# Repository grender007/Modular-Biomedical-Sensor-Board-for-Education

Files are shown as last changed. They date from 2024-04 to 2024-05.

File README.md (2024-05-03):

# Modular-Biomedical-Sensor-Board-for-Education (MediBrick-2000)
Modular Biomedical Sensor Board for Education (a.k.a. MediBrick-2000), designed for the Department of Biomedical Engineering (BME) of the University of Arizona (UofA). The device currently integrates five different sensor for physiological measurements:

* [Skin Impedance](https://github.com/grender007/Modular-Biomedical-Sensor-Board-for-Education/tree/main/Skin%20Impedance%20Sensor)

* [Temperature](https://github.com/grender007/Modular-Biomedical-Sensor-Board-for-Education/tree/main/Temperature%20Sensor)

* [ECG](https://github.com/grender007/Modular-Biomedical-Sensor-Board-for-Education/tree/main/ECG%20Sensor%20)

* [Pulse Ox ](https://github.com/grender007/Modular-Biomedical-Sensor-Board-for-Education/tree/main/Pulse%20Ox%20Sensor)

* [Digital Stethoscope](https://github.com/grender007/Modular-Biomedical-Sensor-Board-for-Education/tree/main/Sound%20Sensor)

Each one of the folders include the Arduino Code (that also enables wireless communication), the PCB files, and the corresponding insert for the casing.

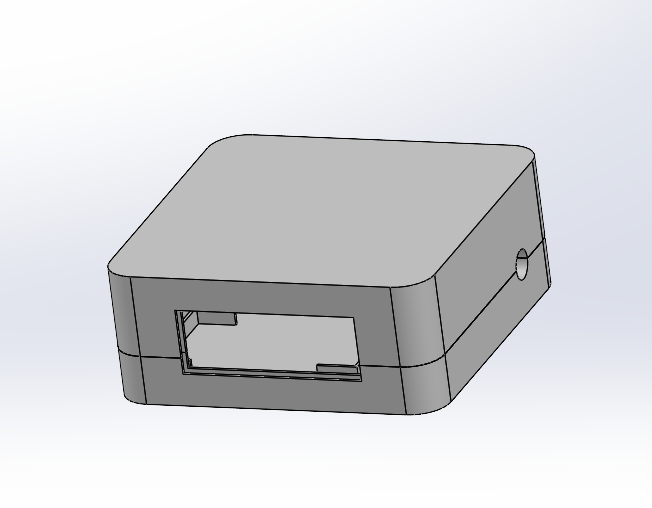
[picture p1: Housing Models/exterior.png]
alt exterior


# Project Point Design
This is a wireless device mainly supported by ESPNow. Each one of the sensors has its own PCB and its own ESP32-S3 (see Arduino Code in any of the sensor folders). The signals are sent to a sixth ESP32-S3, [the receiver](https://github.com/grender007/Modular-Biomedical-Sensor-Board-for-Education/tree/main/ESP32%20Receiver), that simultaneously communicates with the user's computer through the [GUI](https://github.com/grender007/Modular-Biomedical-Sensor-Board-for-Education/tree/main/GUI). The GUI displays the measurements in real time and allows the user to record and save the information.

When not in use, the sensors can be placed on the charging station, where the batteries can be recharged.

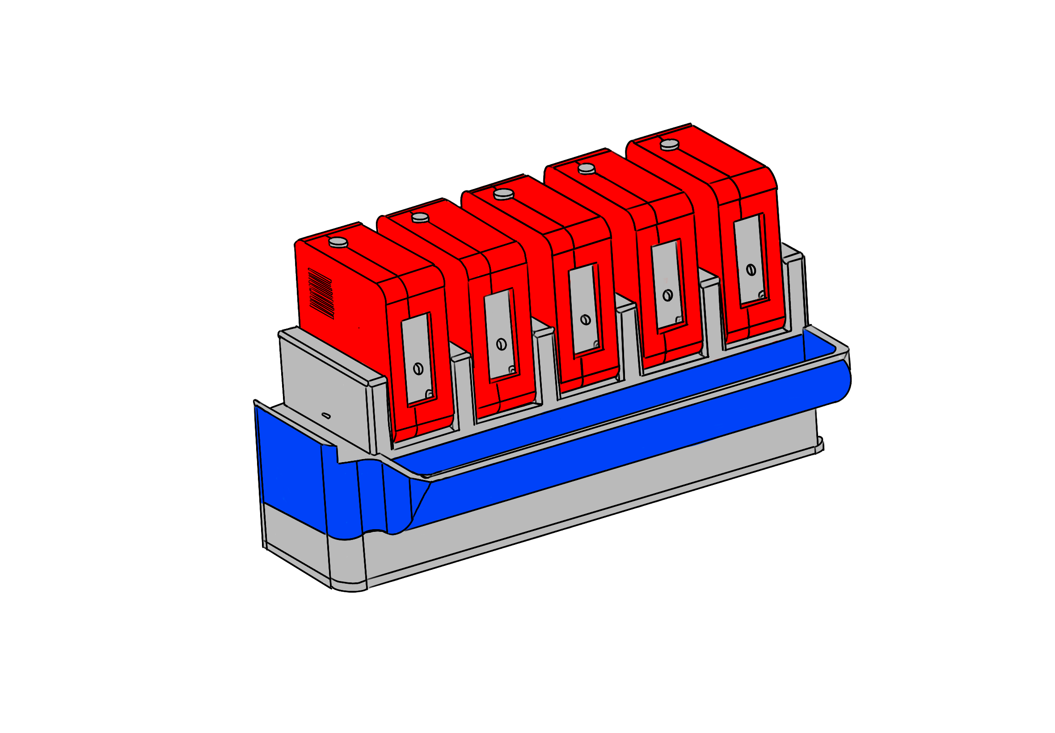
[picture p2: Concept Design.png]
alt Concept


# Sensor Modules
All the sensor modules are meant to be the same, being the only difference each sensor and the PCB that includes the required circuitry (But all the PCB have the same dimension and orientation). Each [sensor module](https://github.com/grender007/Modular-Biomedical-Sensor-Board-for-Education/tree/main/Housing%20Models/Module%20Casing) has different features. It includes an OLED screen that displays the current battery level and a button that allows the deep sleep mode of the ESP32-S3. The casing it is designed for the ESP32-S3 to be powered by a battery and to recharge with a magnetic plug.
All the modules can be placed on the [charging station](https://github.com/grender007/Modular-Biomedical-Sensor-Board-for-Education/tree/main/Housing%20Models/Charging%20Station) to recharge the batteries. Similarly, the receiver includes its own [casing](https://github.com/grender007/Modular-Biomedical-Sensor-Board-for-Education/tree/main/Housing%20Models/Receiver%20Casing).

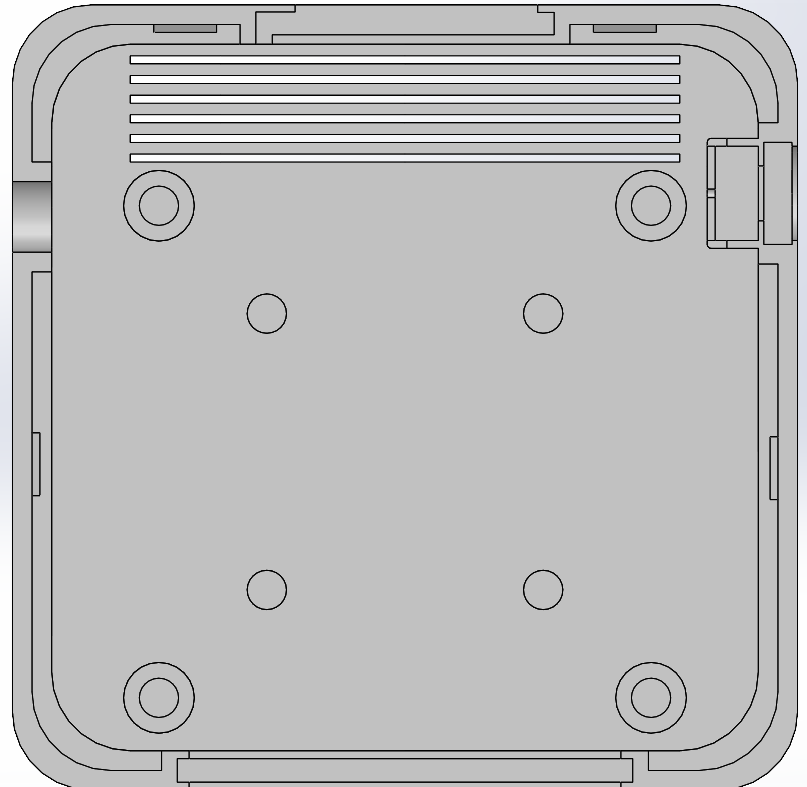
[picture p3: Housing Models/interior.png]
alt interior1


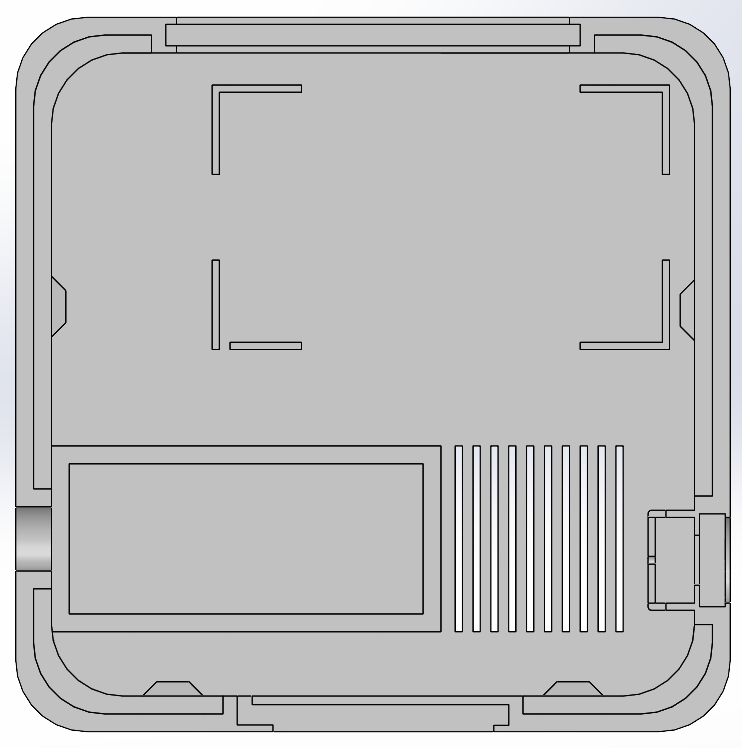
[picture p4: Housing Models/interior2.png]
alt interior2


# Assembly
The detailed asssembly process and the required parts for the device are described in the [Documents folder](https://github.com/grender007/Modular-Biomedical-Sensor-Board-for-Education/tree/main/User%20Manual%20and%20Other%20Documents), as well other related documents like the Technical Data Package (TDP).

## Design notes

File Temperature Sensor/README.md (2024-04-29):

The ESP32 measures the voltage difference from the PCB through Pins A0 and A1, then uses those values to calculate the resistance of the thermistor using Wheatstone Bridge equations. The code then calculates the temperature of the thermistor using the thermistor resistance and constants provided by the manufacturer. Because the thermistor is sensitive to subtle changes, the code then averages 100 of the readings together in order to filter out noise from the signal. The averaged reading is then sent to the receiver and to the OLED at 1 to 2 readings per second.

The code is also built to allow the module to be put into deepsleep, where holding the button on the side of the module for 5 seconds will turn the module off, preventing the module from reading, sending, or receiving data, but does allow the module to still be charged. Pressing the button again will wake the module from deepsleep.

The module can be calibrated using the GUI. Entering resistor values measured while building the device will allow for the sensor to be recalibrated. The sensor module will use the new resistor values until the module is turned off. New values can be sent at any time using the GUI.

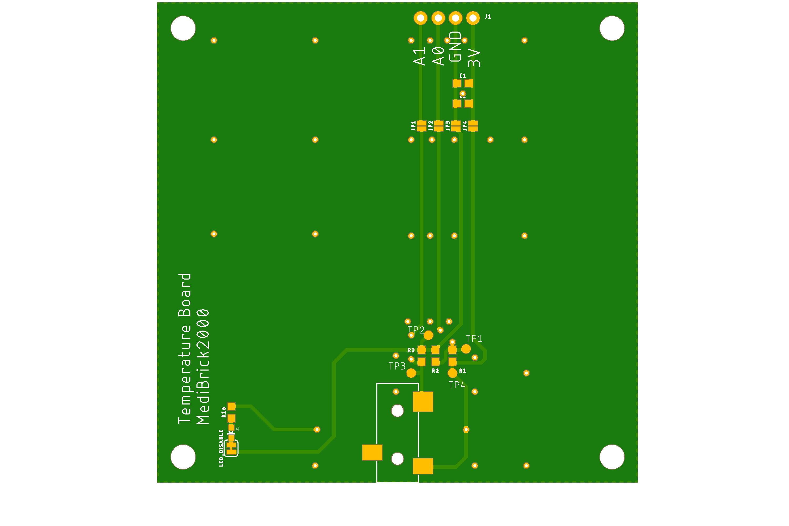
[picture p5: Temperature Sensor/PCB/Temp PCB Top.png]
alt Temp Sensor


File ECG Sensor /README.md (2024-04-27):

This is a description for ECG Sensor. See [Module Casing](https://github.com/grender007/Modular-Biomedical-Sensor-Board-for-Education/tree/main/Housing%20Models/Module%20Casing) for the entire casing design.

The ECG Module takes advantage of the Sparkfun ECG Pre-Amplifier Board. It uses the AD8232 IC to detect the voltage potential of the heart. 

output-onlinepngtools (6)

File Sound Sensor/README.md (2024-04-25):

The Sound Sensor module records the sounds of heartbeats and the lungs. The sensor (electret microphone) is connected to a stethoscope tube, so the user can mimic the functionalities of an "analog" stethoscope. 

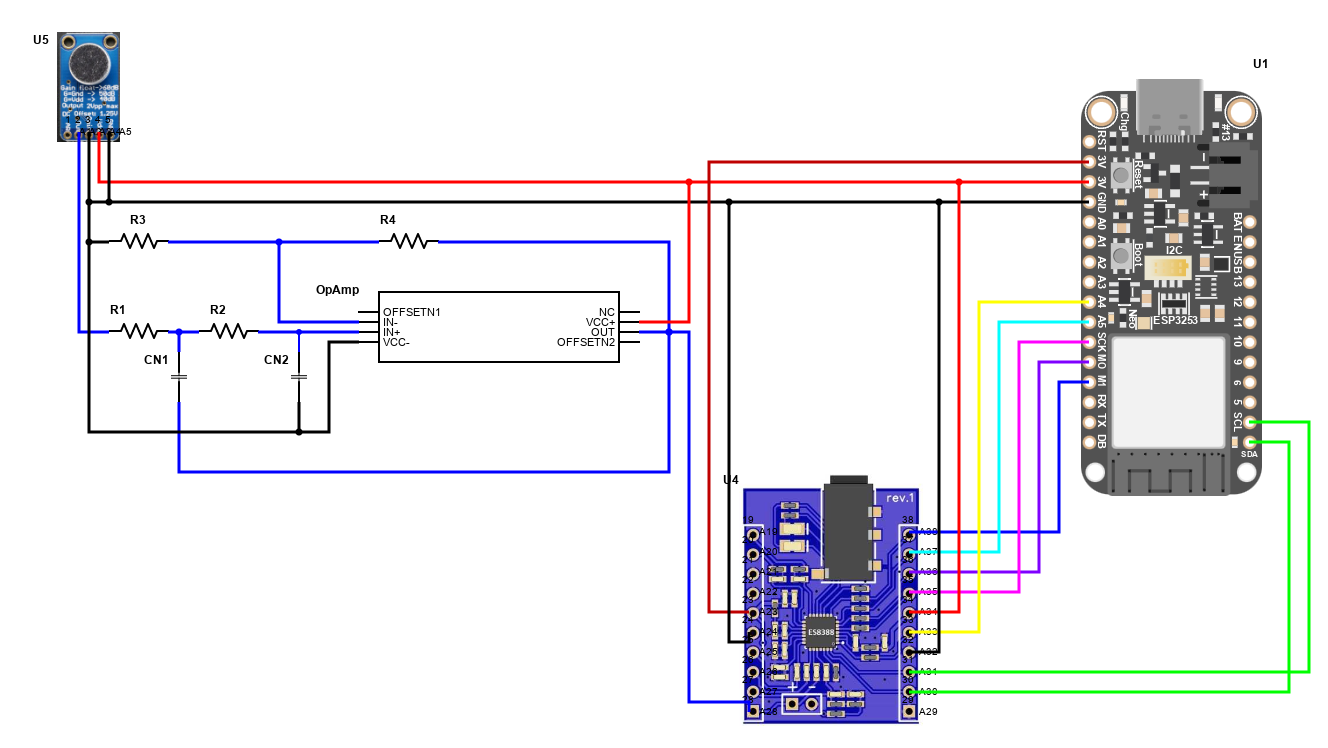
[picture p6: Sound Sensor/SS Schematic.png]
alt schematic


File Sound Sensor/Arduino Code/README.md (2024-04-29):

The ESP32 receives a stream of bits coming from the audio Codec, using the I2S communication protocol. The stream is filtered using a IIR BPF, and later sent to ESPNow (or just the serial monitor, if needed). Since the implementation of this code is different from the other sensors, we include the [receiver code](https://github.com/grender007/Modular-Biomedical-Sensor-Board-for-Education/blob/main/Sound%20Sensor/Arduino%20Code/Sound_receiver.ino), that allows to correctly receive the data with a secondary ESP32. 

Additionally, we included a [Filter Designer](https://github.com/grender007/Modular-Biomedical-Sensor-Board-for-Education/blob/main/Sound%20Sensor/Arduino%20Code/Filter_1.m), a very short and easy-to-use MATLAB file that helps to design an IIR filter of Nth order with a given cut-off frequency (or frequencies in case of BPF) and sampling frequency.

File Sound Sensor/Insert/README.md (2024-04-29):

This is the insert for the Sound Sensor Casing. See [Module Casing](https://github.com/grender007/Modular-Biomedical-Sensor-Board-for-Education/tree/main/Housing%20Models/Module%20Casing) for the entire casing design.

This insert is design to fit the [Plug](https://github.com/grender007/Modular-Biomedical-Sensor-Board-for-Education/tree/main/Sound%20Sensor/Plug%20for%20Stethoscope) that connects an electret microphone with a stethoscope tube.

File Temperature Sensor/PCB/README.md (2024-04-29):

The temperature PCB is the simplest PCB of this project. It opperates using a simple wheatstone bridge, a parallel circuit composed of two branches, each with two resistors on each branch. One resistor is a thermistor, a resistor whose resistance changes with the temperature, serving as the probe for the project. As the temperature and thus resistance of the probe changes, the reading between the resistors of both branches will change. This difference in voltage is measured by the ESP32 and is used to calculate the temperature of the thermistor.

The PCB is also outfitted with a Red LED, allowing the User to see when the PCB has power.

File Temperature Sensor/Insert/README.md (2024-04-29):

This is the insert for the Temperature Sensor Casing. See [Module Casing](https://github.com/grender007/Modular-Biomedical-Sensor-Board-for-Education/tree/main/Housing%20Models/Module%20Casing) for the entire casing design.

This insert is designed to allow the probe to connect to the PCB while protecting the circuitry inside the module from intrusion from object over 12.5 mm in diameter.

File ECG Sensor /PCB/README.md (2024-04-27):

Similar to the other sensors the ECG is a 70 mm x 70 mm board. This board was developed using EAGLE. The design is very simple. It has a slot that perfectly fits a Sparkfun ECG Pre-amplifier board. Pinholes are added to the walls of the board for easier wiring. This board also has an led as an indication of proper connection.

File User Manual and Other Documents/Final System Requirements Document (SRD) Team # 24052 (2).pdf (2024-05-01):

SRD #24052

System Requirements Document

Biomedical Sensor Board for Education

ENGR 498B - #24052

Project Leader: Maria Carmella Ocaya (Biomedical Engineer)

Project Procurement Leader: Muad Alsayar (Electrical Engineer)

Michael Chase Morrett (Biosystems Engineer)

Daniel Fabricio Campana Moscoso (Electrical Engineer)

William Alec Newman (Mechanical Engineer)

Sponsor: Urs Utzinger, PhD

Mentor: Steve Larimore

Revision #16

March 28, 2024

REVISION PAGE

REVISION# | REVISION DATE | REVISION DESCRIPTION | REVISED BY
1 | 09/25/23 | EDITED the overall format | Muad and Carmella
2 | 09/26/23 | EDITED the Background | Muad
3 | 09/29/23 | ADDED the System Requirements | Michael
4 | 09/29/23 | ADDED the ConOps | Daniel
5 | 10/01/23 | EDITED the Table of Contents and Revision Page | Carmella
6 | 10/02/23 | REVIEWED the whole document | Dr. Urs Utzinger
7 | 10/03/23 | REVIEWED the Expected Output and System Requirements | Daniel
8 | 10/03/23 | EDITED the ConOps and Stakeholders | Carmella
9 | 10/04/23 | REVIEWED the whole document | Team and Sponsor
10 | 10/05/23 | EDITED the System Block Diagram and Standards | Carmella
11 | 10/05/23 | EDITED the Performance Requirements | Daniel
12 | 10/05/23 | ADDED Notes and EDITED Verifications | Muad
13 | 10/05/23 | EDITED Requirements and Verifications | Michael
14 | 10/05/23 | REVIEWED the whole document, EDITED the Table of Contents, UPDATED the revision history | Carmella
15 | 10/19/23 | EDITED Requirements and Verifications | Daniel
16 | 03/28/24 | Changed the System Requirements | Michael

TABLE OF CONTENTS | Page No.

8.0 TEAM MEMBERS PRESENT DURING THE DEVELOPMENT OF THE SRD........ 17

### 1.0 INTRODUCTION AND SCOPE

### 1.1 BACKGROUND

This document contains the System Requirements Document for a Biomedical Sensor Board assigned by the University of Arizona’s Department of Biomedical Engineering and sponsored by Dr. Urs Utzinger. Dr. Utzinger is an associate professor of the University of Arizona in the departments of Biomedical Engineering, Obstetrics and Gynecology, Electrical and Computer Engineering, Optical Sciences, and BIO5. Some of his experiences include, but are not limited to, clinical imaging instrumentation to evaluate gynecological and gastrointestinal cancer, spectral imaging techniques for the skin, and development of hands-on training courses on electro mechanical systems for BME undergraduates.

The main goal of this project is to create a safe and fully functional sensor array for BME students to use in their laboratory sessions. This sensor board has five physiological sensors: temperature, impedance, electrocardiogram (ECG), sound, and pulse oximeter. With these five sensors, users can measure their body temperature, body fat percentage, water composition, heart electrical impulses, arterial blood oxygenation, heart rate, and heart and lung sounds. All five sensors are modular and will communicate using ESP-32 microcontrollers. Since this project is geared toward students, a beginner-friendly GUI will be developed along with this device. This GUI will allow users to measure using any of the five physiological sensors, and it will also allow users to record all the data collected by this device. The GUI will also provide a graphical representation along with the quantitative result according to the physiological measurement selected by the user.

### 1.2 NEED

The Department of Biomedical Engineering at the University of Arizona has grown significantly in recent years, resulting in an annual increase in the number of admitted students. Therefore, an affordable, accurate, and easy-to-use physiological sensor board is currently necessary for biomedical engineering teachers and students. At the time this project was developed, affordable and functional multi-physiological sensors were not currently available on the market. Although commercial systems are available, no unified approach uses existing third-party hardware, allows for later expansion, and uses open-source software.

### 1.3 CONCEPT OF OPERATIONS

### 1.3.1 SYSTEM BOUNDARIES

The system boundaries are divided into two categories: physical materials and software interface. For physical materials, each sensor will be separated into its own modules. Each module will have a power supply, a microcontroller, and a sensor board. There will be a total of five separate modules that will communicate to one receiver microcontroller. This receiver microcontroller will then communicate to the software interface. Users will be able to read, save, and display data from one or more sensors in their computers using this software interface.

### 1.3.2 SYSTEM ENVIRONMENT

The biomedical sensor array is intended for usage in laboratory, educational, and research environments, which are dry and room-temperature operating settings. The part of the sensors that interface with the human body will be water-resistant, chemically inert, and have no electrical connection to power lines. Furthermore, the whole system should be able to recharge within the environment when not in use.

### 1.3.3 SYSTEM CONSTRAINTS

Each sensor module with its own microcontroller shall have the same size. The complete sensor array shall cost less than $200, be easily replicated by senior-standing engineering students, and last three years of light use. Additionally, the system must be powered without being plugged into a wall outlet. As for the overall size, this device shall be no larger than a standard shoe box.

### 1.3.4 SYSTEM USE

The system will be used to collect physiological signals chosen by the user. The system will have a total of six microcontrollers, where one microcontroller is assigned for each of the five sensors. These microcontrollers will then wirelessly communicate with the designated sixth microcontroller, acting as a receiver, which will then communicate with the GUI within the user's personal computer.

Skin Impedance: Students will attach electrodes to two distinct, predetermined spots on a participant to measure the impedance between the two locations. Based on the user's body weight, the software will convert the recorded data to body fat and water content.

Electrocardiogram: Students will connect two electrodes to the right and left arm as well as right leg, as a ground reference, to measure electrical potential created by the beating heart.. The program will allow users to construct an ECG measurement chart. The program may incorporate a 60Hz noise suppression filter and a low pass filter to graphically show the QRS complex of the signal.

Blood Oxygenation: A typical nine-pin analog pulse oxygenation sensor will be used in this module. The sensor will connect to a participant's finger and use red and near-infrared LEDs to detect blood oxygenation. The software will allow users to view the resulting plethysmography data from the pulse oximeter sensor.

Sound: This sensor will be able to record heart sounds with the use of a stethoscope and microphone placed on the user’s chest. Recordings from this sensor will range from 5-10 seconds with the ability to playback using the GUI as well as save the created file. This sensor will also be able to listen to lung sounds.

Temperature: Students will be able to accurately monitor temperature orally or by placing it between their armpits. To measure the temperature, a medical thermistor will be utilized as a sensor. The software will offer temperature readings to the user.

### 1.3.5 EXPECTED OUTPUT

We hope to build a sensor array, composed of carefully selected sensors and well-designed integrated circuits, to measure biological data and provide graphical interpretations of the parameters obtained. The product will include a software application for personal computers, and will be capable of receiving, displaying, and storing data from the sensor array in response to human input. The project will be successful if the product provides enough instruction for students in the Department of Biomedical Engineering to integrate and operate the sensor.

### 1.4 STAKEHOLDERS

The project's stakeholders are the team members of Team #24052, the University of Arizona’s Department of Biomedical Engineering through the sponsor, Urs Utzinger, the College of Engineering, and the Senior Design Instructional Team. In addition, there are indirect stakeholders within the open-source community who are interested and enthusiasts in microcontrollers and single-board computers and their functionalities. Dr. Utzinger will act as the primary point of contact for the project, representing all other stakeholders and users. Given his expertise in sensor integration with microcontrollers and single-board computers, Dr. Utzinger will validate the device's functionality. The sponsor will be present during all system verification tests.

### 2.0 APPLICABLE DOCUMENTS

### 2.1 STANDARDS

- ISO 13485 Compliance - Medical Devices: This is the harmonized standard for the medical devices industry that contains a set of standard quality management systems that are internationally agreed upon. Due to the time restrictions of this project, the team will only focus on this standard’s risk management and design control during product development.
- IEC 60601-1: This standard contains the essential performance and basic safety requirements for medical-related electrical equipment. This ensures that no failures relating to, but not limited to, electrical, thermal, or function will cause an unacceptable risk to its users.
- 45 CFR 46: Also referred to as the “Common Rule”, this is the HHS standard for human subjects in research. This standard requires that all participants provide consent before getting tested, which in this case by the sensor board.
- IP 21: IP standards provide information relating to the ability of a system to be resistant to intrusion from objects and water.
- ACGIH: Organization that provides guidelines for the maximum concentration of chemicals in contact with an individual.

### 2.2 DATASHEETS

- ESP32-S3 Series Datasheet: https://www.espressif.com/sites/default/files/documentation/esp32-s3_datasheet_e n.pdf
- Single-Lead, Heart Rate Monitor Front End (AD8232): https://cdn.sparkfun.com/datasheets/Sensors/Biometric/AD8232.pdf
- 12-Bit Impedance Converter (AD5933): https://www.analog.com/media/en/technical-documentation/data-sheets/AD5933. pdf
- Biomedical Chip NTC Thermistors (MA100GG103AN): https://www.mouser.com/datasheet/2/18/Amphenol_04022020_AAS_920_321E-1 826352.pdf
- Integrated Analog Front-End for Pulse Oximeters (AFE4490RHAT): https://www.ti.com/lit/ds/symlink/afe4490.pdf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 om%252Fgeneral%252Fdocs%252Fsuppproductinfo.tsp%253FdistId%253D10% 2526gotoUrl%253Dhttps%253A%252F%252Fwww.ti.com%252Flit%252Fgpn% 252Fafe4490
- Low-Cost, Micropower, SC70/SOT23-8, Microphone Preamplifiers (MAX4466):
https://www.analog.com/media/en/technical-documentation/data-sheets/MAX446 5-MAX4469.pdf

### 3.0 DEFINITIONS, ACRONYMS, AND ABBREVIATIONS

BPM | Beats per minute
BME | Biomedical Engineer/ Engineering
CFR | The Code of Federal Regulations
DMM | Digital Multimeter
ECG | Electrocardiogram/Electrocardiography
FFT | Fast Fourier Transform
GUI | Graphical User Interface
HHS | Health and Human Services
HIPAA | Health Insurance Portability and Accountability Act
IEC | Internal Electrotechnical Commision
IP | Ingress Protection
ISO | International Organization for Standardization
SRD | System Requirements Document

### 4.0 REQUIREMENTS

### 4.1 SYSTEM BLOCK DIAGRAM

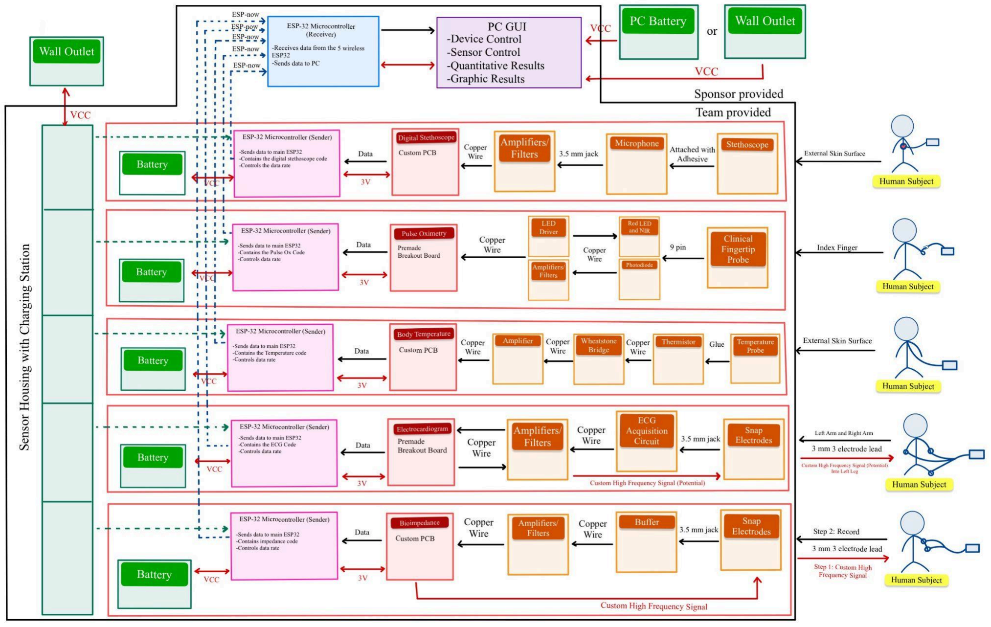
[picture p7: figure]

The team will be responsible for creating each sensor and integrating them into a modular wireless module. The team will also create a GUI for the device, as well as develop the housing with the device’s charging station. They will also be responsible for updating each member’s progress to the sponsor in the weekly meetings.

The sponsor, however, is responsible for providing necessary tools and equipment, such as 3D printers, soldering stations, electrical consumables, and last year’s leftover equipment. The sponsor is also responsible for providing feedback on the team’s plans and progress. Lastly, the sponsor is responsible for providing the team with any plans he would like to integrate into the device in a timely manner.

### 4.2 SYSTEM REQUIREMENTS

### 4.2.1 PERFORMANCE REQUIREMENTS

4.2.1.1 Temperature Sensor Range: The temperature sensor module shall measure temperature within the range of 20°C to 45°C.

4.2.1.2 Temperature Sensor Accuracy: The sensor shall return readings with an accuracy of 0.1°C of the true value.

4.2.1.3 Stethoscope Sensitivity: The digital stethoscope shall be able to detect the sound of a human heartbeat, estimated to have a frequency from 20-800 Hz.

4.2.1.4 Stethoscope Audio: The digital stethoscope audio shall sound similar to the audio produced through a typical medical-grade stethoscope.

4.2.1.5 Pulse Oximeter Signal Noise: The amplitude changes returned from the pulse oximeter shall be at least 15 dB.

4.2.1.6 Pulse Oximeter Heart Rate: The pulse oximeter module shall be able to return a BPM value from 50 to 180.

4.2.1.7 Skin Impedance Range: The measurable body fat percentage range shall be 5%- 40%, while the water composition range shall be 45%-80%.

4.2.1.8 Skin Impedance Accuracy: The skin impedance sensor shall be able to return a value for the water content of the subject that is within 5% of the true value of the body fat content.

4.2.1.9 Electrocardiogram Accuracy: The ECG sensor shall return a signal with the QRS-complex intact along with the P-wave and T-wave. In order to do so, it shall have a signal-to-noise ratio (SNR) of at least 10 and that the power at 60Hz (power line interference) is less than 10% of the total power.

### 4.2.2 ENVIRONMENT

4.2.2.1 IP Rating: The system shall be compliant with an IP rating of 20.

4.2.2.2 Operational Temperature: The board shall function within a temperature range of 10 to 40 degrees Celsius.

4.2.2.3 Operational Humidity: The system shall function in areas with Relative Humidity lower than 50%.

### 4.2.3 DESIGN FEATURES

4.2.3.1 Weight: The system shall not exceed 15 pounds in weight.

4.2.3.2 Dimensions: The system shall fit within a volume of a box with a 35.5-cm side, and 25.4-cm side, and a 20.7-cm side.

4.2.3.3 Inexpensive: The system’s final cost to manufacture one entire system shall not exceed $500.

4.2.3.4 Saved Data: The system will allow the user to save sensor readings as graphed data or in the case of the stethoscope, as an MP3 file.

4.2.3.5 Probe Chemical Resistance: Components exposed to the body fluids or exhaled gasses shall be able to withstand exposure to 70% isopropyl alcohol swabs.

### 4.2.4 SAFETY

4.2.4.1 Electrical Safety: The system shall not have any exposed electrical components.

4.2.4.2 Privacy Protection: Any reports generated from the board shall be compliant with HIPAA Privacy Rule, 45 CFR Part 160 Subparts A and E.

4.2.4.3 Maximum Bioimpedance Current: The electrodes connected to the skin for the bioimpedance sensor shall not exceed a maximum current of 10 μA.

4.2.4.4 Maximum ECG Current: The electrodes connected to the skin for the ECG sensor shall not exceed a maximum current of 10 μA.

4.2.4.5 Medical Device Standard: The system shall be compliant with IEC 60601-1.

4.2.4.6 Chemical Safety: Components in contact with the skin shall meet ACGIH TEL for surface chemical concentrations.

### 4.2.5 INTERFACES

4.2.5.1 Internal Power Supply: The auxiliary boards shall be able to perform their associated functions while only connected to internal battery sources without the aid of wall outlets for 3 hours.

4.2.5.2 Computer Communication: The main board must be able to communicate with the user’s computer.

4.2.5.3 GUI: The system shall have a GUI that the user can open on their computer to display data.

4.2.5.4 External Power Supply: The system shall be able to function when provided with 15 amp and 120 V AC.

### 5.0 VERIFICATION REQUIREMENTS

### 5.1 PERFORMANCE REQUIREMENTS

5.1.1 Temperature Sensor Range: Fill a container with water and allow it to come to room temperature, roughly 21°C. Place an accurate, pre-calibrated thermometer in the water. Place the temperature sensor into the water. Allow both to come to equilibrium. Verify the pre-calibrated thermometer reads roughly 21°C and verify that the temperature sensor also returns a reading of 21°C. Repeat this process by heating the container to roughly 45°C and repeating the process of allowing the sensors to come to equilibrium and comparing their reading to the expected temperature.

5.1.2 Temperature Sensor Accuracy: Fill a container with water and allow it to come to room temperature, roughly 21°C. Place an accurate thermometer and the temperature sensor into the water and allow both to come to equilibrium. Note the values of both thermometers. Heat the water by roughly 5°C and repeat the measurements. Repeat this process until temperature measurements have been taken for 45°C. Verify that each temperature reading from the temperature sensor is within 0.1°C of the thermometer-measured values.

5.1.3 Stethoscope Sensitivity: Place the sensor probe on the chest over the heart of a healthy human adult. Verify that the digital stethoscope plays the audio of the heartbeat within a range of frequencies (20 Hz to 800 Hz).

5.1.4 Stethoscope Audio: Record sound through the digital stethoscope and analyze sound signals. Using signal processing software and FFT, compare the spectrum of the signal from the digital stethoscope to online stethoscope sound spectrums.

5.1.5 Pulse Oximeter Signal Noise: Connect the pulse oximeter to an individual and take measurements. Measure the amplitude of the noise in comparison to the desired signal and ensure the signal has an amplitude of at least 15 dB greater than the noise.

5.1.6 Pulse Oximeter Heart Rate: The pulse oximeter sensor shall be able to measure an individual's BPM under particular settings. The first shall need the subject to sit quiet and breathe deeply in order to reduce their heart rate. The second shall require the subject to perform one minute of jumping jacks. Both measurements must accord with those of a pre-built pulse oximeter.

5.1.7 Skin Impedance Range: Gather individuals with different physiques and test our device. Collect data and calculate the ranges.

5.1.8 Skin Impedance Accuracy: Rent an impedance device from the University of Arizona’s Sensor Lab and compare both devices’ outputs. If there are no impedance devices available, check whether any of the three recreational centers at the University of Arizona have any electronic scales with an impedance sensor.

5.1.9 Electrocardiogram Accuracy: Rent an ECG sensor from the University of Arizona’s Sensor Lab and compare both devices’ outputs. If an ECG is unavailable, gather a group of people and collect their data using the ECG sensor for this project. Find normal ECG results from the web and compare them with the collected data.

### 5.2 ENVIRONMENT

5.2.1 IP Rating: Place the system flat onto a surface, disconnected from any sources of power. Inspect the system to ensure that hands and fingers are unable to come into contact with exposed electrical components or can enter the internal volume of the system.

5.2.2 Operational Temperature: Place the system within a container cooled to roughly 10°C and allow the system to come to equilibrium. Verify the temperature of the system using an accurate thermometer. Operate the system, ensuring that all systems work within tolerances. Place the system within a container heated to roughly 40°C and repeat all steps to ensure the system works within tolerances.

5.2.3 Operational Humidity: Place the system within a container humidified to roughly 50% relative humidity. Verify that the system components work within tolerances.

### 5.3 DESIGN FEATURES

5.3.1 Weight: Place the system onto a scale and verify the total weight of the system is less than 15 pounds.

5.3.2 Dimensions: Using a tape measure, measure the length, width, and height of the system and verify that the system is less than or equal to 35.5 cm on one side, 25.4 cm on one side, and 20.7 cm on one side.

5.3.3 Inexpensive: Analyze the costs of parts and labor to verify the total cost of the system is less than $500.

5.3.4 Saved Data: Ask the system to export its saved data to the user’s computer and open the data on the computer.

5.3.5 Probe Chemical Resistance: Place into a beaker 100 mL of 70% isopropyl alcohol. Place the sensor probe into the solution. After 1 hour, remove the probe and inspect the probe for degradation. Activate the sensor probe and verify that the probe still reports normal values.

### 5.4 SAFETY

5.4.1 Electrical Safety: Inspect the system to ensure that the user does not have access to exposed electrical components without dismantling the system.

5.4.2 Privacy Protection: Inspect the GUI and saved data to ensure that identifying data, such as the user’s name is not asked for or used.

5.4.3 Maximum Bioimpedance Current: Attach the electrodes of the bioimpedance module to a DMM and verify the output is less than 10 μA.

5.4.4 Maximum ECG Current: Attach the electrodes of the ECG module to a DMM and verify the output is less than 10 μA.

5.4.5 Medical Device Standard: Inspect all aspects of sensors to ensure they meet IEC 60601-1.

5.4.6 Chemical Safety: Demonstrate the system can be used within parameters set by ACGIH.

### 5.5 INTERFACES

5.5.1 Internal Power Supply: Measure the amperage of each auxiliary board using a DMM and compare the amperage to the amp hour rating of the battery used. To demonstrate battery life, activate each auxiliary board and enable measurements to be taken. Ensure that each board is active for at least 3 hours.

5.5.2 Computer Communication: Open the GUI on the user’s laptop and receive data.

5.5.3 GUI: Open the GUI on the user’s laptop and observe that measurements are being displayed.

5.5.4 External Power Supply: Analyze the voltage requirements of the components to ensure the system can function with the provided power.

### 6.0 SYSTEM REQUIREMENTS VERIFICATION MATRIX (SRVM)

Verification Method
T = Test
A = Analysis
D = Demonstration

| I = Inspection
Requirements | T | A | D | I

4.2.1 Performance

4.2.1.1: Temperature Sensor Range | X
4.2.1.2: Temperature Sensor Accuracy | X
4.2.1.3: Stethoscope Sensitivity | X | X
4.2.1.4: Stethoscope Audio | | | X
4.2.1.5: Pulse Oximeter Signal Noise | X | X
4.2.1.6: Pulse Oximeter Heart Rate | X
4.2.1.7: Skin Impedance Range | X
4.2.1.8: Skin Impedance Accuracy | X
4.2.1.9: Electrocardiogram Accuracy | X | | X

4.2.2 Environment

4.2.2.1: IP Rating | X
4.2.2.2: Operational Temperature | | | X
4.2.2.3: Operational Humidity | | | X

4.2.3 Design Features

4.2.3.1: Weight | | X | | X
4.2.3.2: Dimensions | | X | | X
4.2.3.3: Inexpensive | | X
4.2.3.4: Saved Data | | | X
4.2.3.5: Probe Chemical Resistance | X

4.2.4 Safety

4.2.4.1: Electrical Safety | | | | X
4.2.4.2: Privacy Protection | | | | X

4.2.4.3: Maximum Bioimpedance Current | | | | X
4.2.4.4: Maximum ECG Current | | | | X
4.2.4.5: Medical Device Standard | | | | X
4.2.4.6: Chemical Safety | | | X

4.2.5 Interfaces

4.2.5.1: Internal Power Supply | X | X
4.2.5.2: Computer Communication | | | X
4.2.5.3: GUI | | | X
4.2.5.4: External Power Supply | | X

### 7.0 NOTES

### 7.1 INEXPENSIVE / PROVIDED COMPONENTS FOR THE PROJECT

These components will not be part of our spent budget due to them being provided by the EDC and sponsor with no additional costs:

- Electrical Components:
1. Copper wires
2. Resistors
3. Capacitors
4. Inductors
5. ECG wires
6. Provided Impedance converters
7. Pins
8. 9 pin medical grade pulse ox sensor
9. 9 pin rs232
- Cleaning components:
1. Ethanol 70%
2. Isopropyl Alcohol 99%
3. Electronic components cleaner
- Electrical connections and prototyping:
1. Breadboards
2. Solder
3. Flux
4. 3D printing filament

There are other components that are provided by the sponsor from the previous year's team that we may utilize in our project.

### 7.2 PCB MANUFACTURING

Our PCBs will be manufactured and assembled collaboratively with (PCBWAY) to fulfill a project constraint regarding ease of reproduction and in house maintenance while still keeping costs at a minimum.

### 8.0 TEAM MEMBERS PRESENT DURING THE DEVELOPMENT OF THE SRD

- Maria Carmella Ocaya - Biomedical Engineer
- Muad Alsayar - Electrical Engineer
- Michael Chase Morrett - Biosystems Engineer
- Daniel Fabricio Campana Moscoso - Electrical Engineer
- William Alec Newman - Mechanical Engineer

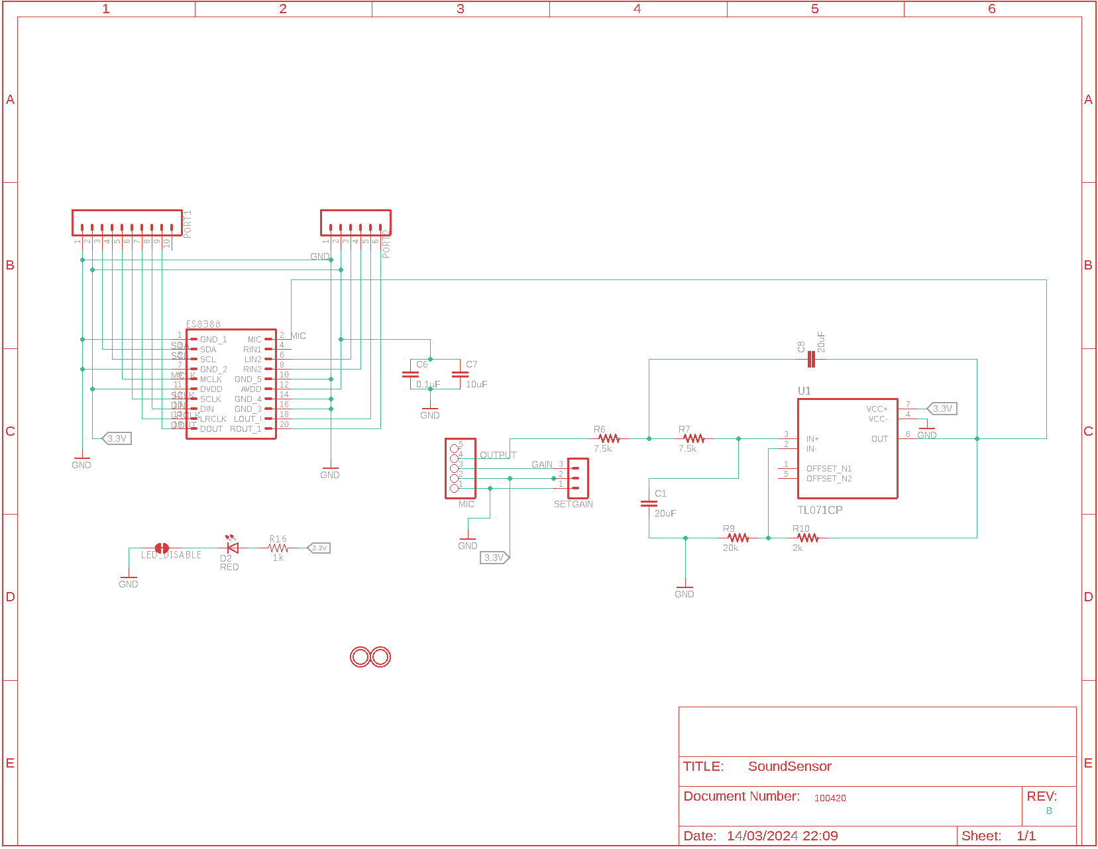
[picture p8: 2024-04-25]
Sound Sensor/PCB/SoundSensorSchematic.png

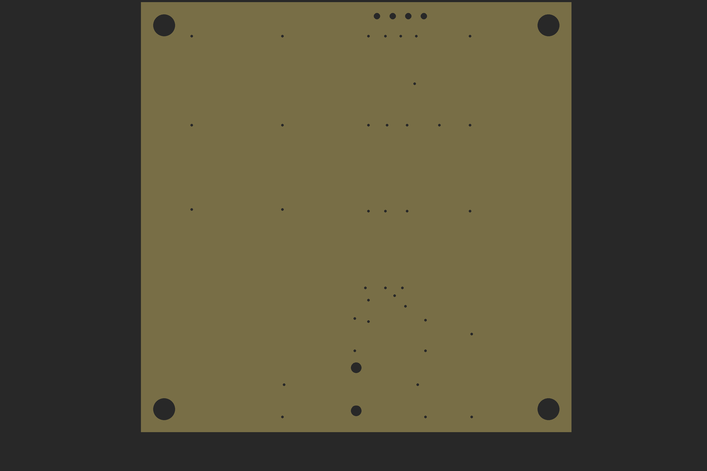
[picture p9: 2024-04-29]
Temperature Sensor/PCB/Temp PCB Drills.png

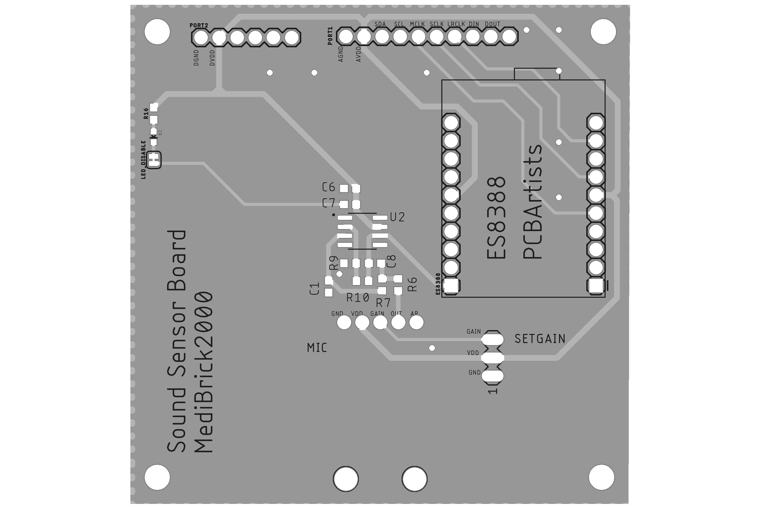
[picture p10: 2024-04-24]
Sound Sensor/PCB/SoundSensorTop.png

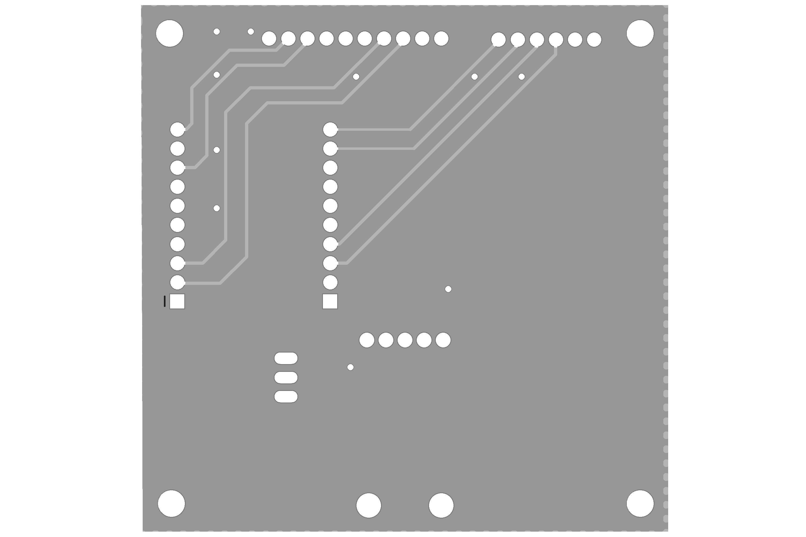
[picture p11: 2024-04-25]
Sound Sensor/PCB/SoundSensorBottom.png

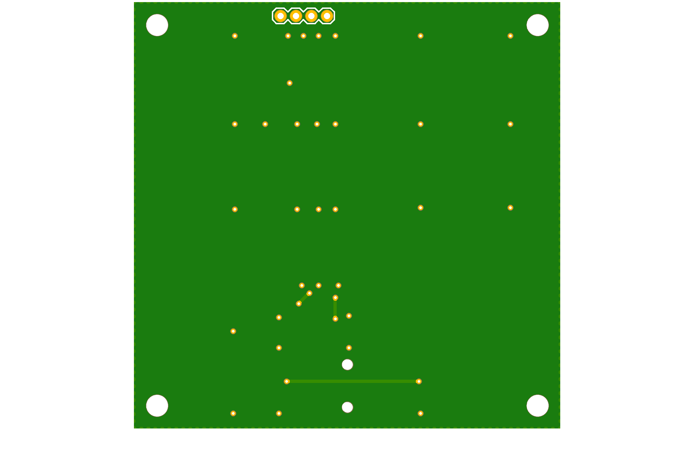
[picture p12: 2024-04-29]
Temperature Sensor/PCB/Temp PCB Bottom.png

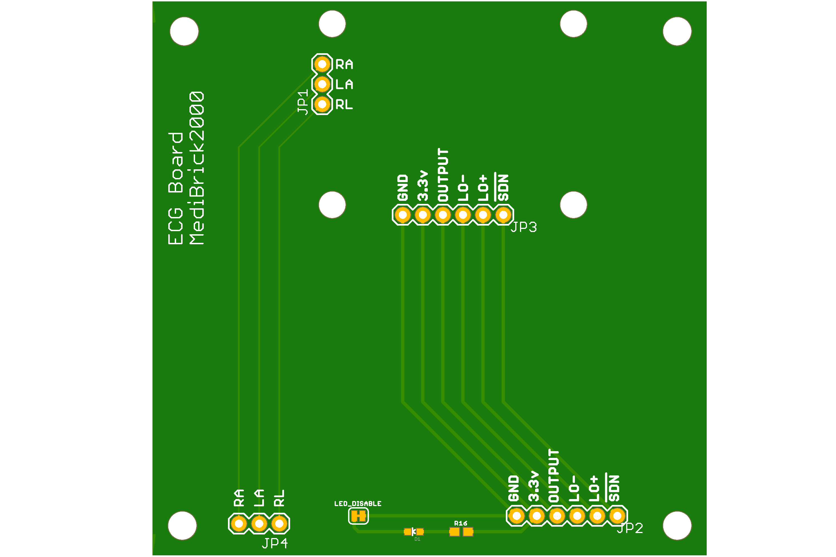
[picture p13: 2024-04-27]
ECG Sensor /PCB/ECG 7 by 7 w light.png

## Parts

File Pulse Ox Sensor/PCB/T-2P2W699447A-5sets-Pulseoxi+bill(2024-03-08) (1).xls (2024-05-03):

PCBWay Bom Quotation, Product No.:T-2P2W699447A
Item # | *Designator | *Qty | Manufacturer | *Mfg Part # | Description / Value | Vendor Part # | *Package/Footprint | Mounting Type | Your Instructions / Notes | *Unit Price(5 sets) | *Total | *Delivery Time | *Actual Purchase Mfg Part # | *PCBWay Note | Customer Reply | PCBWay Update
1 | C1,C12,C13,C14,C2,C5 | 6 | Murata Electronics | GRM188R72A104KA35J | 10uF | GRM188R72A104KA35J lcsc#(C3011705) | 0603 | SMD | LCSC 100V 100nF X7R ±10% 0603 Multilayer Ceramic Capacitors MLCC - SMD/SMT ROHS | $0.048 | $1.440 |  | CL10A106MA8NRNC | 10uF 25V 0603 | yes confirmed
2 | C10,C9 | 2 | Murata Electronics | GQM1875C2E180JB12D | 18Pf | GQM1875C2E180JB12D lcsc#(C426071) | 0603 | SMD | LCSC 250V 18pF C0G ±5% 0603 Multilayer Ceramic Capacitors MLCC - SMD/SMT ROHS | $0.615 | $6.150
3 | C11 | 1 | Murata Electronics | GRM188R71H104KA93D | 100nF | GRM188R71H104KA93D LCSC Part #C77055 | 0603 | SMD | 50V 100nF X7R ±10% 0603 Multilayer Ceramic Capacitors MLCC - SMD/SMT ROHS | $0.098 | $0.490
4 | C15,C6 | 2 | Murata Electronics | GRM188R61E225KA12D | 2.2uF | GRM188R61E225KA12D LCSC Part #C77047 | 0603 | SMD | 25V 2.2uF X5R ±10% 0603 Multilayer Ceramic Capacitors MLCC - SMD/SMT ROHS | $0.085 | $0.850
5 | C3 | 1 | Murata Electronics | GRM188R61E105KA12D | 1uF | GRM188R61E105KA12D LCSC Part #C77046 | 0603 | SMD | 25V 1uF X5R ±10% 0603 Multilayer Ceramic Capacitors MLCC - SMD/SMT ROHS | $0.128 | $0.640
6 | C4,C7,C8 | 3 | Murata Electronics | GRM188R61E105KA12D | 0.1uF | GRM188R61E105KA12D | 0603 | SMD | 25V 1uF X5R ±10% 0603 Multilayer Ceramic Capacitors MLCC - SMD/SMT ROHS | $0.022 | $0.330 |  | CL10B104KB8NNNC | 0.1uF 50V 0603 | yes confirmed
7 | D1 | 1 | YONGYUTAI | YLED0603R | RED LED | YLED0603R LCSC Part #C19171390 | 0603 | SMD | 25mA -40℃~+85℃ 620nm~625nm Red 1.8V~2.4V 0603 Light Emitting Diodes (LED) ROHS | $0.138 | $0.690
8 | D4,D6,D7,D8 | 4 | Diodes Incorporated | BAV99W-7-F | Schottky Barrier Diodes | BAV99W-7-F LCSC#(C93035) | SOT-323 | SMD | 75V 200mW Dual 1.25V@150mA 4ns 150mA SOT-323 Switching Diode ROHS | $0.166 | $3.320
9 | IC1 | 1 | Texas Instruments | AFE4490RHAR | Analog Front End (AFEs) | AFE4490RHAR Mouser #:595-AFE4490RHAR | VQFN-40 | SMD | Analog Front End - AFE Integrated AFE for Pulse Oximeters | $5.997 | $29.985
10 | L1,L2,L3,L4 | 4 | Taiyo Yuden | LBC3225T100KR | INDUCTOR 10uH | LBC3225T100KR LCSC Part #C223424 | 1210 | SMD | 540mA 10uH ±10% 1210 Power Inductors ROHS | $0.203 | $4.060
11 | R1,R16 | 2 | Milliohm | HoAR0603-1/10W-1KR-0.1%-TCR25 | 1kohm | HoAR0603-1/10W-1KR-0.1%-TCR25 LCSC Part #C5123583 | 0603 | SMD | 1kΩ ±0.1% ±25ppm/℃ 100mW Ceramic resistor 0603 Chip Resistor - Surface Mount ROHS | $0.178 | $1.780
12 | R10,R11,R12,R13,R2,R3,R5,R6,R7,R8,R9 | 11 | Ever Ohms Tech | TR0603B10R0P0525Z | 10ohm | TR0603B10R0P0525Z LCSC Part #C3202454 | 0603 | SMD | ±0.1% 10Ω ±25ppm/℃ Thin Film Resistor 0603 Chip Resistor - Surface Mount ROHS | $0.047 | $2.585
13 | U$11 | 1 | Abracon LLC | ABM3-8.000MHZ-D2Y-T | Ocillator | ABM3-8.000MHZ-D2Y-T LCSC (C144380) | 5032 | SMD | 8MHz 贴片晶振 18pF ±20ppm ±30ppm SMD5032-2P Crystals ROHS | $0.891 | $4.455 | 7-10 Workdays
14 | X2 | 1 | TE Connectivity AMP Connectors | 2301843-1 | DB9 CONNECTOR | 2301843-1 (DigiKey Part NumberA132510-ND ) | Tray | Throughole | 9 Position D-Sub Plug, Male Pins Connector |  |  |  |  | [DNP不要贴];
15 | SV1 | 1 | Sullins Connector Solutions | PRPC020SACN-RC |  | PRPC020SACN-RC (DigiKey Part Number S1131EC-20-ND ) |  | Throughole |  |  |  |  |  | [DNP不要贴];
 |  |  |  |  |  |  |  |  |  | Component Cost | $56.77
 |  |  |  |  |  |  |  |  |  | Assembly Cost | $30.00
 |  |  |  |  |  |  |  |  |  | PCB Cost | $5.00
 |  |  |  |  |  |  |  |  |  | V0 Member 0% off | $0.00
 |  |  |  |  |  |  |  |  |  | All Total 5 Sets | $91.78

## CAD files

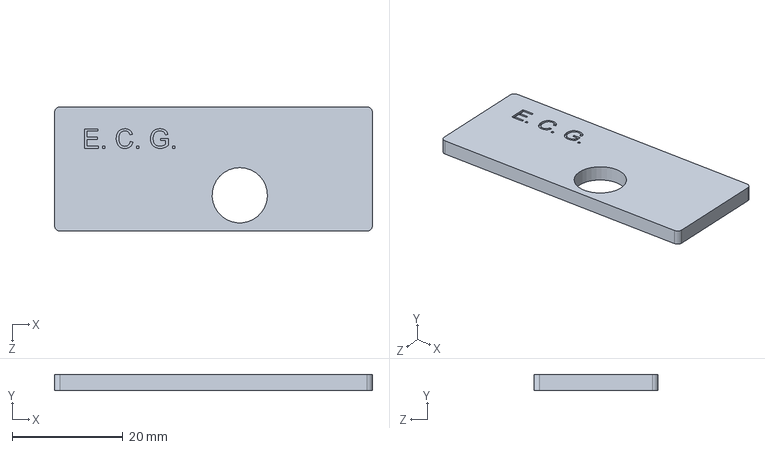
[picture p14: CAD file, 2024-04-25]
ECG Sensor /Insert/Part 100750.SLDPRT
57.5 x 2.90 x 22.5 mm

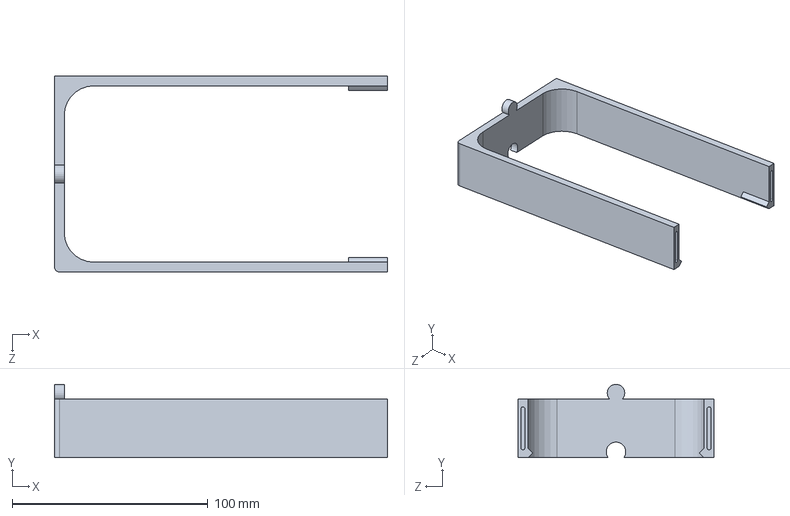
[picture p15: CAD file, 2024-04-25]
Housing Models/Charging Station/Part 100251 Surpise Addon.SLDPRT
170.0 x 37.5 x 100.0 mm

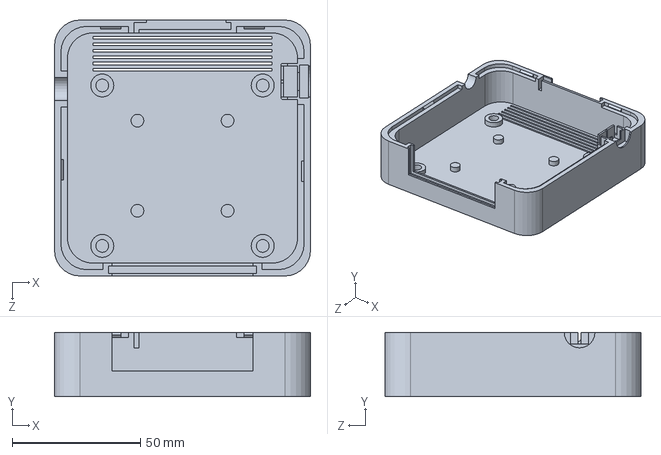
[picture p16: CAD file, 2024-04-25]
Housing Models/Module Casing/Part 100220_mk3.SLDPRT
100.0 x 25.0 x 100.0 mm

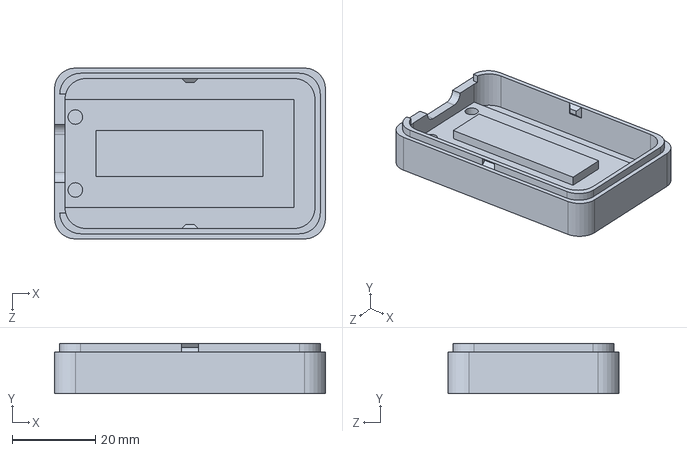
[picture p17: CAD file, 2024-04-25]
Housing Models/Receiver Casing/Part 100230.SLDPRT
65.0 x 12.0 x 41.0 mm

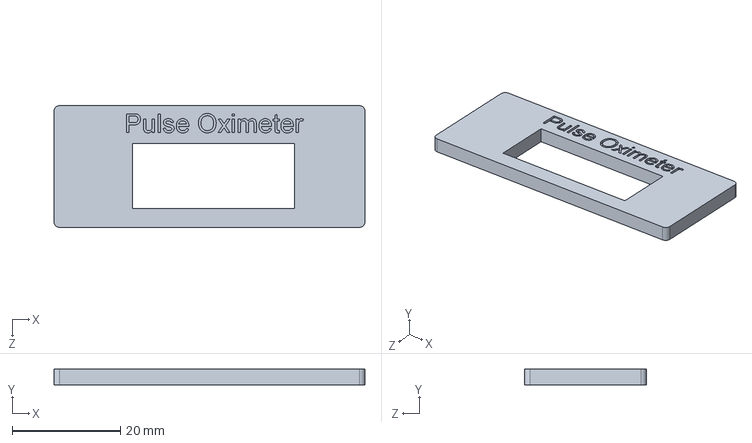
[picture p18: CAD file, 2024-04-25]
Pulse Ox Sensor/Insert/Part 100540.SLDPRT
57.5 x 2.90 x 22.5 mm

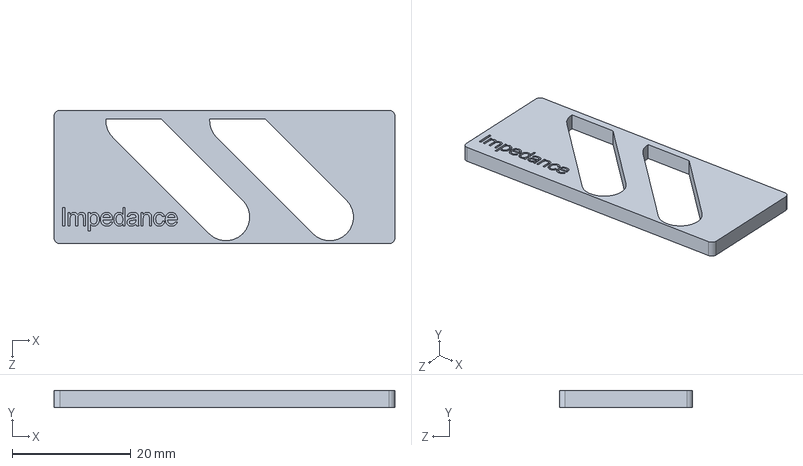
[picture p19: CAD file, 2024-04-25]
Skin Impedance Sensor/Insert/Part 100660.SLDPRT
57.5 x 2.90 x 22.5 mm

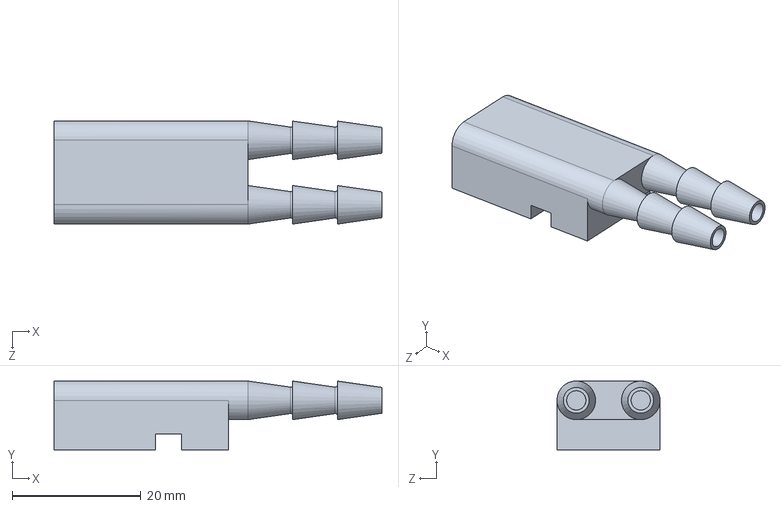
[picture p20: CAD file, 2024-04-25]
Sound Sensor/Plug for Stethoscope/Part 100450.SLDPRT
50.9 x 10.7 x 16.0 mm

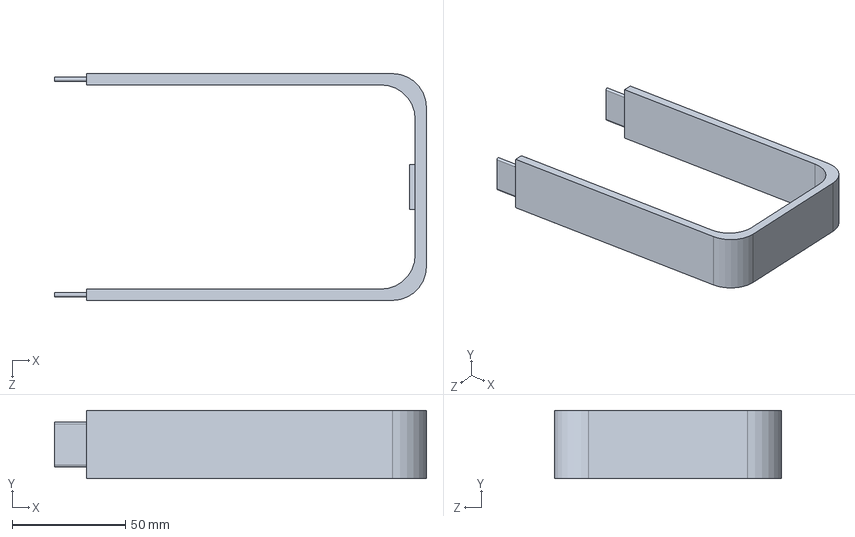
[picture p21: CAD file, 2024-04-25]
Housing Models/Charging Station/Part 100252 Surpise Addon.SLDPRT
164.0 x 30.0 x 100.0 mm

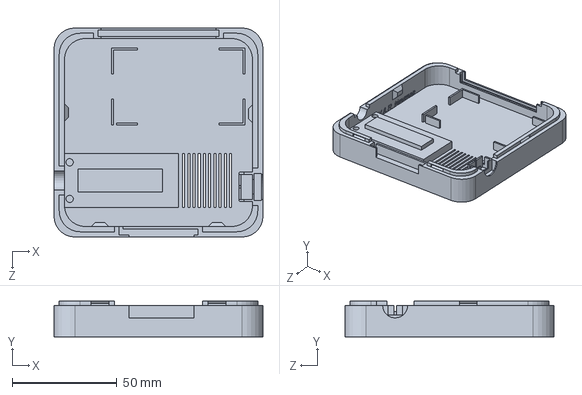
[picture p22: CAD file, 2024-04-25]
Housing Models/Module Casing/Part 100210_mk2.SLDPRT
100.0 x 17.0 x 100.0 mm

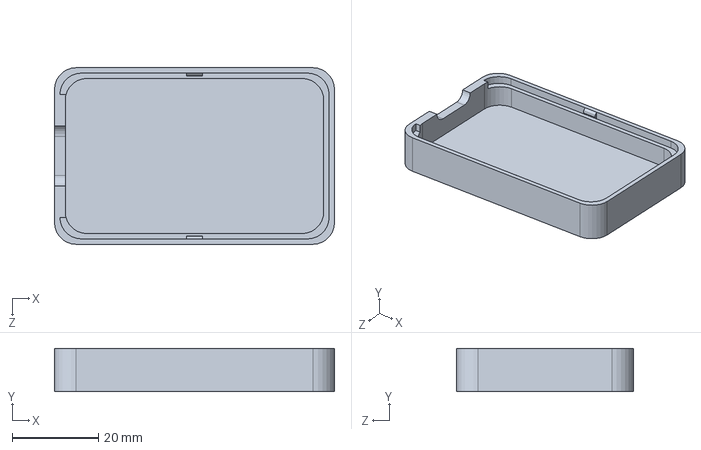
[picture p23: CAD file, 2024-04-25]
Housing Models/Receiver Casing/Part 100240.SLDPRT
65.0 x 10.0 x 41.0 mm

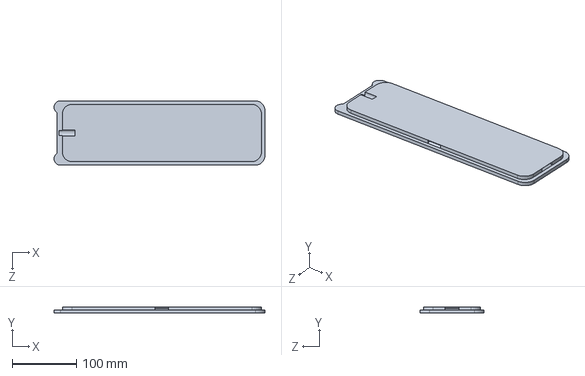
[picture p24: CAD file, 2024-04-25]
Housing Models/Charging Station/Part 100260.SLDPRT
327.5 x 10.0 x 100.0 mm

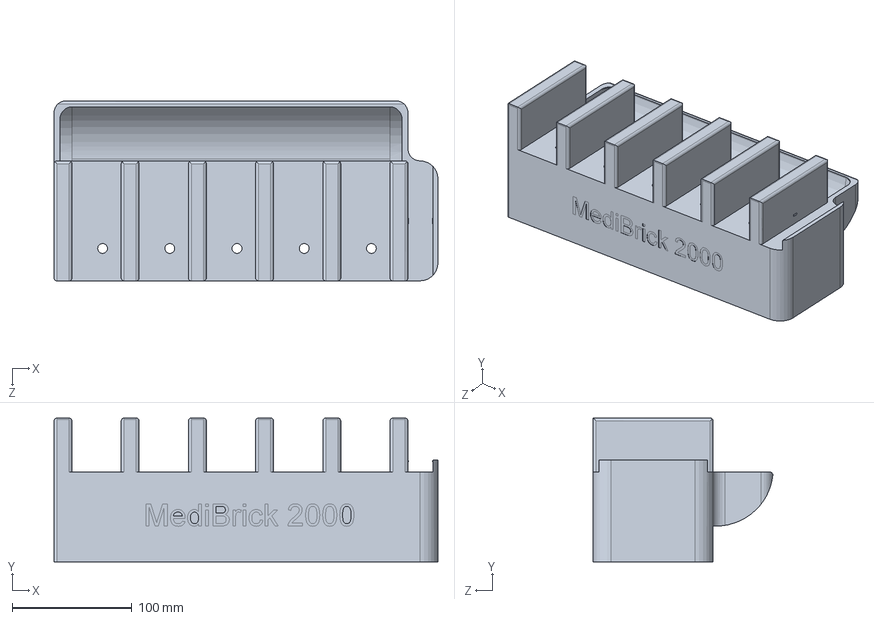
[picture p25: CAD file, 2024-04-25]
Housing Models/Charging Station/Part 100250.SLDPRT
320.0 x 120.0 x 149.8 mm

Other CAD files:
Sound Sensor/Insert/Part 100460.SLDPRT
Temperature Sensor/Insert/Part 100340.SLDPRT
ECG Sensor /Insert/Part 100750.STL
Housing Models/Charging Station/Part 100250.STL
Housing Models/Charging Station/Part 100251 Surpise Addon.STL
Housing Models/Charging Station/Part 100252 Surpise Addon.STL
Housing Models/Charging Station/Part 100260.STL
Housing Models/Module Casing/Part 100210_mk2.STL
Housing Models/Module Casing/Part 100220_mk3.STL
Housing Models/Receiver Casing/Part 100230.STL
Housing Models/Receiver Casing/Part 100240.STL
Pulse Ox Sensor/Insert/Part 100540.STL
Skin Impedance Sensor/Insert/Part 100660.STL
Sound Sensor/Insert/Part 100460.STL
Sound Sensor/Plug for Stethoscope/Part 100450.STL
Temperature Sensor/Insert/Part 100340.STL

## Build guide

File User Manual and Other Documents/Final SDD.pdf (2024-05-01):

### SDD #24052

### Software Design Document

### Biomedical Sensor Board for Education - MediBrick 2000

### ENGR 498B - #24052

### Project Leader: Maria Carmella Ocaya (Biomedical Engineer)

### Project Procurement Leader: Muad Alsayar (Electrical Engineer)

### Michael Chase Morrett (Biosystems Engineer)

### Daniel Fabricio Campana Moscoso (Electrical Engineer)

### William Alec Newman (Mechanical Engineer)

### Sponsor: Urs Utzinger, PhD

### Mentor: Steve Larimore

### Revision #10

### REVISION PAGE

REVISION# | REVISION DATE | REVISION DESCRIPTION | REVISED BY
1 | 10/17/2023 | Created and setup the document | Carmella Ocaya
2 | 1/17/2024 | Added multiple sections | Carmella Ocaya
3 | 3/30/2024 | Edited figure 1 | Carmella Ocaya
4 | 3/31/2024 | Updated Sound Sensor Code | Daniel Campana
5 | 3/31/2024 | Added the impedance code | Carmella Ocaya
6 | 4/30/2024 | Updated all the sensor codes (Addresses, clean up) | Carmella Ocaya
7 | 4/30/2024 | Updated the CSCI Diagram | Carmella Ocaya
8 | 4/30/2024 | Updated the STATUS Section | Carmella Ocaya
9 | 4/30/2024 | Update Sound Sensor Code Descriptions | Daniel Campana
10 | 4/30/2024 | Finalized Details | Carmella Ocaya

TABLE OF CONTENTS | Page No.

### 1.0 SCOPE

### 1.1 IDENTIFICATION

### The Biomedical Sensor Board (MediBrick 2000) is a sensor board array that measures

live physiological signals. This device is an expandable, low-cost, open-design system for anyone who is a senior-standing engineering student and above with soldering and 3D modeling experiences to be able to replicate and repair. This device is designed for laboratory settings to create an educational system for students to learn about these physiological signals. These signals are temperature, electrocardiography, heart and lung sounds, body fat percentage, water composition, heart rate, and plethysmograph. This device aims for the user to learn how to read, interpret, and manipulate the resulting signals.

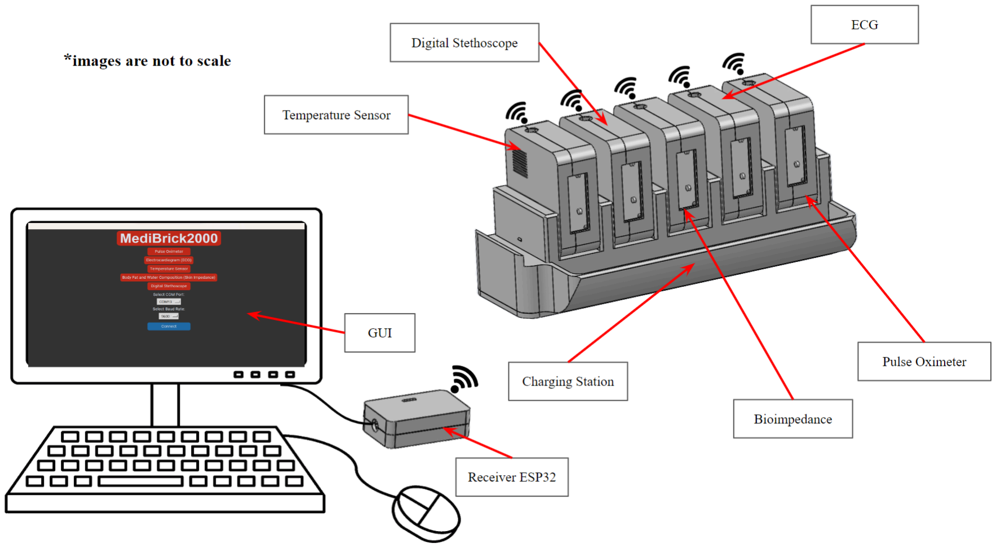
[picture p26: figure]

Figure 1. MediBrick Concept Design

### 1.2 SYSTEM OVERVIEW

### The sensors that are carefully chosen to achieve these physiological signals are the AD5933 (Impedance Sensor), AD8232 (ECG Sensor), 527-MA100GG103AN (Temperature Sensor), AFE4490 (Pulse Oximeter), and MAX9814 (Microphone for sound). The sensors will

have individual ESP32-S3 Feather microcontrollers to utilize the ESP's capability of performing wireless communication. These sensors will send their signal readings to a separate ESP32-S3 Feather which is connected to the user’s computer. The user will then control the received data using a graphical user interface (GUI). The GUI will have multiple abilities such as live graphs, screen capture, and saving options in Excel.

### 1.3 DOCUMENT OVERVIEW

The Software Design Document describes the purpose, functionality, architecture,

### interfaces, libraries, protocols, and assembly of the MediBrick 2000. This includes the specifications of the ESP32-S3 Feather, the Arduino codes for each sensor, the wireless

communication protocol, the Python Code for the GUI, the battery and OLED system, and more. This document will also cover the aspects regarding safety and privacy requirements since this device involves the recording of health-related information.

### 2.0 REFERENCED DOCUMENTS

### - ESP32-S3 Feather Datasheet: https://cdn-learn.adafruit.com/downloads/pdf/adafruit-esp32-s3-feather.pdf

### - ESP-NOW Protocol: https://www.espressif.com/en/solutions/low-power-solutions/esp-now#:~:text=ESP%2D

NOW%20is%20a%20wireless,ESP32%2DC%20series%20of%20SoCs. (https://www.espressif.com/en/solutions/low-power-solutions/esp-now)

### - Single-Lead, Heart Rate Monitor Front End AD832 Datasheet: https://cdn.sparkfun.com/datasheets/Sensors/Biometric/AD8232.pdf

### - 1 MSPS, 12-Bit Impedance Converter, Network Analyzer AD5933 Datasheet: https://www.analog.com/media/en/technical-documentation/data-sheets/ad5933.pdf

### 3.0 CSCI - WIDE DESIGN DECISIONS

### Figure 2 shows the CSCI Diagram of the device. In this diagram, we can see that the

device revolves around the ESP32-S3 Feather microcontrollers that are attached to each sensor

### and the user’s computer. The team suggested the use of the ESP32 to the sponsor, and the

sponsor was convinced and proposed this specific model. Unlike the other ESP32 models, the ESP32-S3 Feather has additional unique features. Here are the specifications that the ESP32-S3

### Feather has to offer:

- ESP32-S3 Dual Core 240MHz Tensilica processor - Power options - USB type C or Lipoly battery - Built-in battery charging when powered over USB-C - LiPoly battery monitor - MAX17048 chip actively monitors your battery for voltage and state of charge/percentage reporting over I2C - Reset and DFU (BOOT0) buttons to get into the ROM bootloader - STEMMA QT connector for I2C devices - On/Charge/User LEDs - Low Power friendly - Works with ESP-IDF and Arduino: This includes the ESP-NOW Protocol for wireless

communication.

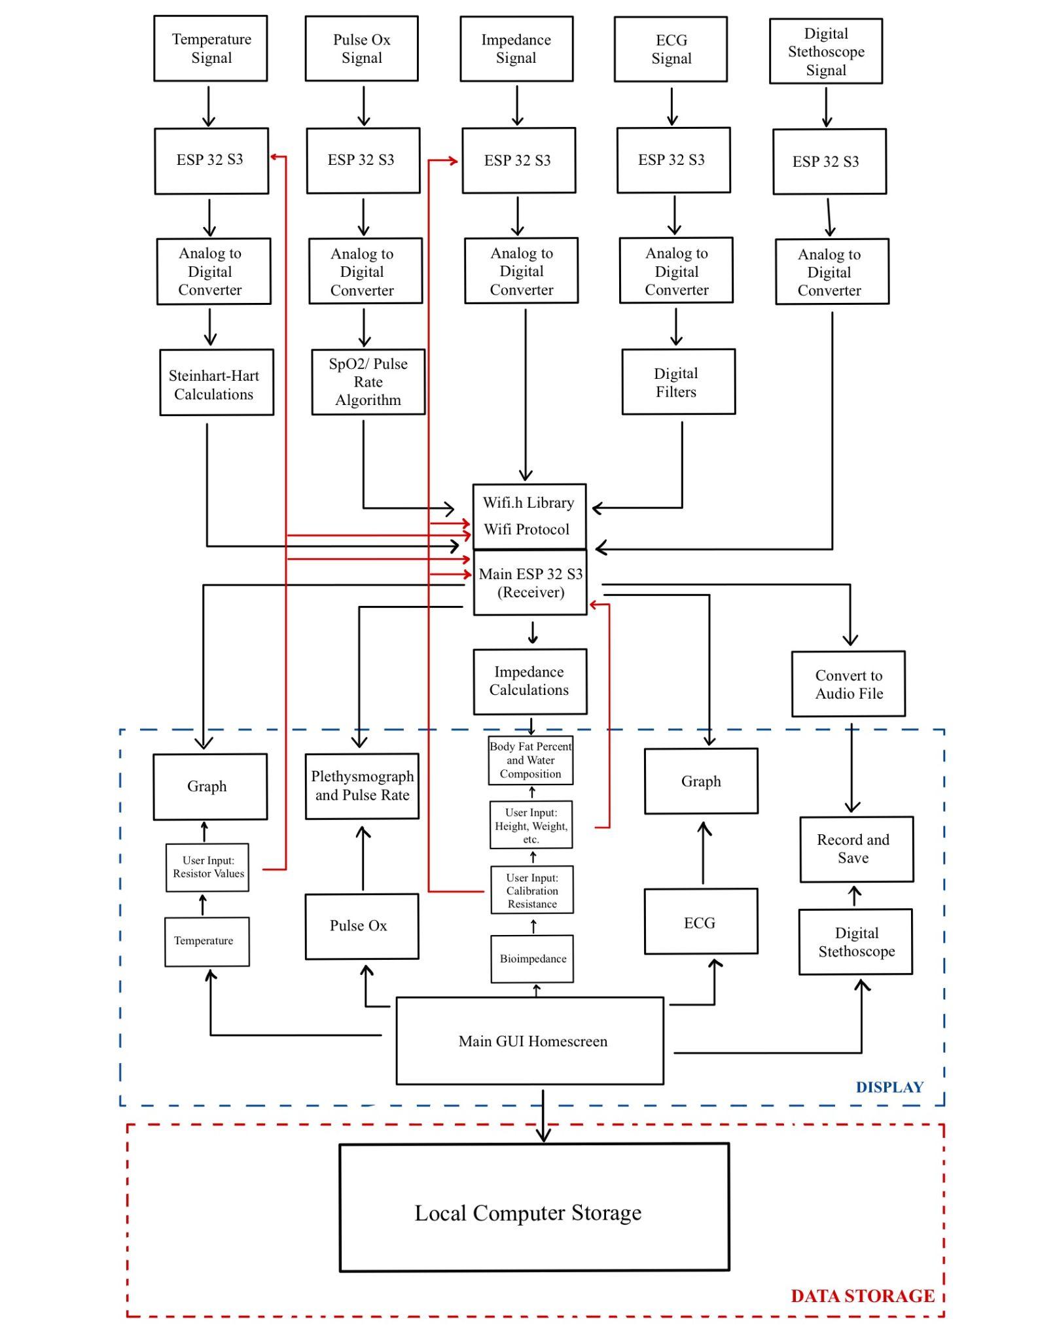
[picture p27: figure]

Figure 2. MediBrick 2000 CSCI Diagram

### 3.1 INPUTS AND OUTPUTS

### 3.1.1 Electrocardiography (ECG)

### Input:

### For the ECG sensor, the only GUI user input required is to click the “ECG” option in the

main menu. As for the signal input, it is collected from the user using 3-Snap electrodes and disposable electrodes. The disposable electrodes will be attached to the user’s right arm, left arm, and right leg. With the provided 3-Snap electrodes for this device, connect the black cable to the user’s right arm, the blue cable to the left arm, and the red cable to the right leg. It’s best to remember that the cable colors may differ with different brands. It is best to check with the manufacturer if electrodes are not provided with the device.

### Other than the GUI and signal inputs, the ECG will also have a button. Users will have

the ability to provide input by pressing the button or holding it for 5 seconds. These two inputs will provide different outputs.

### Output:

### The ECG sensor will output voltage levels corresponding to what the electrodes detect

from the user. To avoid inaccurate results, the Arduino code for the ECG’s ESP32-S3 Feather includes a lead-off detection which stops the sensor from outputting readings when the electrodes are not connected to a user. Within the GUI, the page that corresponds to the ECG will output a graph of voltage vs. time as well as the voltage itself. Users will have the option to save the results into an Excel file.

### Lastly, regarding the ECG button that was previously mentioned, pressing the button will

change the OLED display from displaying the battery percentage to the ECG voltage. However, holding it for 5 seconds will put the ESP32-S3 Feather connected to the ECG into deep sleep mode.

### 3.1.2 Digital Stethoscope

### Input:

For the digital stethoscope (sound sensor), the only input in regards to the GUI is for the user to click on the “Digital Stethoscope” option in the main menu. As for the signal input, the sound sensor will have a diaphragm and a bell attached to its module. Users will place this on the chest, near the heart, to listen to the subject’s heartbeat, or around different points of the torso to listen to their subject’s lungs.

Other than the GUI and signal inputs, the digital stethoscope will also have a button. Users will have the ability to provide input by pressing the button or holding it for 5 seconds. These two inputs will provide different outputs.

### Output:

### The sound sensor will output audio signals corresponding to where the diaphragm and

bell are placed. The GUI will output a graph of the audio signal as well as real-time sound recording. Users will have the option to save this recording into a wav file.

### Lastly, regarding the previously mentioned button, pressing the button will change the

OLED display from displaying the battery percentage to the audio signal. However, holding it

### for 5 seconds will put the ESP32-S3 Feather connected to the Sound Sensor into deep sleep

mode.

### 3.1.3 Temperature

### Input:

In regards to inputs, the user will also have the option to pick “temperature” in the main menu. However, for the temperature sensor, the GUI will ask the users for three resistance values from the circuit of the temperature sensor. Instructions on how to attain these values will be given in the user manual. Other than the GUI, the temperature sensor uses a probe for the user to use, which provides the signal input into the ESP32-S3 Feather of the temperature sensor.

Other than the GUI and signal inputs, the temperature sensor will also have a button. Users will have the ability to provide input by pressing the button or holding it for 5 seconds. These two inputs will provide different outputs.

### Output:

### The temperature sensor will output resistance values which the ESP32-S3 Feather will

calculate into degrees Celsius. This will then be displayed in the GUI as a graph as well as the actual value. Users will have the option to save this data into an Excel file.

### Lastly, regarding the previously mentioned button, pressing the button will change the

OLED display from displaying the battery percentage to the temperature in degrees Celsius. However, holding it for 5 seconds will put the ESP32-S3 Feather connected to the Temperature into deep sleep mode.

### 3.1.4 Impedance

### Input:

### For the impedance sensor, similar to the other sensors, it will also have the option

“BioImpedance” in the main menu of the GUI. When users click on this option, the GUI will ask for their input regarding the use of a calibration resistor. If users would like to use said calibration resistor, they will need to input a resistance value as well as press a button on the GUI that flips the switch from “tissue sample” to the calibration resistor. However, if the user prefers to use a tissue sample, they will be required to press a button on the GUI to make sure that the switch is on the tissue sample circuitry. The GUI will then ask the user’s input in regards to their height and weight. As for signal inputs, the impedance sensor uses 2-snap electrodes to measure tissue impedance.

### However, other than the software input, the impedance PCB will also have an optional

user input that affects its functionality. Users will have the option to use one 2-snap electrode or

### two 2-snap electrodes. Each option has its advantages and disadvantages depending on the

sample. If the user was to choose one or the other, they would need to detach a couple of jumpers within the PCB. Instructions will be provided in the user manual.

### Other than the GUI and signal inputs, the impedance sensor will also have a button. Users

will have the ability to provide input by pressing the button or holding it for 5 seconds. These two inputs will provide different outputs.

### Output: The impedance sensor will output impedance values. These values will then be calculated

by the Python code to output body fat percentage and water composition on the GUI. The GUI will also display a graph of the impedance values.

### Lastly, regarding the button that was previously mentioned, pressing the button will

change the OLED display from displaying the battery percentage to the impedance values. However, holding it for 5 seconds will put the ESP32-S3 Feather connected to the Impedance into deep sleep mode.

### 3.1.5 Pulse Oximetry

### Input:

For the pulse oximeter sensor, the user will also have the option to pick “Pulse Oximetry” in the main menu of the GUI. The pulse oximeter will use a 9-pin SpO2 sensor to collect user signal input. This probe will be clipped on the subject’s index finger.

Other than the GUI and signal inputs, the pulse oximeter sensor will also have a button. Users will have the ability to provide input by pressing the button or holding it for 5 seconds. These two inputs will provide different outputs.

### Output:

The pulse oximeter sensor will output red light and near-infrared light absorbances. Using these values, the ESP32-S3 Feather will then calculate the blood oxygen saturation of the subject as well as pulse rate using the library protocentral_afe44xx.h. These four results will then be displayed on the GUI. The red light and near-infrared light absorbances will also be displayed as a live graph. Users will have the option to save all these values into an Excel File.

### Lastly, regarding the previously mentioned button, pressing the button will change the

OLED display from displaying the battery percentage to the blood oxygen saturation and pulse rate. However, holding it for 5 seconds will put the ESP32-S3 Feather connected to the Pulse Ox into deep sleep mode.

### 3.1.6 GUI Miscellaneous

### Input:

The GUI’s home page requires a user input to provide a username.

### Output: Using the entered username, the Python program will create a folder locally in the same

location as the program. This folder will be named after the entered username. This folder will

### have five subfolders named “ECG”, “Temperature”, “Impedance”, “Digital Stethoscope”, and

“Pulse Oximeter”. Whenever the user decides to save any of the data shown in the GUI, these will be saved in their corresponding subfolders.

### Input:

The user has the option to pick which port to read data from.

### Output:

Depending on the user’s input, the Python program will read from that port.

### Input:

The user can choose the baud rate they prefer.

### Output:

The ESP32-S3 Feather will output data at the rate the user chooses.

### 3.2 RESPONSE

### 3.2.1 Electrocardiography (ECG)

### When the AD8232 (ECG sensor) detects that the electrode leads are attached, it extracts

biopotential signals. The electrical signals picked up by the electrodes are very weak, on the order of microvolts, so the AD8232 amplifies these weak signals to a level that can be more easily processed. The AD8232 also includes an instrumentation amplifier that helps amplify the signal while rejecting common-mode noise. The amplified signal may contain unwanted noise or interference, which the AD8232 will filter to remove noise and isolate the relevant ECG signals. Lastly, the processed and filtered ECG signal is then provided as an output.

### After the sensor response, the resulting signal is sent into the ESP32-S3 Feather that is

connected to the AD8232. This microcontroller adds a digital filter to remove additional noise

### from the ECG signal. After filtering, using the ESP-NOW protocol, the result from the

ESP32-S3 Feather is sent wirelessly to the ESP32-S3 Feather that is connected to the user's computer. The GUI, which is in Python, will then read the serial port and detect the data coming from the ECG sensor. This data is the resulting output.

### 3.2.2 Digital Stethoscope

### The data collection starts at the stethoscope diaphragm. After the heartbeat is detected and sent through the tubing, the signal is captured electronically by the microphone. The

amplitude of the signal is considerably small and almost impossible to hear, so the signal goes through a pre-amplification stage. The signal may contain noise at different high frequencies, so it passes through an analog low pass filter which attenuates frequencies above 1000 Hz. Then, the signal is digitized with the ES8388 and later sent into the ESP32-S3 Feather.

### Once the ESP32-S3 receives the digital signal, it executes a IIR digital low pass filter

which also attenuates frequencies above 1000 Hz to remove any remaining noise. After filtering, the signal is sent wirelessly to the ESP32-S3 Feather that is connected to the user’s computer. This second ESP32-S3 Feather forwards the digital signal to the user’s computer, and it is read with the Python-coded GUI. Finally, the program produces a real-time graph and a real-time sound recording with the signal.

### 3.2.3 Temperature

### The temperature sensor response begins once the user chooses the temperature option in

the GUI. When the temperature sensor is exposed to heat, its resistance changes. This causes the voltage across the branch of the Wheatstone bridge to change, which is measured by the Arduino

### code: vdiff=vb-vd. This voltage difference is then converted to resistance by R4 =

R3/(R2/(R1+R2)-vdiff/vin)-R3. This resistance is then converted to temperature in Kelvin by

### Steinhart-Hart equation = 1/A+Blog(R) + Cpow(log(R), 3), which will then be converted to

Celsius using the equation temp=temp-273.15. The ESP32-S3 Feather of the temperature sensor will accumulate 100 values together, and it averages these values. The results will then be rounded to the second decimal place, which is sent to the ESP32-S3 Feather connected to the user’s computer. This value will then be displayed to the GUI.

### 3.2.4 Impedance

The impedance sensor starts with the multiple user inputs needed for its functionality. Once the program is ready, the user will attach the electrodes for the impedance sensor. The

### AD5933 (Impedance sensor) has a frequency generator that allows an external complex impedance to be excited with a known frequency. This is sent through the electrodes. The response signal from the impedance is sampled by the on-board ADC and a discrete Fourier

transform (DFT) is processed by an on-board DSP engine. The DFT algorithm returns real (R)

### and imaginary (I) data at each output frequency. The magnitude of the impedance at each

frequency point along the sweep is then calculated using the ESP32-S3 Feather that is attached to the AD5933.

### Once an impedance value is calculated, this data is sent from the ESP32-S3 Feather of the

impedance sensor to the ESP32-S3 Feather that is attached to the user’s computer. This data is then read by the Python program of the GUI. This Python program will then calculate the body

### fat percentage and water composition using the inputs of the user along with the detected

impedance. These will then be displayed on the GUI.

### 3.2.5 Pulse Oximetry

### The pulse oximeter sensor begins the process of detection at the subject's ring finger

where the pulse oxi sensor is attached and sends pulses of IR and Red waves. These pulses pass through the finger and are received by a photodetector as an analog signal. The analog signal is

### sent to the (AFE4490 Integrated Analog Front-End for Pulse Oximeters) IC where the analog

signal is converted to a digital signal and transferred to ESP32. The process of sending the pulses through the finger and receiving the information from the pulse oxi sensor is achieved by using SPI communication with the ESP32-S3 Feather.

### Once the ESP32 receives the Digital signal that was converted by the AFE4490 IC it goes

through an Algorithm that uses the IR and Red values from the pulse oximeter sensor to calculate the heart rate and blood oxygen of the subject. After processing the data by the ESP32 (IR and

### Red values, BPM, and SPO2), the data is sent wirelessly and received by the master ESP32

attached to the lab computer. This data is then collected by the Python GUI and a graph of real time of the subject is displayed of IR and Red values vs time graph. As well the heart rate and blood oxygen is displayed on the Gui which would be the resulting output.

### 3.3 APPEARANCE

### The GUI appearance was decided by the team along with the sponsor. The main

components of the GUI required by the sponsor are the main menu options that list each sensor, live graphical charts, and the ability to save locally. However, the team decided to add additional components and options to improve the user experience.

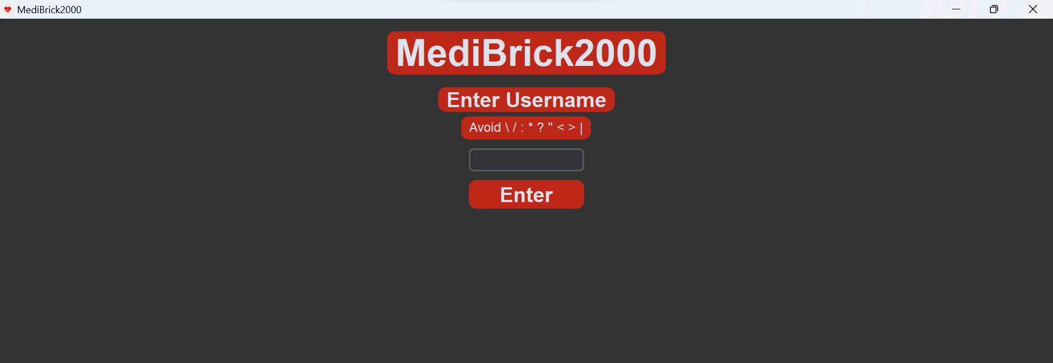
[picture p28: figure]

Figure 3. MediBrick 2000 Homepage

### As we can see in Figure 3., the GUI starts with the home page, which will ask the user to

enter a username. As explained before, this is meant for the saving mechanism of the GUI. This decision was made for users to find their files more easily.

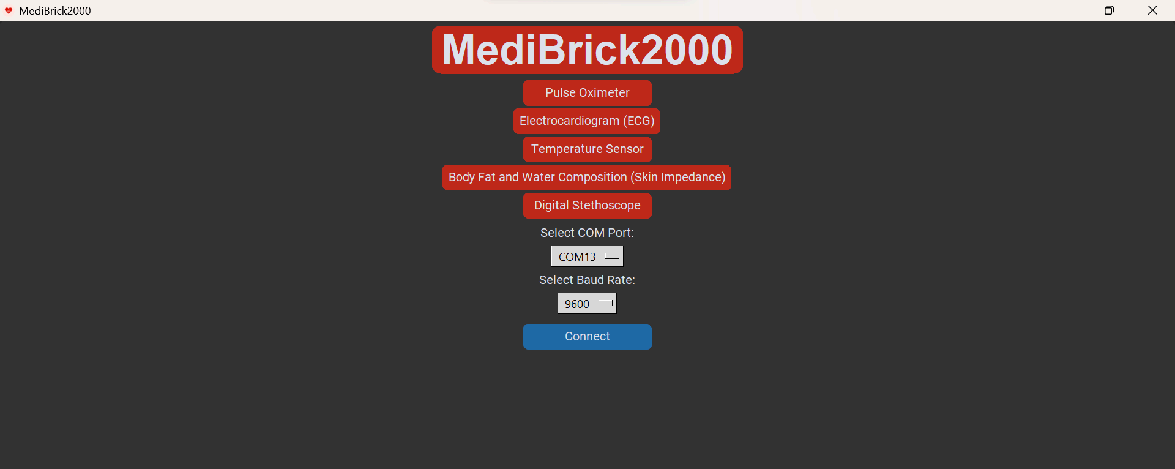
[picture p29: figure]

Figure 4. MediBrick2000 Main Menu

### Next, the GUI will have a main menu that lists every sensor as shown in Figure 4. From

this menu, the user will choose the sensor of their liking.

In the following figures, the pages for each sensor will be shown. All of the sensor pages will have reading and recording options. All the sensor pages will also have the port options as well as the baud rate options.

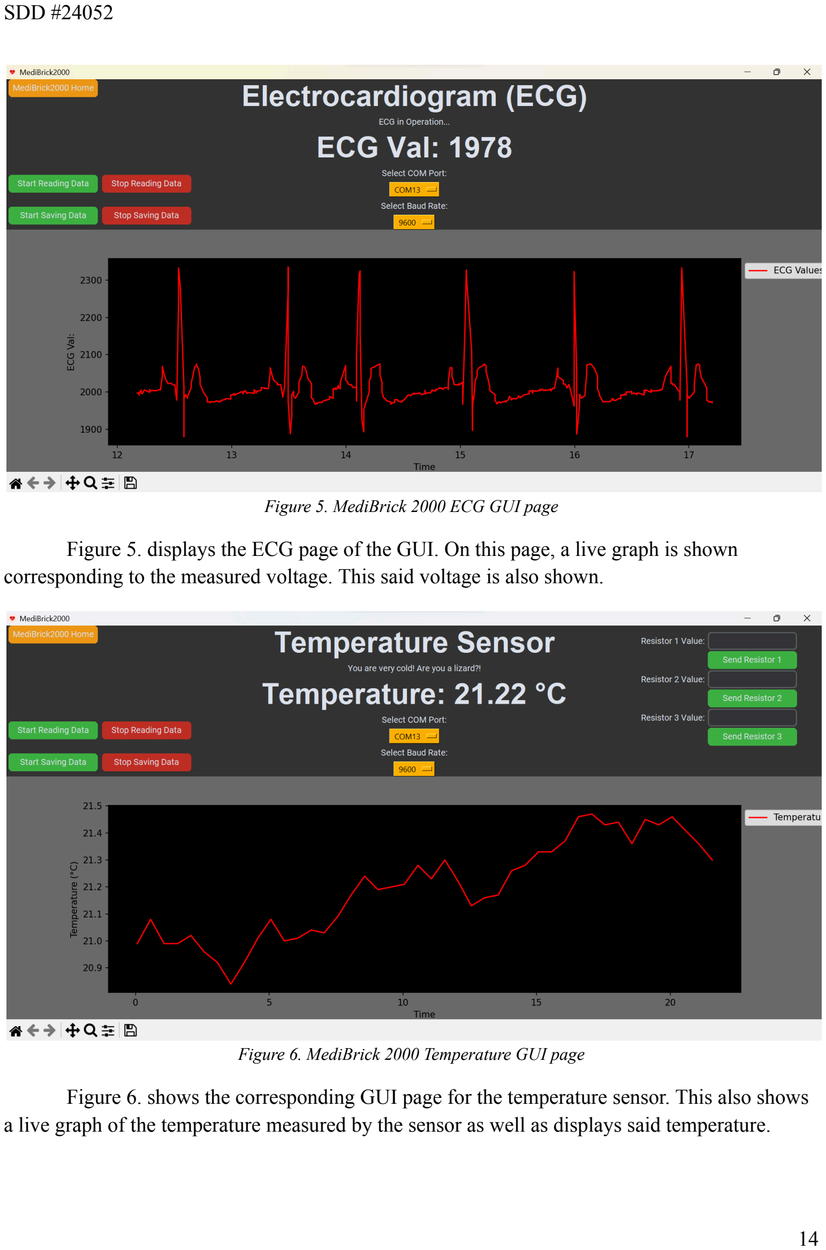
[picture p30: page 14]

Figure 5. MediBrick 2000 ECG GUI page

### Figure 5. displays the ECG page of the GUI. On this page, a live graph is shown

corresponding to the measured voltage. This said voltage is also shown.

Figure 6. MediBrick 2000 Temperature GUI page

### Figure 6. shows the corresponding GUI page for the temperature sensor. This also shows

a live graph of the temperature measured by the sensor as well as displays said temperature.

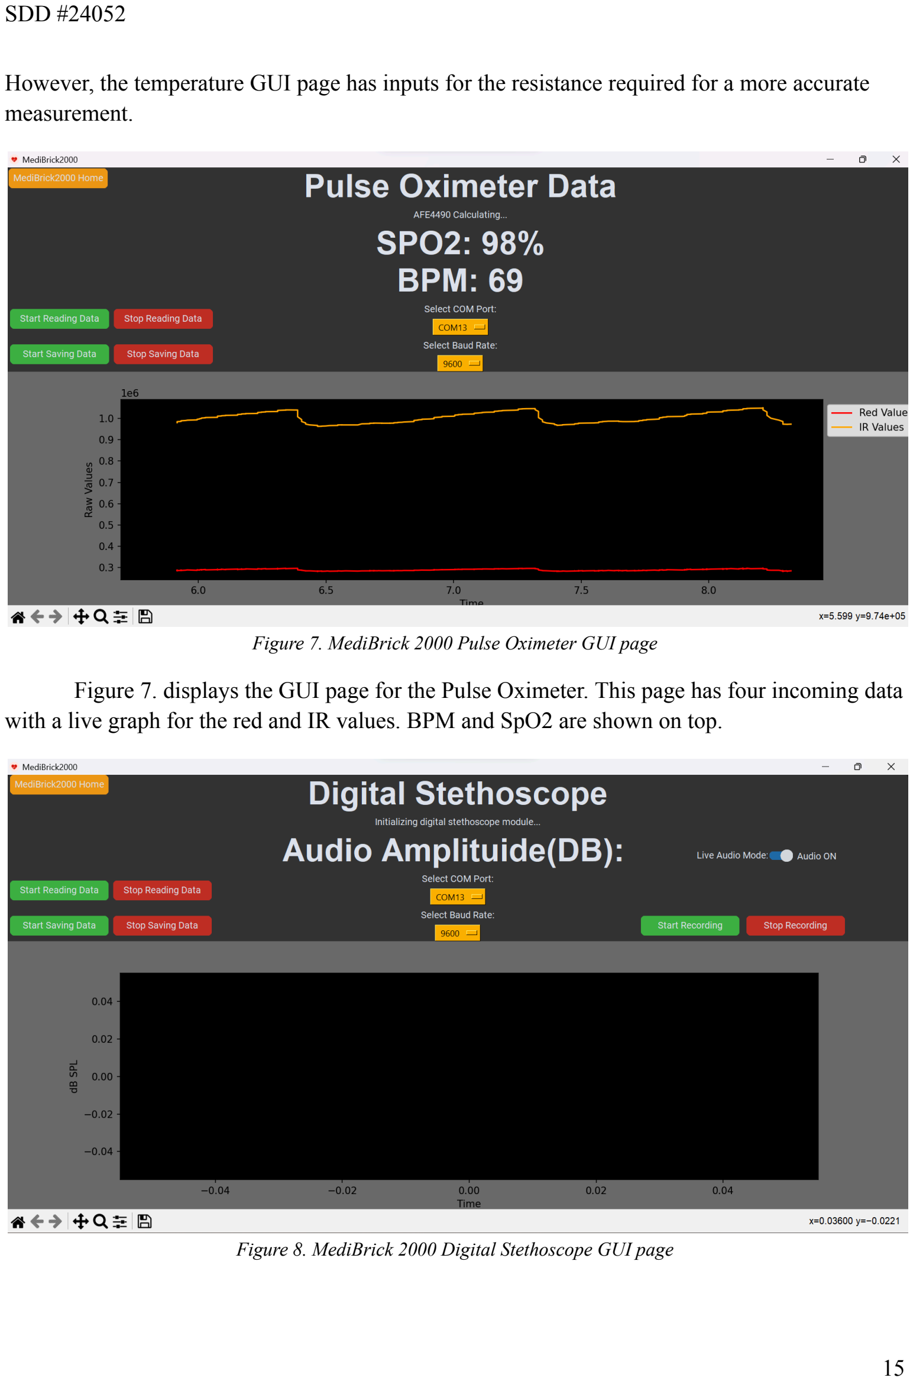
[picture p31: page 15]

However, the temperature GUI page has inputs for the resistance required for a more accurate measurement.

Figure 7. MediBrick 2000 Pulse Oximeter GUI page

### Figure 7. displays the GUI page for the Pulse Oximeter. This page has four incoming data

with a live graph for the red and IR values. BPM and SpO2 are shown on top.

Figure 8. MediBrick 2000 Digital Stethoscope GUI page

### Figure 8. shows the dedicated GUI page for the digital stethoscope. This page shows a

live graph for the incoming audio amplitude as well as the ability to listen to the recording live.

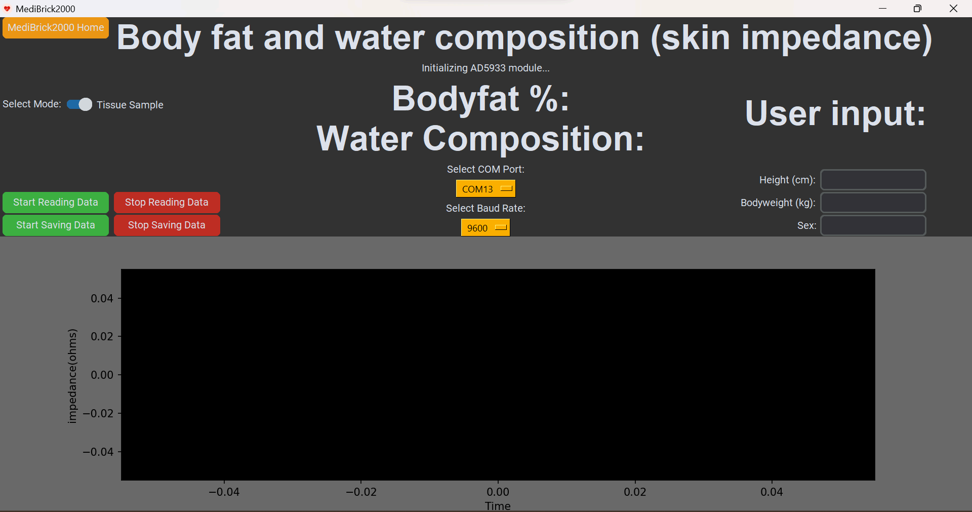
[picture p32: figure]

Figure 9. MediBrick 2000 Impedance GUI page

### Lastly, Figure 9. is the dedicated GUI page for the impedance sensor. Just like the other

sensors, this page will also have a live graph for the incoming impedance values. However, body fat percentage and water composition are displayed as values instead. This GUI page will also ask for user input for proper calculations.

### 3.4 SAFETY, SECURITY, AND PRIVACY REQUIREMENTS

### The biggest concern about the safety of this device is the use of electrodes with

electronics. At the beginning of this project, the team took precautions to keep the device as safe as possible from electricity-related accidents by making each sensor wireless. The batteries used to power these sensors are 1200 mAh 3.7V batteries, which is merely a fraction of the power produced by directly connecting to a wall plug. In addition to the wireless communication, the impedance and ECG sensors, which are the ones using electrodes, were thoroughly designed to keep the current as low as possible before entering the leads. These devices were also tested on physical simulators or circuits before live tissue.

### As for safety requirements for the users of the device, it will be heavily advised to

remove every sensor from the charging station before testing it on anyone. There will also be laboratory-related rules in the user manual such as no liquid or food nearby.

Furthermore, since this project involves the reading and recording of health-related data, the team needed to take precautions and thorough analysis of how to approach the security and privacy of the health records taken by this device. At the beginning of the project’s development, the team was advised to seek out IRB approval. However, after further discussions with an IRB representative, it was decided that this project is not considered a research project. This means that IRB approval was not required for the development of this device.

### Upon discussing this issue with the sponsor, the team decided to require every member to take the annual HIPPA certification offered in EDGE Learning through the University of

Arizona. This can protect the members of the team in regards to the handling of health records, as well as further increase the team’s understanding of the importance of health record privacy.

### More requirements were placed by the team in regard to collecting data from individuals

outside of the group. To protect the confidentiality of the subjects who are volunteering to become part of the device’s development, the team will keep the collected data in a separate flash drive. The collected data will also not be saved with the subject’s name. A number will be used as an identifier instead. Collected data during this stage will not be saved locally in anyone’s computer, and will not be accessed or saved through the internet.

### Outside of the device’s development, a different set of requirements are placed in regard

to the user of this device. If this device were to be used in a classroom setting here at the University of Arizona, the students who are enrolled in this said class would be required to take

### the same annual HIPPA certification that the team members took. There may be additional certifications needed such as the Human Subjects certification depending on the professor

teaching the class. Other than certifications, the GUI made for this device also takes some precautions. By making the GUI an app that works locally, recorded data will only be accessed on the student’s personal computer and not online. In case the student does not have a personal computer, the University of Arizona computers are also programmed to erase locally saved data once the user logs out of their account.

### 3.5 FLEXIBILITY, AVAILABILITY, AND MAINTAINABILITY

### As mentioned in the introduction of this document, this device is open-design. Not only

that but it is designed to be easily replicated and maintained. All documents related to the

### development of this project will be released in a GitHub repository online for anyone to

replicate. These documents will include the Arduino codes for each sensor, the GUI code, the additional MATLAB codes for analysis, the 3D models for the housing, the schematics and PCB designs, and the user manual of the device.

### 4.0 CSCI ARCHITECTURAL DESIGN

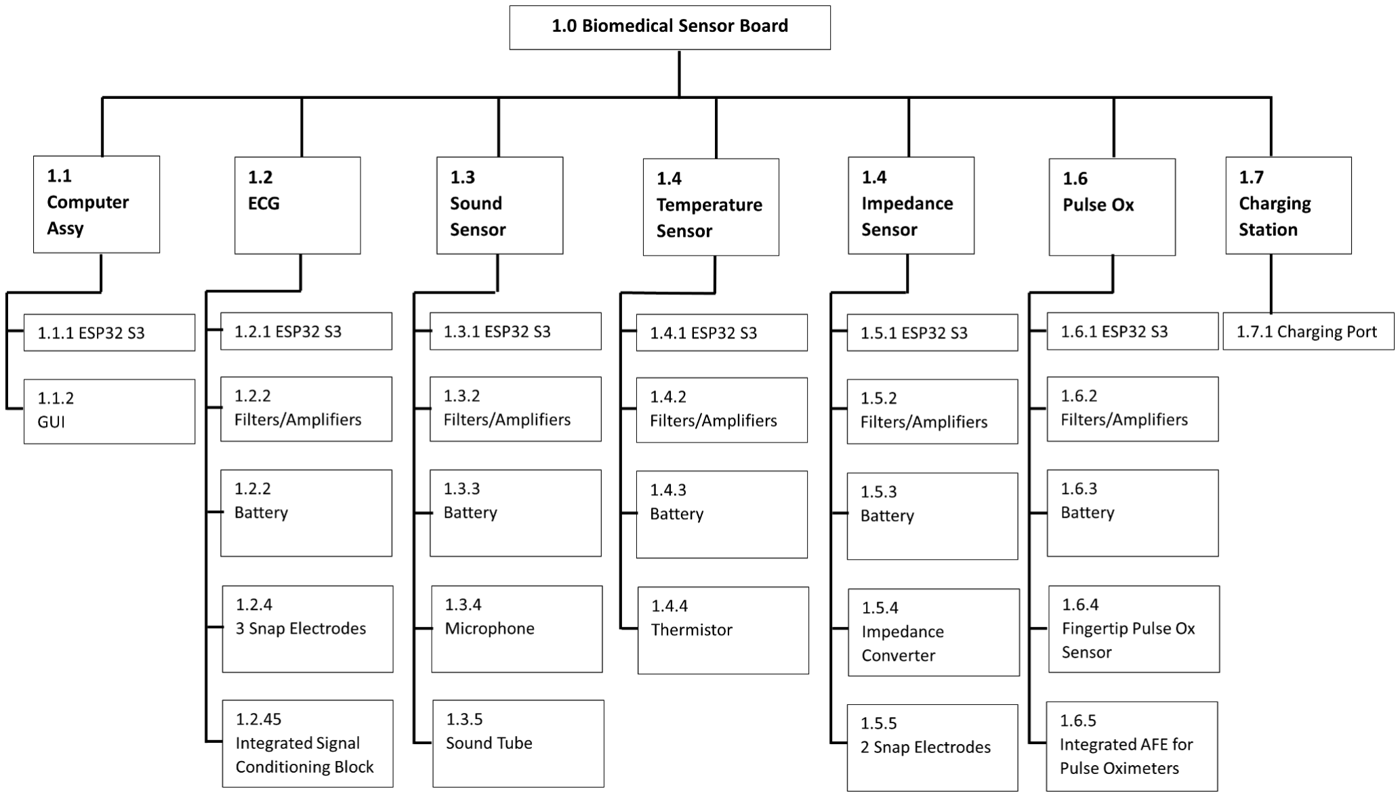
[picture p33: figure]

Figure 10. MediBrick 2000 System Architecture

### 4.1 CSCI COMPONENTS

### 4.11 IDENTIFICATION

### For this device, the two computer languages used for the end product are Python and a variant of C++ (Arduino). However, during the development of each sensor, MATLAB also

plays a role in the analysis stage. The core component of this project is the ESP-NOW protocol that is available with the ESP32-S3 Feather microcontroller. This protocol performs ESP-to-ESP communication wirelessly which is one of the most important aspects of this device.

In terms of the GUI, the current design takes advantage of the customtkinter library. This library is a modern twist of the class tkinter library. With this library, the GUI was able to carry out a newer look compared to what tkinter has to offer. Lastly, the live graphs, which is another important aspect of the GUI, are displayed using the matplotlib library.

### 4.12 STATIC RELATIONSHIP

In terms of the GUI, most components that has a static relationship are typically involved with the aesthetics of the full design. This includes the font sizes, font colors, widget colors, and the overall theme.
As for the individual sensors, the main static component that will remain constant for all the sensors’ ESP32-S3 Feathers is the receiver ESP32-S3 Feather’s address. This is an important component for the wireless communication of the sensors.

### 4.13 PURPOSE

### The main purpose of the GUI is to display live data from any of the five sensors. The

GUI is also enables users to export data for further analysis or share specific views of the GUI with colleagues. This promotes collaboration and facilitates external analysis of the sensor data.

### Not only that, but the GUI integrates additional details about each sensor, including specifications, calibration status, or any relevant data, which can aid users in better

understanding the context of the data being presented.

### 4.14 STATUS

CSCI Component | STATUS
ECG Arduino | Done
Temperature Arduino | Done
Pulse Ox Arduino | Done
Impedance Arduino | Done
Sound Arduino | Done
GUI | Done

### 4.15 LIBRARIES

- Protocentral_afe44xx.h: https://github.com/Protocentral/protocentral-afe4490-arduino - Arduino Audio Tools: https://github.com/pschatzmann/arduino-audio-tools - Arduino Audio Driver: https://github.com/pschatzmann/arduino-audio-driver - ESP-NOW Library: https://github.com/yoursunny/WifiEspNow - Customtkinter: https://github.com/TomSchimansky/CustomTkinter - Matplotlib: https://matplotlib.org/ - Math.h: https://www.tutorialspoint.com/c_standard_library/math_h.htm

### 4.2 CONCEPT OF EXECUTION

### The concept of execution for the GUI involves the step-by-step process of running the application, wirelessly collecting data from the five sensors through ESP32-S3 Feather

microcontrollers, and displaying the information in real-time on the graphical user interface.

### Here is a step-by-step concept of execution for this device:

1. The first step is initialization. Initialize the GUI application by setting up necessary resources, libraries, and configurations.

### 2. Next is setting up the ESP32. Establish communication between the sensors and the receiver ESP32 using the ESP NOW wireless protocol. Also configure each ESP32

device to read data from its respective sensor and transmit it wirelessly.
3. The next step is widget creation. Create GUI widgets (e.g., labels, charts) to visually represent each sensor's data. Thes includes setting up a layout to organize and display the widgets effectively.

### 4. This is followed by event binding. Bind events to trigger data retrieval from ESP32 devices. This could include periodic updates or triggered updates based on user

interaction.

### 5. Afterwards, implement a loop or event mechanism to continuously fetch and update

sensor data in real-time. Display the live data on the GUI, ensuring that users can monitor the latest readings.
6. After the live data display is the data saving feature. This means the implementation of

### the functionality to allow users to save the displayed data. This device involves storing data in a local database, The GUI also provide a user interface for initiating and

managing the data-saving process.
7. Lastly, there are other concepts of execution is user interaction. This GUI allow users to

### interact with the GUI, such as selecting specific sensors, adjusting display settings, or

triggering actions like data saving.

### 4.3 INTERFACE DESIGN

### 4.31 IDENTIFICATION AND DIAGRAMS

The GUI application is identified as a real-time data monitoring and visualization tool for the five sensors connected wirelessly using ESP32-S3 Feather microcontrollers. The diagrams that the GUI will produce will display live data from any of the five sensors.

### In Figure 11., this system diagram illustrates the components involved, including the GUI

interface, ESP32-S3 Feather microcontrollers, and the wireless communication link. It shows the flow of data from sensors to the GUI.

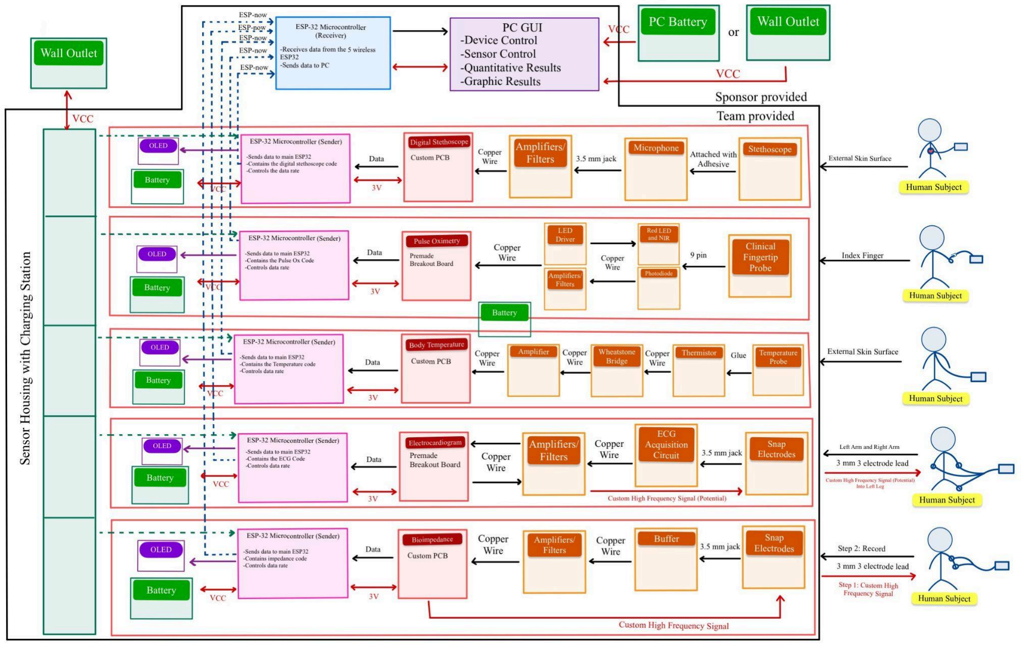
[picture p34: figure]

Figure 11. MediBrick 2000 System Block Diagram

### 4.32 PRIORITY

High priority is given to real-time data display to ensure users have instant access to live sensor readings. It is also a high priority for the data-saving feature to allow users to store and retrieve historical data for analysis. However, some lower priorities are the baud rate and port menu.

### 4.33 TYPE

- The GUI falls under the category of a monitoring and control application.
- Real-time data display represents a live monitoring type.
- Data-saving functionality falls under a data management and storage type.

### 4.34 INDIVIDUAL CHARACTERISTICS

### Each sensor's data is individually displayed on the GUI, allowing users to monitor

specific sensor readings. There are also individual sensor labels that distinguish one sensor from another in the GUI. The GUI also read the port and differentiates the data from each sensor using a symbol or letter that the team will decide later on.

### 4.35 ASSEMBLY CHARACTERISTICS

### The GUI assembles data from multiple ESP32-S3 Feather microcontrollers wirelessly. It

then integrates sensor readings in a unified and coherent manner for easy interpretation.

### 4.36 COMMUNICATION CHARACTERISTICS

### Wireless communication between ESP32 devices and the GUI is established using

ESP-NOW protocol. Real-time communication ensures quick updates of sensor data on the GUI.

### 4.37 PROTOCOL CHARACTERISTICS

### ESP-NOW is the chosen communication protocol for wireless data transfer. This protocol

ensures reliable and low-latency communication between ESP32 microcontrollers. A simple port reading is then performed for the Python program of the GUI to receive data from the receiving ESP32.

### 5.0 CSCI DETAILED DESIGN

### 5.1 ELECTROCARDIOGRAPHY (ECG)

### ESP32-S3 Feather ECG Arduino Code: This is the Arduino code for the ECG. The biggest takeaway from this code is the analog

read that takes the data from the ECG board into the ESP32.

#include <esp_now.h>

#include <WiFi.h>

#include <Wire.h>

#include <Adafruit_GFX.h>

#include <Adafruit_SSD1306.h>

#include "Adafruit_MAX1704X.h"

const unsigned char Battery_100 [] = {
0x00, 0x00, 0x00, 0x00, 0x00, 0x00, 0x00, 0x00, 0x00, 0x00, 0x00, 0x00, 0x00, 0x00, 0x00, 0x00, 0x00, 0x00, 0x00, 0x00, 0x00, 0x00, 0x00, 0x00, 0x00, 0x00, 0x00, 0x00, 0x00, 0x00, 0x00, 0x00, 0x00, 0x00, 0x00, 0x00, 0x3F, 0xFF, 0xFF, 0xF0, 0x40, 0x00, 0x00, 0x10, 0x47, 0x3C, 0xE7, 0x18, 0x47, 0xBD, 0xE7, 0x98, 0x45, 0xA5, 0xA5, 0x9E, 0x45, 0xA5, 0xA5, 0x9A, 0x45, 0xA5, 0xA5, 0x9A, 0x45, 0xA5, 0xA5, 0x9A, 0x45, 0xA5, 0xA5, 0x9A, 0x45, 0xA5, 0xA5, 0x9E, 0x47, 0xBD, 0xE7, 0x98, 0x47, 0x3C, 0xE7, 0x18, 0x40, 0x00, 0x00, 0x10, 0x3F, 0xFF, 0xFF, 0xF0, 0x00, 0x00, 0x00, 0x00, 0x00, 0x00, 0x00, 0x00, 0x00, 0x00, 0x00, 0x00, 0x00, 0x00, 0x00, 0x00, 0x00, 0x00, 0x00, 0x00, 0x00, 0x00, 0x00, 0x00, 0x00, 0x00, 0x00, 0x00, 0x00, 0x00, 0x00, 0x00, 0x00, 0x00, 0x00, 0x00
};
const unsigned char ECG_Disp [] = {
0x00, 0x00, 0x00, 0x00, 0x00, 0x00, 0x00, 0x00, 0x00, 0x00, 0x00, 0x00, 0x00, 0x00, 0x00, 0x00, 0x00, 0x00, 0x80, 0x00, 0x00, 0x00, 0x80, 0x00, 0x00, 0x00, 0x80, 0x00, 0x00, 0x00, 0x80, 0x00, 0x00, 0x00, 0x80, 0x00, 0x00, 0x00, 0x80, 0x00, 0x00, 0x00, 0x80, 0x00, 0x00, 0x00, 0x80, 0x00, 0x00, 0x00, 0xc0, 0x00, 0x00, 0x00, 0xc0, 0x00, 0x00, 0x00, 0xc0, 0x00, 0x00, 0x00, 0xc0, 0x00, 0x00, 0x04, 0xc3, 0x00, 0x01, 0x86, 0xc7, 0x80, 0x03, 0xef, 0xec, 0xff, 0x7e, 0x39, 0x78, 0x00, 0x00, 0x10, 0x60, 0x00, 0x00, 0x00, 0x20, 0x00, 0x00, 0x00, 0x20, 0x00, 0x00, 0x00, 0x20, 0x00, 0x00, 0x00, 0x20, 0x00, 0x00, 0x00, 0x20, 0x00, 0x00, 0x00, 0x20, 0x00, 0x00, 0x00, 0x20, 0x00, 0x00, 0x00, 0x20, 0x00, 0x00, 0x00, 0x00, 0x00, 0x00, 0x00, 0x00, 0x00, 0x00, 0x00, 0x00, 0x00 };

static float filteredValue = 0;
// Reset pin not used but needed for library #define OLED_RESET -1
Adafruit_SSD1306 display(OLED_RESET);

Adafruit_MAX17048 maxlipo;

//debounce of button
// Constants for debounce
const int BUTTON_PIN = 9;
const unsigned long DEBOUNCE_DELAY = 50;
const unsigned long RESET_DURATION = 5000; // 5 seconds volatile int buttonState = HIGH;
volatile int lastButtonState = HIGH;
volatile unsigned long lastDebounceTime = 0;
volatile unsigned long buttonPressStartTime = 0; volatile bool resetTriggered = false;
unsigned long lastDisplayUpdateTime = 0;
const unsigned long displayUpdateInterval = 1000;

//define diferent states for oled
typedef enum stateDsiplay {Bat, Data} stateType;

volatile stateType oledDisplay = Bat;

//interupt func for different states of oled when button is pressed void handleButtonPress() {
unsigned long currentMillis = millis();

// Check if enough time has passed since the last button press
if (currentMillis - lastDebounceTime > DEBOUNCE_DELAY) { int reading = digitalRead(BUTTON_PIN);

if (reading != lastButtonState) {
lastDebounceTime = currentMillis;
lastButtonState = reading;

if (lastButtonState == HIGH) {
// Button pressed, start/reset the timer buttonPressStartTime = currentMillis; resetTriggered = false;
}
else {
// Button released, reset timer and trigger reset if held for 5 seconds buttonPressStartTime = 0;
resetTriggered = false;
}

// Move this part outside the inner if statement if (lastButtonState == LOW) {
// Button pressed, toggle OLED display state if (oledDisplay == Bat) {
oledDisplay = Data;
}
else {
oledDisplay = Bat;
}
}
}
}
}

// REPLACE WITH YOUR RECEIVER MAC Address uint8_t broadcastAddress[] = {0xdc, 0x54, 0x75, 0xc3, 0xbe, 0xfc}; // Structure example to send data
// Must match the receiver structure
typedef struct Ecg {
int ECG;
} Ecg;

// Create a struct_message called myData Ecg ECGData;

esp_now_peer_info_t peerInfo;

// callback when data is sent
void OnDataSent(const uint8_t *mac_addr, esp_now_send_status_t status) { Serial.print("\r\nLast Packet Send Status:\t");
Serial.println(status == ESP_NOW_SEND_SUCCESS ? "Delivery Success" : "Delivery Fail"); }

void updateDisplay() {
display.clearDisplay();
// switch case for oled state switch (oledDisplay) {
case Bat:
display.setTextSize(1.3);
display.drawBitmap(0, 4, Battery_100, 32, 32, 1); display.setCursor(42, 0);
display.print("ChgR:");
display.print(maxlipo.chargeRate()); display.print(" %/hr");
display.setCursor(40, 15); display.print("Bat:");
display.print(maxlipo.cellPercent(), 1); display.print(" %");

display.display();
break;

//display ecg
case Data:
display.setTextSize(1.3);
display.drawBitmap(0,4,ECG_Disp,32,32,1); display.setCursor(35,0);
display.print("ECG Val:"); display.print(filteredValue); display.display();
break;
}
}

void setup() {
Wire.begin();
Serial.begin(57600);
delay(500);

// Set device as a Wi-Fi Station WiFi.mode(WIFI_STA);

// Init ESP-NOW
if (esp_now_init() != ESP_OK) { Serial.println("Error initializing ESP-NOW");
return;
}

// Once ESPNow is successfully Init, we will register for Send CB to // get the status of Trasnmitted packet esp_now_register_send_cb(OnDataSent);

// Register peer
memcpy(peerInfo.peer_addr, broadcastAddress, 6); peerInfo.channel = 0;
peerInfo.encrypt = false;

// Add peer
if (esp_now_add_peer(&peerInfo) != ESP_OK){ Serial.println("Failed to add peer");
return;
}

pinMode(BUTTON_PIN, INPUT); attachInterrupt(digitalPinToInterrupt(BUTTON_PIN), handleButtonPress, CHANGE); esp_sleep_enable_ext0_wakeup(GPIO_NUM_9,1); //wake

pinMode(10, INPUT); // Setup for leads off detection LO +

pinMode(11, INPUT); // Setup for leads off detection LO -

// initialize OLED with I2C addr 0x3C display.begin(SSD1306_SWITCHCAPVCC, 0x3C);
// Clear the display
display.clearDisplay();
//Set the color - always use white despite actual display color display.setTextColor(WHITE);
//Set the font size
display.setTextSize(1.5);
//Set the cursor coordinates display.setCursor(0,0);
display.print("ECG Config..."); display.display();
delay(1000); // pause for a moment

//check if max module is present if not send error
if (!maxlipo.begin()) {
Serial.println(F("Couldnt find Adafruit MAX17048?\nMake sure a battery is plugged in!")); while (1) delay(10);
}
}

void ECG() {
if((digitalRead(10) == 1)||(digitalRead(11) == 1)) { Serial.println('!');
}
else {
int signalValue = analogRead(A1);

// Apply a low-pass filter
float alpha = 0.92; // Filter coefficients (0.9 and 0.1) filteredValue = 0;
filteredValue = alpha * signalValue + (1 - alpha) * filteredValue; //myData.ecg = signalValue;
ECGData.ECG = filteredValue;
Serial.print("ECG:");
Serial.println(filteredValue);

// Send message via ESP-NOW
esp_err_t result = esp_now_send(broadcastAddress, (uint8_t *) &ECGData, sizeof(ECGData));

if (result == ESP_OK) {
//Serial.println("Sent with success");
}
else {
//Serial.println("Error sending the data"); }
}

}

unsigned long lastECGTime = 0; const unsigned long ecgInterval = 10;

void loop() {
unsigned long currentMillis = millis();
//esp_sleep_enable_ext0_wakeup(GPIO_NUM_9,1);
// Check if the button is being held down for 5 seconds
if (buttonPressStartTime != 0 && !resetTriggered && currentMillis - buttonPressStartTime >= RESET_DURATION) {
// Button held for 5 seconds, trigger reset
resetTriggered = true; //deep sleep instead of reset
display.clearDisplay();
display.setCursor(0,0);
display.println("Entering DeepSleep"); display.println("GOOD NIGHT"); display.display();
delay(5000);
display.clearDisplay();
display.display();
esp_deep_sleep_start();
}
// Check for ECG update based on time
if (currentMillis - lastECGTime >= ecgInterval) { ECG();
lastECGTime = currentMillis;
}

// Check for display update based on time
if (currentMillis - lastDisplayUpdateTime >= displayUpdateInterval) { updateDisplay();
lastDisplayUpdateTime = currentMillis;
}
}

### ECG MATLAB Code for Analysis: This is the MATLAB program for the ECG analysis. This program is used to perform fast

Fourier transform on the ECG data collected.

% Load ECG data from Excel file
[~, ~, data] = xlsread('ecg alone v2.xlsx');

% Assuming the first column is time and the second column is ECG values time = cell2mat(data(:, 1));
ecg_values = cell2mat(data(:, 2));

% Create smaller figures figure('Position', [100, 100, 800, 400]);

% Plot Time Domain
subplot(2, 1, 1);
plot(time, ecg_values);
title('ECG Time Domain');
xlabel('Time (s)');
ylabel('ECG Values');
grid on;

% Plot Frequency Domain (FFT)
subplot(2, 1, 2);
fs = 1 / (time(2) - time(1)); % Calculate sampling frequency N = length(ecg_values); % Number of samples

% Ensure N is a power of 2 for FFT efficiency (optional) N = 2^nextpow2(N);

frequencies = linspace(0, fs/2, N/2 + 1);

% Extend the x-axis range to cover the Nyquist frequency extendedFrequencies = linspace(0, fs/2, N/2 + 1);

% Compute FFT
fft_values = fft(ecg_values, N);
fft_values = abs(fft_values(1:N/2+1));

% Plot the magnitude spectrum plot(extendedFrequencies, fft_values); title('ECG Frequency Domain'); xlabel('Frequency (Hz)');
ylabel('Magnitude');
grid on;

% Identify powerline frequency and harmonics
powerlineFrequency = 60; % Change this to 50 if you are in a 50 Hz powerline region harmonics = 1:2; % Adjust the range based on the expected harmonics

hold on;

% Plot markers at the powerline frequency and harmonics
for harmonic = harmonics
line([harmonic * powerlineFrequency, harmonic * powerlineFrequency], [0, max(fft_values)], 'Color', 'r', 'LineStyle', '--');
end

hold off;

% Adjust subplot spacing explicitly

subplot(2, 1, 1);
ax1 = gca;
ax1.Position = [0.1, 0.55, 0.8, 0.4]; % [left, bottom, width, height]

subplot(2, 1, 2);
ax2 = gca;
ax2.Position = [0.1, 0.1, 0.8, 0.35]; % [left, bottom, width, height]

### 5.2 DIGITAL STETHOSCOPE (SOUND)

### ESP32-S3 Feather Sound Sender Arduino Code: This code is for the sender code of the Sounder Sensor’s ESP32-S3 Feather. The sender code for the Sound Sensor module receives the information from the codec ES8388 in I2S format and sends it to the receiver ESP32 using ESPNow. The code initializes the

communication of the sender ESP32 with the codec, configures it, filters the incoming signal with a given digital filter, and finally sends the data to the receiver ESP32 using ESPnow.

* @brief We configure the audio codec ES8388 with the help of AudioTools I2SCodecStream.
* Then, we filtered the stream of bits using a second order IIR with FilteredStream.
* Finally, we send the stream of bits to a secondary ESP32-S3 using ESP-NOWStream.
* @author Daniel Campana
*/

#include "AudioTools.h" // install https://github.com/pschatzmann/arduino-audio-tools #include "AudioLibs/I2SCodecStream.h"

#include "Communication/ESPNowStream.h"

// I2C
#define SDAPIN | 3 // I2C Data, Adafruit ESP32 S3 3, Sparkfun Thing Plus C 23

#define SCLPIN | 4 // I2C Clock, Adafruit ESP32 S3 4, Sparkfun Thing Plus C 22

#define I2CSPEED | 100000 // Clock Rate

#define ES8388ADDR | 0x10 // Address of ES8388 I2C port

// I2S, your configuration for the ES8388 board
#define MCLKPIN | 14 // Master Clock

#define BCLKPIN | 36 // Bit Clock

#define WSPIN | 8 // Word select

#define DOPIN | 37 // This is connected to DI on ES8388 (MISO)

#define DIPIN | 35 // This is connected to DO on ES8388 (MOSI)

AudioInfo | audio_info(8000, 1, 16); | // sampling rate, # channels (mono), bit depth
DriverPins | my_pins; | // board pins
AudioBoard | audio_board(AudioDriverES8388, my_pins); // audio board
I2SCodecStream | i2s_out_stream(audio_board); | // i2s coded
TwoWire | myWire = TwoWire(0); | // universal I2C interface

// Set up filtered stream and copy it to ESP-NOW. The coefficients of the filter may vary (depending on sampling rate)
uint16_t channels = 1;
FilteredStream<int16_t, float> inFiltered(i2s_out_stream, channels);
// Current specifications of the filter: fc_high = 100, fc_low = 1150, fs = 8000. See MATLAB code for variations of this filter
const float b_coefficients[] = { 0.1158, 0.0000,-0.2317, 0.0000, 0.1158};
const float a_coefficients[] = { 1.0000,-2.6850, 2.6850,-1.2530, 0.2559};

ESPNowStream now;
StreamCopy copier_now(now, inFiltered); // copies i2s_out_stream into i2s
const char *peers[] = {"DC:54:75:C3:B8:92"};
// CsvOutput<int16_t> Serial_out(Serial); | // ASCII output stream
// StreamCopy copier_output(Serial_out, inFiltered);

void setup() {
// Setup logging
Serial.begin(115200);
AudioLogger::instance().begin(Serial, AudioLogger::Warning); LOGLEVEL_AUDIODRIVER = AudioDriverWarning; delay(2000);

Serial.println("Setup starting...");

Serial.println("I2C pin ...");
my_pins.addI2C(PinFunction::CODEC, SCLPIN, SDAPIN, ES8388ADDR, I2CSPEED, myWire); Serial.println("I2S pin ...");
my_pins.addI2S(PinFunction::CODEC, MCLKPIN, BCLKPIN, WSPIN, DIPIN, DOPIN); Serial.println("Pins begin ...");
my_pins.begin();

Serial.println("Board begin ...");
// audio_board.begin();
CodecConfig cfg;
//No output to codec
cfg.output_device = DAC_OUTPUT_LINE1; //Mic input from adc channel 1 cfg.input_device = ADC_INPUT_LINE1; //Bits per sample (16 bits)
cfg.i2s.bits = BIT_LENGTH_16BITS;
//Sample Rate (44.1 kHz)
cfg.i2s.rate = RATE_8K; //cfg.i2s.rate = RATE_44K; //Channels 2
//cfg.i2s.channels = CHANNELS2;
//Format
//cfg.i2s.fmt = I2S_NORMAL;
// codec is slave - microcontroller is master //cfg.i2s.mode = MODE_SLAVE;

audio_board.begin(cfg);
//Additional ADC configuration ---> Everything else is in default mode (See datasheet)
//set to mono mix in ADC channel 1 (lin1/Mic pin) --> 00001000 == 0x08 in ADCControl 3 es8388_write_reg(ES8388_ADCCONTROL3, 0x08);
//12 dB gain in ADC channel 1 (lin1/Mic pin) --> 01000100 == 0x44 in ADCControl 1
// es8388_write_reg(ES8388_ADCCONTROL1, 0x44);

Serial.println("I2S begin ...");
auto i2s_config = i2s_out_stream.defaultConfig(RXTX_MODE); //RXTX for douplex //RX for sink //TX for source
i2s_config.copyFrom(audio_info);
i2s_out_stream.begin(i2s_config); // this should apply I2C and I2S configuration

// // Setup CSV
// Serial.println("CSV begin...");
// Serial_out.begin(audio_info);

// Setup filter
inFiltered.setFilter(0, new IIR<float>(b_coefficients, a_coefficients));

// Setup ESP_NOW
auto now_config = now.defaultConfig();
now_config.mac_address = "DC:54:75:C3:B8:0C"; now.begin(now_config);
now.addPeers(peers);

Serial.println("Setup completed ...");
delay(5000);
}

// Arduino loop - copy sound to out void loop() {
//copier_output.copy();
copier_now.copy();
}

### ESP32-S3 Feather Sound Receiver Arduino Code: The receiver code for the Sound Sensor module receives the information from the ESP32

sender (through ESPNow) and displays it to the serial monitor.

/**
* @file example-serial-receive.ino
* @author Phil Schatzmann
* @brief Receiving audio via ESPNow * @version 0.1
* @date 2022-03-09
*
* @copyright Copyright (c) 2022

*/

#include "AudioTools.h"

#include "Communication/ESPNowStream.h"

AudioInfo info(32000, 1, 16);
ESPNowStream now;
CsvOutput<int16_t> Serial_out(Serial); | // ASCII output stream
StreamCopy copier_output(Serial_out, now);
const char *peers[] = {"DC:54:75:C3:B8:0C"};

void setup() {
Serial.begin(115200);
AudioLogger::instance().begin(Serial, AudioLogger::Info);

auto now_cfg = now.defaultConfig(); now_cfg.mac_address = "DC:54:75:C0:92:28"; now.begin(now_cfg);
now.addPeers(peers);

// Setup CSV
Serial.println("CSV begin..."); Serial_out.begin(info);

Serial.println("Receiver started..."); }

void loop() {
copier_output.copy();
}

### MATLAB Sound Sensor Filter Code: The filter code in MATLAB is a tool that allows the user to create IIR LPF, IIR HPF, and

IIR BPF of Butterworth type with different orders of magnitude. It requires the user to include a cutoff frequency for the LPF, a cutoff frequency for the HPF, a sampling frequency, and the order of the filters. The code will return the coefficients of the difference equation that will be included in the sender Arduino Code for the Sound Sensor module.

fc_l = 1150; % Cutoff frequency for LPF
fc_h = 100; | % Cutoff frequency for HPF
fs = 8000; | % Sampling Frequency

% 2nd order LPF
[b_l,a_l] = butter(2,fc_l/(fs/2)); %freqz(b_l,a_l,[],fs);
%subplot(2,1,1);

% 2nd order HPF
[b_h,a_h] = butter(2,fc_h/(fs/2), 'high'); %freqz(b_h,a_h,[],fs);
%subplot(2,1,1);

% Multiply the transfer functions to create a bandpass filter % Create transfer function objects for LPF and HPF tf_lpf = tf(b_l, a_l, 1/fs) % LPF transfer function
tf_hpf = tf(b_h, a_h, 1/fs) % HPF transfer function
% Multiply the transfer functions to create a bandpass filter
tf_bpf = tf_lpf * tf_hpf
% Get the numerator and denominator coefficients of the bandpass filter [b_bpf, a_bpf] = tfdata(tf_bpf, 'v');

freqz(b_bpf,a_bpf,[],fs);
subplot(2,1,1);

% DC Gain
dc_gain = sum(b_bpf) / sum(a_bpf);

### 5.3 TEMPERATURE

### ESP32-S3 Feather Temperature Arduino Sender Code: This code is the Arduino code for the Temperature sensor. The biggest aspect of this code

is the Steinhart-Hart equation that converts resistance differences into Kelvins.

#include <Arduino.h>

#include <math.h>

#include <esp_now.h>

#include <WiFi.h>

// Include Wire Library for I2C
#include <Wire.h>

// Include Adafruit Graphics & OLED libraries #include <Adafruit_GFX.h>
#include <Adafruit_SSD1306.h>

#include "Adafruit_MAX1704X.h" /////////////////////////////////

int ThermVb = A0;
int ThermVd = A1;
float Vb;
float Vd;
float Vin = 3290;
float Vdiff;
float R1 = 9820;
float R2 = 9897;
float R3 = 9860;

float R4;
float Temps;
float A = 0.001111285538;
float B = 0.0002371215953; float C = 0.00000007520676806;

int i = 0;
float Temptot = 0;
float Tempave = 0;

/////////////////////////////////

uint8_t broadcastAddress[] = {0xDC, 0x54, 0x75, 0xC3, 0xBE, 0xFC};

typedef struct Temp{
double Temp;
} Temp;
Temp TempData;

esp_now_peer_info_t peerInfo;

//calibration input from master typedef struct TempR{
unsigned int R1;
unsigned int R2;
unsigned int R3;
} TempR;

TempR TempCali;
//icons for oled
const unsigned char Battery_100 [] = {
0x00, 0x00, 0x00, 0x00, 0x00, 0x00, 0x00, 0x00, 0x00, 0x00, 0x00, 0x00, 0x00, 0x00, 0x00, 0x00, 0x00, 0x00, 0x00, 0x00, 0x00, 0x00, 0x00, 0x00, 0x00, 0x00, 0x00, 0x00, 0x00, 0x00, 0x00, 0x00, 0x00, 0x00, 0x00, 0x00, 0x3F, 0xFF, 0xFF, 0xF0, 0x40, 0x00, 0x00, 0x10, 0x47, 0x3C, 0xE7, 0x18, 0x47, 0xBD, 0xE7, 0x98, 0x45, 0xA5, 0xA5, 0x9E, 0x45, 0xA5, 0xA5, 0x9A, 0x45, 0xA5, 0xA5, 0x9A, 0x45, 0xA5, 0xA5, 0x9A, 0x45, 0xA5, 0xA5, 0x9A, 0x45, 0xA5, 0xA5, 0x9E, 0x47, 0xBD, 0xE7, 0x98, 0x47, 0x3C, 0xE7, 0x18, 0x40, 0x00, 0x00, 0x10, 0x3F, 0xFF, 0xFF, 0xF0, 0x00, 0x00, 0x00, 0x00, 0x00, 0x00, 0x00, 0x00, 0x00, 0x00, 0x00, 0x00, 0x00, 0x00, 0x00, 0x00, 0x00, 0x00, 0x00, 0x00, 0x00, 0x00, 0x00, 0x00, 0x00, 0x00, 0x00, 0x00, 0x00, 0x00, 0x00, 0x00, 0x00, 0x00, 0x00, 0x00
};

const unsigned char temprature [] = {
0x00, 0x00, 0x00, 0x00, 0x60, 0x00, 0x01, 0xF8, 0x00, 0x01, 0x08, 0x00, 0x03, 0x0C, 0x00, 0x03, 0x6D, 0xC0, 0x03, 0x6C, 0x00, 0x03, 0x6D, 0xE0, 0x03, 0x69, 0xE0, 0x03, 0x60, 0x00, 0x03, 0x61, 0xC0, 0x03, 0x60, 0x00, 0x03, 0x6D, 0xE0, 0x03, 0x6D, 0xE0, 0x03, 0x6C, 0x00, 0x06, 0xF6, 0x00, 0x05, 0x9A, 0x00, 0x05, 0x9A, 0x00, 0x05, 0x92, 0x00, 0x06, 0xF6, 0x00, 0x03, 0x0C, 0x00, 0x01, 0xF8, 0x00, 0x00, 0x60, 0x00, 0x00, 0x00, 0x00,
};

// Reset pin not used but needed for library #define OLED_RESET -1
Adafruit_SSD1306 display(OLED_RESET);

Adafruit_MAX17048 maxlipo;

//debounce of button
// Constants for debounce
const int BUTTON_PIN = 10;
const unsigned long DEBOUNCE_DELAY = 50;
const unsigned long RESET_DURATION = 5000; // 5 seconds volatile int buttonState = HIGH;
volatile int lastButtonState = HIGH;
volatile unsigned long lastDebounceTime = 0;
volatile unsigned long buttonPressStartTime = 0;
volatile bool resetTriggered = false;
unsigned long lastDisplayUpdateTime = 0;
const unsigned long displayUpdateInterval = 1000; //# of iterations before oled update unsigned long lastTempCalcTime = 0 ;
const unsigned long TEMP_CALC_INTERVAL = 15;

//define diferent states for oled
typedef enum stateDsiplay {Bat, Data}
stateType;

volatile stateType oledDisplay = Bat;

//interupt func for different states of oled when button is pressed void handleButtonPress() {
unsigned long currentMillis = millis();

// Check if enough time has passed since the last button press
if (currentMillis - lastDebounceTime > DEBOUNCE_DELAY) { int reading = digitalRead(BUTTON_PIN);

if (reading != lastButtonState) {
lastDebounceTime = currentMillis;
lastButtonState = reading;

if (lastButtonState == HIGH) {
// Button pressed, start/reset the timer buttonPressStartTime = currentMillis;
resetTriggered = false;
} else {
// Button released, reset timer and trigger reset if held for 5 seconds buttonPressStartTime = 0;

resetTriggered = false;
}

// Move this part outside the inner if statement if (lastButtonState == HIGH) {
// Button pressed, toggle OLED display state if (oledDisplay == Bat) {
oledDisplay = Data;
} else {
oledDisplay = Bat;
}
}
}
}
}

float calctemp(float R4) {
Temps = 1/(A + B * log(R4) + C * pow(log(R4), 3)); Temps = (Temps-273.15);
return Temps;
}

void OnDataSent(const uint8_t *mac_addr, esp_now_send_status_t status) { Serial.print("\r\nLast Packet Send Status:\t");
Serial.println(status == ESP_NOW_SEND_SUCCESS ? "Delivery Success" : "Delivery Fail"); }

// Callback function executed when data is received
void OnDataRecv(const uint8_t * mac, const uint8_t *incomingData, int len) { memcpy(&TempCali, incomingData, sizeof(TempCali));
R1 = TempCali.R1;
R2 = TempCali.R2;
R3 = TempCali.R3;
}
/////////////////////////////////
void updateDisplay() {
display.clearDisplay();
// switch case for oled state
switch (oledDisplay)
{
//display battery precent and charge discharge rate case Bat:

display.setTextSize(1.3);
display.drawBitmap(0,4,Battery_100,32,32,1);
display.setCursor(42,0);
display.print("ChgR:");display.print(maxlipo.chargeRate()); display.print(" %/hr"); display.setCursor(40,15);
display.print("Bat:");display.print(maxlipo.cellPercent(), 1); display.print(" %");

break;
//display temp
case Data:
display.setTextSize(1.3);
display.drawBitmap(0,4,temprature,24,24,1); display.setCursor(42,0);
display.print("Temp:");display.print(Tempave);display.print(" *C"); display.setCursor(42,7);
display.setTextSize(0.5);
display.print("R1:");display.print(R1);
display.setCursor(42,16);
display.print("R2:");display.print(R2); display.setCursor(42,26);
display.print("R3:");display.print(R3); break;
}
display.display();

}
/////////////////////////////////

void setup() {
Serial.begin(9600);
delay(500);

/////////////////////////////////

// Set device as a Wi-Fi Station WiFi.mode(WIFI_STA);

// Init ESP-NOW
if (esp_now_init() != ESP_OK) { Serial.println("Error initializing ESP-NOW");
return;
}

// Once ESPNow is successfully Init, we will register for Send CB to // get the status of Trasnmitted packet esp_now_register_send_cb(OnDataSent);
// Register callback function
esp_now_register_recv_cb(OnDataRecv);
// Register peer
memcpy(peerInfo.peer_addr, broadcastAddress, 6); peerInfo.channel = 0;
peerInfo.encrypt = false;

// Add peer
if (esp_now_add_peer(&peerInfo) != ESP_OK){

Serial.println("Failed to add peer"); return;
}

/////////////////////////////////

//INIT oled button
pinMode(10,INPUT);
attachInterrupt(digitalPinToInterrupt(BUTTON_PIN), handleButtonPress, CHANGE); esp_sleep_enable_ext0_wakeup(GPIO_NUM_10,1); //wake up pin if module is in deep sleep // Start Wire library for I2C
Wire.begin();
// initialize OLED with I2C addr 0x3C
display.begin(SSD1306_SWITCHCAPVCC, 0x3C);
// Clear the display
display.clearDisplay();
//Set the color - always use white despite actual display color display.setTextColor(WHITE);
//Set the font size
display.setTextSize(1.5);
//Set the cursor coordinates display.setCursor(0,0);
display.print("Temp Sensor Config..."); display.display();
delay(1000);
//check if max module is present if not send error
if (!maxlipo.begin()) {
Serial.println(F("Couldnt find Adafruit MAX17048?\nMake sure a battery is plugged in!")); while (1) delay(10);
}
}

void loop() {

//reset button
unsigned long currentMillis = millis();

// Check if the button is being held down for 5 seconds
if (buttonPressStartTime != 0 && !resetTriggered && currentMillis - buttonPressStartTime >= RESET_DURATION) {
// Button held for 5 seconds, trigger reset
resetTriggered = true;

display.clearDisplay();
display.setCursor(0,0);
display.println("Entering DeepSleep"); display.println("GOOD NIGHT"); display.display();

delay(5000);
display.clearDisplay();
display.display();
esp_deep_sleep_start();
}

// Check if 10 milliseconds have passed since the last temperature calculation if (currentMillis - lastTempCalcTime >= TEMP_CALC_INTERVAL) { // Perform temperature calculation
Vb = analogReadMilliVolts(ThermVb);
Vd = analogReadMilliVolts(ThermVd);

Vdiff = Vb - Vd;
R4 = R3 / (R2 / (R1 + R2) - Vdiff / Vin) - R3;

Temps = calctemp(R4);

if (i == 100) {
Tempave = Temptot / i;
Tempave = Tempave * 100;
Tempave = round(Tempave);
Tempave = Tempave / 100;
i = 0;
Temptot = 0;
Serial.println(Tempave);

TempData.Temp = Tempave;
}

i = i + 1;
Temptot = Temptot + Temps;

// Update the last temperature calculation time lastTempCalcTime = currentMillis;
}

// Check for display update based on time
if (currentMillis - lastDisplayUpdateTime >= displayUpdateInterval) { updateDisplay();
lastDisplayUpdateTime = currentMillis;
}
esp_err_t result = esp_now_send(broadcastAddress, (uint8_t *) &TempData, sizeof(TempData)); if (result == ESP_OK) {
Serial.println("Sent with success");
}
else {
Serial.println("Error sending the data"); }

}

### 5.4 IMPEDANCE

### ESP32-S3 Feather Impedance Arduino Code: This code is the Arduino code for the impedance sensor. It communicates using the I2C

protocol.

#include "Wire.h"

#include <math.h>

#include <esp_now.h>

#include <WiFi.h>

#include <Adafruit_GFX.h>

#include <Adafruit_SSD1306.h>

#include "Adafruit_MAX1704X.h"

// Configure the registers (refer to the AD5933 Datasheet) #define SLAVE_ADDR 0x0D
#define ADDR_PTR 0xB0

#define START_FREQ_R1 0x82

#define START_FREQ_R2 0x83 #define START_FREQ_R3 0x84

#define FREG_INCRE_R1 0x85 #define FREG_INCRE_R2 0x86 #define FREG_INCRE_R3 0x87

#define NUM_INCRE_R1 0x88

#define NUM_INCRE_R2 0x89

#define NUM_SCYCLES_R1 0x8A #define NUM_SCYCLES_R2 0x8B

#define RE_DATA_R1 0x94

#define RE_DATA_R2 0x95

#define IMG_DATA_R1 0x96

#define IMG_DATA_R2 0x97

#define TEMP_R1 0x92

#define TEMP_R2 0x93

#define CTRL_REG 0x80

#define CTRL_REG2 0x81

#define STATUS_REG 0x8F

const float MCLK = 16.776*pow(10,6); // AD5933 Internal Clock Speed 16.776 MHz const float start_freq = 50*pow(10,3); // Set start freq, < 100Khz
const float incre_freq = 1*pow(10,2); // Set freq increment
const int incre_num = 49; // Set number of increments; < 511

// Initialized the receive data from the receiver
bool cal = 0;
bool measure = 1;

char state;
double gainFactor = 0.0;

// Receiver MAC address
uint8_t broadcastAddress[] = {0xDC, 0x54, 0x75, 0xC3, 0xBE, 0xFC};

typedef struct Imp{ //Send to receiver
double Impavg;
double Imps;
} Imp;
Imp ImpData;

esp_now_peer_info_t peerInfo;

//calibration input from master typedef struct ImpFlag{
bool cal;
bool measure;
} ImpFlag;
ImpFlag Flag;

//icons for oled
const unsigned char Battery_100 [] = {
0x00, 0x00, 0x00, 0x00, 0x00, 0x00, 0x00, 0x00, 0x00, 0x00, 0x00, 0x00, 0x00, 0x00, 0x00, 0x00, 0x00, 0x00, 0x00, 0x00, 0x00, 0x00, 0x00, 0x00, 0x00, 0x00, 0x00, 0x00, 0x00, 0x00, 0x00, 0x00, 0x00, 0x00, 0x00, 0x00, 0x3F, 0xFF, 0xFF, 0xF0, 0x40, 0x00, 0x00, 0x10, 0x47, 0x3C, 0xE7, 0x18, 0x47, 0xBD, 0xE7, 0x98, 0x45, 0xA5, 0xA5, 0x9E, 0x45, 0xA5, 0xA5, 0x9A, 0x45, 0xA5, 0xA5, 0x9A, 0x45, 0xA5, 0xA5, 0x9A, 0x45, 0xA5, 0xA5, 0x9A, 0x45, 0xA5, 0xA5, 0x9E, 0x47, 0xBD, 0xE7, 0x98, 0x47, 0x3C, 0xE7, 0x18, 0x40, 0x00, 0x00, 0x10, 0x3F, 0xFF, 0xFF, 0xF0, 0x00, 0x00, 0x00, 0x00, 0x00, 0x00, 0x00, 0x00, 0x00, 0x00, 0x00, 0x00, 0x00, 0x00, 0x00, 0x00, 0x00, 0x00, 0x00, 0x00, 0x00, 0x00, 0x00, 0x00, 0x00, 0x00, 0x00, 0x00, 0x00, 0x00, 0x00, 0x00, 0x00, 0x00, 0x00, 0x00
};

const unsigned char Imp_screen [] = {
0x00, 0x00, 0x00, 0x00, 0x00, 0x00, 0x00, 0x00, 0x00, 0x00, 0x00, 0x00, 0x00, 0x00, 0x00, 0x00, 0x00, 0x00, 0x00, 0x00, 0x00, 0x00, 0x00, 0x00, 0x00, 0x00, 0x00, 0x00, 0x00, 0x00, 0x00, 0x00, 0x00, 0x07, 0xe0, 0x00, 0x00, 0x1f, 0xf8, 0x00, 0x00, 0x3c, 0x3c, 0x00, 0x00, 0x73, 0xce, 0x00, 0x00, 0x67, 0xe6, 0x00, 0x1e, 0xee, 0x77, 0x78, 0x3f, 0xcc, 0x33, 0xfc, 0x33, 0xcc, 0x33, 0xcc, 0x33, 0xce, 0x73, 0xcc, 0x3f, 0xde, 0x7b, 0xfc, 0x1e, 0xfe, 0x7f, 0x78, 0x00, 0x60, 0x06, 0x00, 0x00, 0x70, 0x0e, 0x00, 0x00, 0x3c, 0x3c, 0x00, 0x00, 0x1f, 0xf8, 0x00, 0x00, 0x07, 0xe0, 0x00,

0x00, 0x00, 0x00, 0x00, 0x00, 0x00, 0x00, 0x00, 0x00, 0x00, 0x00, 0x00, 0x00, 0x00, 0x00, 0x00, 0x00, 0x00, 0x00, 0x00, 0x00, 0x00, 0x00, 0x00, 0x00, 0x00, 0x00, 0x00, 0x00, 0x00, 0x00, 0x00 };

// Reset pin not used but needed for library
#define OLED_RESET -1

Adafruit_SSD1306 display(OLED_RESET);

Adafruit_MAX17048 maxlipo;

//debounce of button
//Constants for debounce
const int BUTTON_PIN = 9;
const unsigned long DEBOUNCE_DELAY = 50;
const unsigned long RESET_DURATION = 5000; // 5 seconds volatile int buttonState = HIGH;
volatile int lastButtonState = HIGH;
volatile unsigned long lastDebounceTime = 0;
volatile unsigned long buttonPressStartTime = 0;
volatile bool resetTriggered = false;
unsigned long lastDisplayUpdateTime = 0;
const unsigned long displayUpdateInterval = 1000; //# of iterations before oled update

//define diferent states for oled
typedef enum stateDsiplay {Bat, Data}
stateType;

volatile stateType oledDisplay = Bat;

//interupt func for different states of oled when button is pressed void handleButtonPress() {
unsigned long currentMillis = millis();

// Check if enough time has passed since the last button press
if (currentMillis - lastDebounceTime > DEBOUNCE_DELAY) { int reading = digitalRead(BUTTON_PIN);

if (reading != lastButtonState) {
lastDebounceTime = currentMillis;
lastButtonState = reading;

if (lastButtonState == HIGH) {
// Button pressed, start/reset the timer buttonPressStartTime = currentMillis; resetTriggered = false;
}
else {
// Button released, reset timer and trigger reset if held for 5 seconds buttonPressStartTime = 0;

resetTriggered = false;
}

// Move this part outside the inner if statement if (lastButtonState == LOW) {
// Button pressed, toggle OLED display state if (oledDisplay == Bat) {
oledDisplay = Data;
}
else {
oledDisplay = Bat;
}
}
}
}
}

void OnDataSent(const uint8_t *mac_addr, esp_now_send_status_t status) { Serial.print("\r\nLast Packet Send Status:\t");
Serial.println(status == ESP_NOW_SEND_SUCCESS ? "Delivery Success" : "Delivery Fail"); }

// Callback function executed when data is received
void OnDataRecv(const uint8_t * mac, const uint8_t *incomingData, int len) {
memcpy(&Flag, incomingData, sizeof(Flag));
cal = Flag.cal;
measure = Flag.measure;
}

/////////////////////////////////
void updateDisplay() {
display.clearDisplay();

// switch case for oled state
switch (oledDisplay) {

//display battery precent and charge discharge rate case Bat:
display.setTextSize(1.3);
display.drawBitmap(0,4, Battery_100 ,32,32,1); display.setCursor(42,0);
display.print("ChgR:");
display.print(maxlipo.chargeRate()); display.print(" %/hr");
display.setCursor(40,15);
display.print("Bat:");
display.print(maxlipo.cellPercent(), 1); display.print(" %");
display.display();

break;

//display imp
case Data:
display.setTextSize(1.3);
display.drawBitmap(0,4, Imp_screen ,32,32,1); display.setCursor(42,0);
display.print("Impedance:"); display.setCursor(40,15);
display.print(ImpData.Impavg); display.print(" ohm");
display.display();
break;
}
}
/////////////////////////////
void setup() {
Wire.begin();
Serial.begin(115200);
delay(500);
pinMode(12, OUTPUT);
/////////////////////////////////

// Set device as a Wi-Fi Station WiFi.mode(WIFI_STA);

// Init ESP-NOW
if (esp_now_init() != ESP_OK) { Serial.println("Error initializing ESP-NOW");
return;
}

// Once ESPNow is successfully Init, we will register for Send CB to

// Register callback function
esp_now_register_recv_cb(OnDataRecv);
// Register peer
memcpy(peerInfo.peer_addr, broadcastAddress, 6); peerInfo.channel = 0;
peerInfo.encrypt = false;

// Add peer
if (esp_now_add_peer(&peerInfo) != ESP_OK){ Serial.println("Failed to add peer");
return;
}

//INIT oled button pinMode(BUTTON_PIN, INPUT); attachInterrupt(digitalPinToInterrupt(BUTTON_PIN), handleButtonPress, CHANGE); esp_sleep_enable_ext0_wakeup(GPIO_NUM_9,1); //wake
// Start Wire library for I2C
//Wire.begin();
// initialize OLED with I2C addr 0x3C display.begin(SSD1306_SWITCHCAPVCC, 0x3C);
// Clear the display
display.clearDisplay();
//Set the color - always use white despite actual display color display.setTextColor(WHITE);
//Set the font size
display.setTextSize(1.5);
//Set the cursor coordinates display.setCursor(0,0);
display.print("Imp Sensor Config..."); display.display();
delay(1000);
//check if max module is present if not send error
if (!maxlipo.begin()) {
Serial.println(F("Couldnt find Adafruit MAX17048?\nMake sure a battery is plugged in!")); while (1) delay(10);
}

//nop - clear ctrl-reg
writeData(CTRL_REG,0x0);

//reset ctrl register
writeData(CTRL_REG2,0x10);

programReg();
calibrateGainFactor();
}

void loop(){
//reset button
unsigned long currentMillis = millis();

// Check if the button is being held down for 5 seconds
if (buttonPressStartTime != 0 && !resetTriggered && currentMillis - buttonPressStartTime >= RESET_DURATION) {
// Button held for 5 seconds, trigger reset
resetTriggered = true;
display.clearDisplay();
display.setCursor(0,0);
display.println("Entering DeepSleep"); display.println("GOOD NIGHT"); display.display();
delay(5000);

display.clearDisplay();
display.display();
esp_deep_sleep_start();
}
if (cal == 1) {
ESP.restart();
cal = 0;
}
if (measure == 1) {
runSweep();
delay(1000);
measure = 0;
}
Serial.flush();

if (currentMillis - lastDisplayUpdateTime >= displayUpdateInterval) { updateDisplay();
lastDisplayUpdateTime = currentMillis;
}
}

void calibrateGainFactor() { short re;
short img;
double freq;
float mag;
float magtot = 0;
float magavg;
int i=0;

programReg();
digitalWrite(12, HIGH);
delay(100);

// 1. Standby '10110000' Mask D8-10 of avoid tampering with gains
writeData(CTRL_REG,(readData(CTRL_REG) & 0x07) | 0xB0);

// 2. Initialize sweep
writeData(CTRL_REG,(readData(CTRL_REG) & 0x07) | 0x10);

// 3. Start sweep
writeData(CTRL_REG,(readData(CTRL_REG) & 0x07) | 0x20);

while((readData(STATUS_REG) & 0x07) < 4 ) { // Check that status reg != 4, sweep not complete delay(100); // delay between measurements

int flag = readData(STATUS_REG)& 2;

if (flag==2) {

byte R1 = readData(RE_DATA_R1); byte R2 = readData(RE_DATA_R2);
re = (R1 << 8) | R2;

R1 = readData(IMG_DATA_R1); R2 = readData(IMG_DATA_R2);
img = (R1 << 8) | R2;

freq = start_freq + i*incre_freq;
mag = sqrt(pow(double(re),2)+pow(double(img),2)); magtot = magtot + mag;
Serial.print("mag:");
Serial.println(mag);
if((readData(STATUS_REG) & 0x07) < 4 ){
writeData(CTRL_REG,(readData(CTRL_REG) & 0x07) | 0x30);
i++;
}
}
}
int count = 50;
magavg = magtot / count;
gainFactor = (1.0 /2000.0) / magavg; Serial.print("Mag Avg: "); Serial.println(magavg);
Serial.print("GF: ");
Serial.println(gainFactor, 16);
digitalWrite(12, LOW);
delay(100);
writeData(CTRL_REG,(readData(CTRL_REG) & 0x07) | 0xA0);
}

void programReg(){

// Set Range 1, PGA gain 1 writeData(CTRL_REG,0x01);

// Set settling cycles
writeData(NUM_SCYCLES_R1, 0x07); writeData(NUM_SCYCLES_R2, 0xFF);

// Start frequency of 1kHz
writeData(START_FREQ_R1, getFrequency(start_freq,1)); writeData(START_FREQ_R2, getFrequency(start_freq,2)); writeData(START_FREQ_R3, getFrequency(start_freq,3));

// Increment by 1 kHz
writeData(FREG_INCRE_R1, getFrequency(incre_freq,1)); writeData(FREG_INCRE_R2, getFrequency(incre_freq,2)); writeData(FREG_INCRE_R3, getFrequency(incre_freq,3));

// Points in frequency sweep (100), max 511 writeData(NUM_INCRE_R1, (incre_num & 0x001F00)>>0x08 ); writeData(NUM_INCRE_R2, (incre_num & 0x0000FF));
}

void runSweep() {
short re;
short img;
double freq;
double mag;
double phase;
double gain;
double Impedance;
double GF;
double FFW;
double wt;
double ht;
double BF;
double tot = 0;
double magcount = 0;
double impcount = 0;
double avgmag;
double totimp = 0;
double avgimp;
double totreac = 0;
double avgreac;
double totre;
double avgre;
int i=0;
int A;
int G;

programReg();
delay(100);

// 1. Standby '10110000' Mask D8-10 of avoid tampering with gains
writeData(CTRL_REG,(readData(CTRL_REG) & 0x07) | 0xB0);

// 2. Initialize sweep
writeData(CTRL_REG,(readData(CTRL_REG) & 0x07) | 0x10);

// 3. Start sweep
writeData(CTRL_REG,(readData(CTRL_REG) & 0x07) | 0x20);

while((readData(STATUS_REG) & 0x07) < 4 ) { // Check that status reg != 4, sweep not complete delay(100); // delay between measurements

int flag = readData(STATUS_REG)& 2;

if (flag==2) {

byte R1 = readData(RE_DATA_R1); byte R2 = readData(RE_DATA_R2);
re = (R1 << 8) | R2;
totre = totre + re;

R1 = readData(IMG_DATA_R1); R2 = readData(IMG_DATA_R2);
img = (R1 << 8) | R2;
totreac = totreac + img;

// debug prints
Serial.print("real:"); Serial.println(re); Serial.print("img:"); Serial.println(img); phase = atan(double(img)/double(re)); phase = (180.0/3.1415926)*phase; //convert phase angle to degrees

freq = start_freq + i*incre_freq;
mag = sqrt(pow(double(re),2)+pow(double(img),2));

// debug print
Serial.print("phase:"); Serial.println(phase); Serial.print("mag:"); Serial.println(mag);

tot = tot+mag;
Impedance = (1/(gainFactor*mag));
ImpData.Imps = Impedance;
esp_err_t result = esp_now_send(broadcastAddress, (uint8_t *) &ImpData, sizeof(ImpData)); if (result == ESP_OK) {
Serial.println("Sent with success");
}
else {
Serial.println("Error sending the data");
}

// Update impedance count and total impedance for all impedance values //impcount = 50;
totimp = totimp + Impedance;

Serial.print("Frequency: "); Serial.print(freq/1000);

Serial.print(",kHz;");

Serial.print(" Impedance Magnitude: "); Serial.print(Impedance);
Serial.println(";");

// break; //TODO: for single run, remove after debugging

//Increment frequency
if((readData(STATUS_REG) & 0x07) < 4 ){
writeData(CTRL_REG,(readData(CTRL_REG) & 0x07) | 0x30);
i++;
}
}
}

int count = 50;
avgmag = tot/count;
avgimp = totimp/count;
avgreac = totreac/count;
avgre = totre/count;

// Uncomment below if want to measure body fat from the impedance sensor. Body fat calculations are made in the GUI.
// wt = 82; //lbsC
// ht = 167; //cm, m

//FFW = (0.396*((pow(ht,2))/(avgimp/200))+ (0.143 * wt) + 8.399)*1.37*2; //instruc // Serial.print ("FFM: ");
// Serial.println (FFW);
// BF = ((wt-FFW)/wt)*100;

Serial.print(" Avg Mag: "); Serial.print(avgmag);
Serial.print(",");

Serial.print(" Avg Impedance: "); Serial.print(avgimp);
Serial.print(",");
ImpData.Impavg = avgimp;
esp_err_t result = esp_now_send(broadcastAddress, (uint8_t *) &ImpData, sizeof(ImpData)); if (result == ESP_OK) {
Serial.println("Sent with success");
}
else {
Serial.println("Error sending the data"); }
// Serial.print(" % Body Fat: ");

// Serial.print(BF);
// Serial.print(",");

//Power down
writeData(CTRL_REG,0xA0);
//digitalWrite(12, LOW);
delay(100);
writeData(CTRL_REG,(readData(CTRL_REG) & 0x07) | 0xA0);
}

void writeData(int addr, int data) {

Wire.beginTransmission(SLAVE_ADDR); Wire.write(addr);
Wire.write(data);
Wire.endTransmission();
delay(1);
}

int readData(int addr){
int data;

Wire.beginTransmission(SLAVE_ADDR); Wire.write(ADDR_PTR);
Wire.write(addr);
Wire.endTransmission();

delay(1);

Wire.requestFrom(SLAVE_ADDR,1);

if (Wire.available() >= 1){
data = Wire.read();
}
else {
data = -1;
}

delay(1);
return data;
}

byte getFrequency(float freq, int n){
long val = long((freq/(MCLK/4)) * pow(2,27)); byte code;

switch (n) {
case 1:
code = (val & 0xFF0000) >> 0x10;

break;

case 2:
code = (val & 0x00FF00) >> 0x08; break;

case 3:
code = (val & 0x0000FF);
break;

default:
code = 0;
}

return code;
}

### 5.5 PULSE OXIMETER

### ESP32-S3 Feather Pulse Ox Arduino Sender Code: This code is the Arduino code for the Pulse ox sensor. It takes advantage of the library

Protocentral_afe44xx in order to calculate the SpO2 and Heart Rate of the users.

#include <Arduino.h>

#include <SPI.h>

#include <esp_now.h>

#include <WiFi.h>

#include "protocentral_afe44xx.h"

// Include Wire Library for I2C
#include <Wire.h>

// Include Adafruit Graphics & OLED libraries #include <Adafruit_GFX.h>
#include <Adafruit_SSD1306.h>

#include "Adafruit_MAX1704X.h"

// MAC Address of responder - edit as required
uint8_t broadcastAddress[] = {0xDC, 0x54, 0x75, 0xC3, 0xBE, 0xFC}; // Must match the receiver structure
typedef struct OXI {
uint16_t IR; // Use uint16_t for IR to save space
uint16_t RED; // Use uint16_t for RED to save space uint8_t BPM;
uint8_t SPO2;
} OXI;

// Create a structured object OXI MediData;
esp_now_peer_info_t peerInfo; //icons for oled const unsigned char Battery_100 [] = {
0x00, 0x00, 0x00, 0x00, 0x00, 0x00, 0x00, 0x00, 0x00, 0x00, 0x00, 0x00, 0x00, 0x00, 0x00, 0x00, 0x00, 0x00, 0x00, 0x00, 0x00, 0x00, 0x00, 0x00, 0x00, 0x00, 0x00, 0x00, 0x00, 0x00, 0x00, 0x00, 0x00, 0x00, 0x00, 0x00, 0x3F, 0xFF, 0xFF, 0xF0, 0x40, 0x00, 0x00, 0x10, 0x47, 0x3C, 0xE7, 0x18, 0x47, 0xBD, 0xE7, 0x98, 0x45, 0xA5, 0xA5, 0x9E, 0x45, 0xA5, 0xA5, 0x9A, 0x45, 0xA5, 0xA5, 0x9A, 0x45, 0xA5, 0xA5, 0x9A, 0x45, 0xA5, 0xA5, 0x9A, 0x45, 0xA5, 0xA5, 0x9E, 0x47, 0xBD, 0xE7, 0x98, 0x47, 0x3C, 0xE7, 0x18, 0x40, 0x00, 0x00, 0x10, 0x3F, 0xFF, 0xFF, 0xF0, 0x00, 0x00, 0x00, 0x00, 0x00, 0x00, 0x00, 0x00, 0x00, 0x00, 0x00, 0x00, 0x00, 0x00, 0x00, 0x00, 0x00, 0x00, 0x00, 0x00, 0x00, 0x00, 0x00, 0x00, 0x00, 0x00, 0x00, 0x00, 0x00, 0x00, 0x00, 0x00, 0x00, 0x00, 0x00, 0x00
};
const unsigned char Heart_Pulse [] = {
0x00, 0x00, 0x00, 0x00, 0x00, 0x00, 0x00, 0x00, 0x00, 0x00, 0x00, 0x00, 0x07, 0xF8, 0x1F, 0xE0, 0x1F, 0xFC, 0x3F, 0xF8, 0x3F, 0xFE, 0x7F, 0xFC, 0x3F, 0xFF, 0xFF, 0xFC, 0x7F, 0xFF, 0xFF, 0xFE, 0x7F, 0xFF, 0xFF, 0xFE, 0xFF, 0xC7, 0xFF, 0xFF, 0xFF, 0xC7, 0xFF, 0xFF, 0xFF, 0x83, 0xE7, 0xFF, 0xFF, 0x83, 0xC3, 0xFF, 0xFF, 0x83, 0xC3, 0xFF, 0xFF, 0x01, 0x81, 0xFF, 0x00, 0x11, 0x80, 0x00, 0x00, 0x18, 0x00, 0x00, 0x00, 0x78, 0x18, 0x00, 0x1F, 0xF8, 0x1F, 0xF8, 0x0F, 0xFC, 0x3F, 0xF0, 0x07, 0xFC, 0x3F, 0xE0, 0x03, 0xFE, 0x7F, 0xC0, 0x01, 0xFF, 0xFF, 0x80, 0x00, 0xFF, 0xFF, 0x00, 0x00, 0x7F, 0xFE, 0x00, 0x00, 0x3F, 0xFC, 0x00, 0x00, 0x1F, 0xF8, 0x00, 0x00, 0x0F, 0xF0, 0x00, 0x00, 0x07, 0xE0, 0x00, 0x00, 0x01, 0x80, 0x00, 0x00, 0x00, 0x00, 0x00, 0x00, 0x00, 0x00, 0x00 };

#define AFE44XX_CS_PIN 6

#define AFE44XX_DRDY_PIN 13 #define AFE44XX_PWDN_PIN 5

// Reset pin not used but needed for library #define OLED_RESET -1
Adafruit_SSD1306 display(OLED_RESET);

Adafruit_MAX17048 maxlipo;
bool shouldEnterDeepSleep = false;
const int wakeupInterval = 15 * 1000000;

AFE44XX afe44xx(AFE44XX_CS_PIN, AFE44XX_PWDN_PIN);

afe44xx_data afe44xx_raw_data;
int32_t heart_rate_prev=0;
int32_t spo2_prev=0;

//debounce of button
// Constants for debounce
const int BUTTON_PIN = 10;
const int Deepsleeppin=9;
const unsigned long DEBOUNCE_DELAY = 50;
const unsigned long RESET_DURATION = 5000; // 5 seconds volatile int buttonState = HIGH;
volatile int lastButtonState = HIGH;

volatile unsigned long lastDebounceTime = 0; volatile unsigned long buttonPressStartTime = 0;
volatile bool resetTriggered = false;
unsigned long lastAfeReadTime = 0;
const unsigned long afeReadInterval = 8; // Adjust the interval as needed
unsigned long lastDisplayUpdateTime = 0;
const unsigned long displayUpdateInterval = 1000; //# of iterations before oled update int voltageState;

//define diferent states for oled
typedef enum stateDsiplay {Bat, Data}
stateType;

volatile stateType oledDisplay = Bat;

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

if (reading != lastButtonState) {
lastDebounceTime = currentMillis;
lastButtonState = reading;

if (lastButtonState == HIGH) {
// Button pressed, start/reset the timer buttonPressStartTime = currentMillis;
resetTriggered = false;
} else {
// Button released, reset timer and trigger reset if held for 5 seconds buttonPressStartTime = 0;
resetTriggered = false;
}

// Move this part outside the inner if statement if (lastButtonState == HIGH) {
// Button pressed, toggle OLED display state if (oledDisplay == Bat) {
oledDisplay = Data;
} else {
oledDisplay = Bat;
}
}
}
}
}

// Callback function called when data is sent
void OnDataSent(const uint8_t *mac_addr, esp_now_send_status_t status) { //Serial.print("\r\nLast Packet Send Status:\t");
// Serial.println(status == ESP_NOW_SEND_SUCCESS ? "Delivery Success" : "Delivery Fail"); }
void updateDisplay() {
// switch case for oled state
switch (oledDisplay)
{
//display battery precent and charge discharge rate case Bat:
display.clearDisplay();
display.drawBitmap(0,4,Battery_100,32,32,1);
display.setCursor(42,0);
display.print("ChgR:");display.print(maxlipo.chargeRate()); display.print(" %/hr"); display.setCursor(40,15);
display.print("Bat:");display.print(maxlipo.cellPercent(), 1); display.print(" %"); display.display();
break;
//display spo2 and heart rate
case Data:
display.clearDisplay();
display.drawBitmap(0,4,Heart_Pulse,32,32,1); display.setCursor(42,0);
if (afe44xx_raw_data.spo2 == -999){ display.print("Probe error!!!");

}
else{
if(afe44xx_raw_data.spo2 <= 80){ display.print("SPO2:");display.print("Calc...");
}
else{
display.print("SPO2:");display.print(afe44xx_raw_data.spo2);display.print(" %");
}
display.setCursor(40,15);
display.print("BPM:");display.print(afe44xx_raw_data.heart_rate);display.print(" bpm"); display.display();
break;
}
}
}

void setup()
{
/* pinMode(Deepsleeppin,INPUT_PULLUP);

voltageState = digitalRead(Deepsleeppin); if (voltageState == HIGH) {
Serial.println("Entering deep sleep");
// Configure deep sleep
esp_sleep_enable_timer_wakeup(wakeupInterval); // Wake up every 60 seconds // Enter deep sleep mode
esp_deep_sleep_start();
}
*/
Serial.begin(57600);
// Set ESP32 as a Wi-Fi Station WiFi.mode(WIFI_STA);
// Initilize ESP-NOW
if (esp_now_init() != ESP_OK) { Serial.println("Error initializing ESP-NOW"); return;
}
// Register the send callback esp_now_register_send_cb(OnDataSent);
// Register peer
memcpy(peerInfo.peer_addr, broadcastAddress, 6); peerInfo.channel = 0;
peerInfo.encrypt = false;

// Add peer
if (esp_now_add_peer(&peerInfo) != ESP_OK){ Serial.println("Failed to add peer");
return;
}

//INIT oled button
pinMode(10,INPUT);
attachInterrupt(digitalPinToInterrupt(BUTTON_PIN), handleButtonPress, CHANGE); esp_sleep_enable_ext0_wakeup(GPIO_NUM_10,1); //wake up pin if module is in deep sleep

// Start Wire library for I2C
Wire.begin();
// initialize OLED with I2C addr 0x3C display.begin(SSD1306_SWITCHCAPVCC, 0x3C);
// Clear the display
display.clearDisplay();
//Set the color - always use white despite actual display color display.setTextColor(WHITE);
//Set the font size
display.setTextSize(1.3);
//Set the cursor coordinates display.setCursor(0,0);

display.print("Pulse Oxi Config..."); display.display();
SPI.begin();
//Serial.println("Intilaziting AFE44xx.. "); delay(2000) ; // pause for a moment afe44xx.afe44xx_init();
display.clearDisplay();
display.setCursor(0,0);
display.print("Inited..."); display.display();
//Serial.println("Inited..."); delay(1000);
display.clearDisplay();
display.setCursor(0,0);
display.print("Calculating..."); //Serial.println("Calculating..."); display.display();

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

}

void loop()
{

/*voltageState = digitalRead(Deepsleeppin); // Read digital voltage switch (shouldEnterDeepSleep)
{
case true:
Serial.println("Entering deep sleep");
// Configure deep sleep
esp_sleep_enable_timer_wakeup(wakeupInterval); // Wake up every 60 seconds // Enter deep sleep mode
esp_deep_sleep_start();
Serial.println("this will never be printed");
break;

default:
break;
}
if (voltageState == HIGH) { shouldEnterDeepSleep = true;
} */
unsigned long currentMillis = millis();

// Check if the button is being held down for 5 seconds
if (buttonPressStartTime != 0 && !resetTriggered && currentMillis - buttonPressStartTime >= RESET_DURATION) {
// Button held for 5 seconds, trigger reset
resetTriggered = true;
display.clearDisplay();
display.setCursor(0,0);
display.println("Entering DeepSleep"); display.println("GOOD NIGHT"); display.display();
delay(5000);
display.clearDisplay();
display.display();
esp_deep_sleep_start();
}
delay(8);
afe44xx.get_AFE44XX_Data(&afe44xx_raw_data); //displaying raw Red Data
//Serial.println(afe44xx_raw_data.RED_data); //Serial.println(afe44xx_raw_data.IR_data); MediData.RED = afe44xx_raw_data.RED_data; MediData.IR = afe44xx_raw_data.IR_data; //buffer for spo2 and heart rate
if (afe44xx_raw_data.buffer_count_overflow) {
if(afe44xx_raw_data.spo2 == -999)
{
Serial.println("Probe error!!!!");
}
//displays new spo2 and Bpm if theres change
else if ((heart_rate_prev != afe44xx_raw_data.heart_rate) || (spo2_prev != afe44xx_raw_data.spo2)) {
heart_rate_prev = afe44xx_raw_data.heart_rate;
spo2_prev = afe44xx_raw_data.spo2;

// Serial.print("calculating sp02..."); //Serial.print(" Sp02 : "); Serial.print(afe44xx_raw_data.spo2); MediData.SPO2 = afe44xx_raw_data.spo2; // Serial.print("% ,");
// Serial.print("Pulse rate:"); Serial.print(afe44xx_raw_data.heart_rate); MediData.BPM =afe44xx_raw_data.heart_rate; // Serial.println(" bpm");

}

}
// Check for display update based on time
if (currentMillis - lastDisplayUpdateTime >= displayUpdateInterval) { updateDisplay();
lastDisplayUpdateTime = currentMillis;
}
// Send message via ESP-NOW
esp_err_t result = esp_now_send(broadcastAddress, (uint8_t *) &MediData, sizeof(MediData)); }

### 5.6 GRAPHICAL USER INTERFACE (GUI) AND RECEIVER

### Master Receiver Code: This code is the Arduino code of the ESP32-S3 Feather that is connected to the user’s

computer. The most important part of this code are the structs that separated each sensor’s data. This code also differentiates the received data using their corresponding name as a way to aid the Python GUI program later on when it comes to reading individual sensors.

#include <esp_now.h>

#include <WiFi.h>

//replace with temp sensor mac address
uint8_t tempAddress[] = {0xDC, 0x54, 0x75, 0xC3, 0xBF, 0x18}; uint8_t impad[] = {0xDC,0x54,0x75,0xC3,0x07,0x98};

// Define peerInfo structures for each peer
esp_now_peer_info_t peer1Info;
esp_now_peer_info_t peer2Info;

typedef struct TempR{
unsigned int R1 = 9820;
unsigned int R2 = 9897;
unsigned int R3 = 9860;
} TempR;
TempR TempCali;

//calibration input from master typedef struct ImpFlag{
bool cal;
bool measure;
} ImpFlag;
ImpFlag Flag;
esp_now_peer_info_t peerInfo;

// Must match the receiver structure
typedef struct OXI {
uint16_t IR; // Use uint16_t for IR to save space uint16_t RED; // Use uint16_t for RED to save space uint8_t BPM;
uint8_t SPO2;
} OXI;

typedef struct Ecg {
int ECG;
} Ecg;

typedef struct Temp{
double Temp;
} Temp;

typedef struct Imp{ //Send to receiver double Impavg;
double Imps;
} Imp;

OXI MediData;
Ecg ECGData;
Temp TempData;
Imp ImpData;

// Union to hold different types of data typedef union {
OXI mediData;
Ecg ecgData;
Temp tempData;
} DataUnion;

DataUnion receivedData;
void OnDataRecv
(const uint8_t * mac, const uint8_t *incomingData, int len) {

if (len == sizeof(OXI)) {
memcpy(&MediData, incomingData, sizeof(MediData)); Serial.print("Red Values:");
Serial.println(MediData.RED);
Serial.print("IR Values:");
Serial.println(MediData.IR);

Serial.print(" Sp02 : ");
Serial.print(MediData.SPO2); Serial.print("% ,");
Serial.print("Pulse rate:"); Serial.println(MediData.BPM); Serial.println(" bpm");
}
else if (len == sizeof(Ecg)) {
memcpy(&ECGData, incomingData, sizeof(ECGData)); Serial.print("ECG:");
Serial.println(ECGData.ECG);
}
else if (len == sizeof(Temp)) {
memcpy(&TempData, incomingData, sizeof(TempData)); Serial.print("Temperature:"); Serial.println(TempData.Temp);
}
else if (len == sizeof(Imp)) {
memcpy(&ImpData, incomingData, sizeof(ImpData)); Serial.print("ImpAvg:");
Serial.println(ImpData.Impavg); Serial.print("Imp:");
Serial.println(ImpData.Imps);
}
}

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

void handleResistorData(String R) {
// display r values if inputed
if (R.startsWith("Resistor1:")) {
// Extract and use the value, e.g., convert to integer int resistor1Value = R.substring(10).toInt(); TempCali.R1 = resistor1Value;
// Implement your logic with resistor1Value
}
else if (R.startsWith("Resistor2:")) {
int resistor2Value = R.substring(10).toInt(); TempCali.R2 = resistor2Value;
// Handle Resistor2 value
}
else if (R.startsWith("Resistor3:")) {
int resistor3Value = R.substring(10).toInt(); TempCali.R3 = resistor3Value;
// Handle Resistor3 value
}

esp_err_t result = esp_now_send(tempAddress, (uint8_t *) &TempCali, sizeof(TempCali)); }

void handleImpeadanceData(String IN){
if (IN.startsWith("Cali:")) {
// Extract the calibration flag
bool cali = 1;
Flag.cal = cali;
esp_err_t result = esp_now_send(impad, (uint8_t *) &ImpData, sizeof(ImpData)); Flag.cal = 0;
}
else if (IN.startsWith("measure:1")) {
bool meas = 1;

Serial.println("Performing impedance measurement...");
Flag.measure = meas;
esp_err_t result = esp_now_send(impad, (uint8_t *) &ImpData, sizeof(ImpData)); Flag.measure= 0;
}
}

void setup() {
// Set up Serial Monitor
Serial.begin(500000);
// Define the total number of data points pinMode(13,OUTPUT);
// Set ESP32 as a Wi-Fi Station WiFi.mode(WIFI_STA);

// Initilize ESP-NOW
if (esp_now_init() != ESP_OK) { Serial.println("Error initializing ESP-NOW"); return;
}

// Register callback function
esp_now_register_recv_cb(OnDataRecv);

// Once ESPNow is successfully Init, we will register for Send CB to // get the status of Trasnmitted packet esp_now_register_send_cb(OnDataSent);

// Register and add peer1
memcpy(peer1Info.peer_addr, tempAddress, 6); peer1Info.channel = 0;
peer1Info.encrypt = false;
if (esp_now_add_peer(&peer1Info) != ESP_OK) { Serial.println("Failed to add peer1");
return;

}

// Register and add peer2
memcpy(peer2Info.peer_addr, impad, 6); peer2Info.channel = 0;
peer2Info.encrypt = false;
if (esp_now_add_peer(&peer2Info) != ESP_OK) { Serial.println("Failed to add peer2");
return;
}

}

void loop() {
if (Serial.available() > 0) {
String receivedData = Serial.readStringUntil('\n'); // Read data until newline character //Serial.print("Received from Python: ");
//Serial.println(receivedData);
handleResistorData(receivedData);
handleImpeadanceData(receivedData); }
}

### Python Program GUI Code: This code revolves around the customtkinter library for appearances. As for the live

graphs, the library matplotlib is used. The most important aspects of the code are the pages that

### represent each sensor as well as the choosing mechanism of the main menu. In terms of the

saving aspect, the home page plays an important role since this initializes the folders needed for data to be stored.

# -*- coding: utf-8 -*-

"""
Created on Tue Oct 3 13:02:50 2023

@author: Moath Alsayar
@edited by: Carmella Ocaya
Fri Dec 29 23:59:00 2023

"""
import serial
import tkinter as tk
from tkinter import ttk
import customtkinter as ctk
import matplotlib as plt
import serial.tools.list_ports as port_list
from matplotlib.figure import Figure
from matplotlib.backends.backend_tkagg import FigureCanvasTkAgg from matplotlib.backend_bases import MouseButton

import time
import datetime
from datetime import timedelta
from matplotlib.backends.backend_tkagg import NavigationToolbar2Tk import psutil
import os
import threading
import logging
import numpy as np
LARGEFONT = ("Comic Sans", 45, "bold") MidFONT = ("Comic Sans", 25, "bold") regFont = ("Comic Sans",15,"bold" ) smallFont =("Comic Sans",13,"bold" ) ctk.set_appearance_mode("dark")

class loginPage(ctk.CTkFrame):
def __init__(self, parent, controller):
ctk.CTkFrame.__init__(self, parent)

label = ctk.CTkLabel(self, text="MediBrick2000", font=LARGEFONT, fg_color="#bf2c19", corner_radius=10)
label.pack(side="top", pady=15)

userlab=ctk.CTkLabel(self, text="Enter Username", font=MidFONT, fg_color="#bf2c19", corner_radius=10) userlab.pack()

self.warning_label = ctk.CTkLabel(self, text="Avoid \\ / : * ? \" < > |", fg_color="#bf2c19", font=("Comic Sans", 16), corner_radius=10)
self.warning_label.pack(pady=5)

self.text_input = ctk.CTkEntry(self)
self.text_input.pack(pady=5)

enter = ctk.CTkButton(self, text="Enter", font=MidFONT, command=lambda: self.on_enter_click(controller), fg_color="#bf2c19", corner_radius=10)
enter.pack(pady=5)

def show_warning_popup(self, message):
popup = tk.Toplevel()
popup.title("Warning")

label = tk.Label(popup, text=message, fg="#bf2c19") # Set the text color with fg label.pack(padx=10, pady=10)

button = tk.Button(popup, text="OK", command=popup.destroy) button.pack(pady=10)

def on_enter_click(self, controller):
# Get the user input from the text box

user_input = self.text_input.get()

# Check if the user input is empty or contains invalid characters

if not user_input or not self.is_valid_folder_name(user_input): self.show_warning_popup("Invalid folder name. Please enter a valid name") return

# Get the directory of the current Python script

current_directory = os.path.dirname(__file__)

# Create the main user folder in the current directory user_folder_path = os.path.join(current_directory, user_input)

os.makedirs(user_folder_path, exist_ok=True)

# Create subfolders inside the user folder

subfolders = ["Pulse Oximetry Data", "ECG Data", "Temperature Data", "Skin Impedance Data", "Digital Stethoscope Data"]
for subfolder in subfolders:
os.makedirs(os.path.join(user_folder_path, subfolder), exist_ok=True)

# Continue with navigating to the next frame (e.g., StartPage) controller.show_frame(StartPage)

def is_valid_folder_name(self, folder_name):
# Check if the folder name contains invalid characters invalid_characters = set(r'\/:*?"<>|.')

return not any(char in invalid_characters for char in folder_name)

class tkinterApp(tk.Tk):
def __init__(self, *args, **kwargs):
tk.Tk.__init__(self, *args, **kwargs) self.title("MediBrick2000")
container = ctk.CTkFrame(self) container.pack(side="top", fill="both", expand=True) container.grid_rowconfigure(0, weight=1) container.grid_columnconfigure(0, weight=1)
self.frames = {}
for F in (loginPage, StartPage, Page1, Page2, Page3, Page4, Page5): frame = F(container, self)
self.frames[F] = frame
frame.grid(row=0, column=0, sticky="nsew") self.show_frame(loginPage)

def show_frame(self, cont):
frame = self.frames[cont]
frame.tkraise()

class StartPage(ctk.CTkFrame):
def __init__(self, parent, controller):

ctk.CTkFrame.__init__(self, parent)

label = ctk.CTkLabel(self, text="MediBrick2000", font=LARGEFONT, fg_color="#bf2c19", corner_radius=10)
label.pack(pady = 5)

button1 = ctk.CTkButton(self, text="Pulse Oximeter", command=lambda: controller.show_frame(Page1), fg_color="#f2a138",font = regFont)
button1.pack(pady = 1)

button2 = ctk.CTkButton(self, text="Electrocardiogram (ECG)", command=lambda: controller.show_frame(Page2), fg_color="#f2a138",font = regFont)
button2.pack(pady = 1)

button3 = ctk.CTkButton(self, text="Temperature Sensor", command=lambda: controller.show_frame(Page3), fg_color="#f2a138",font = regFont)
button3.pack(pady = 1)

button4 = ctk.CTkButton(self, text="Body Fat and Water Composition (Skin Impedance)", command=lambda: controller.show_frame(Page4), fg_color="#f2a138",font = regFont)
button4.pack(pady = 1)

button5 = ctk.CTkButton(self, text="Digital Stethoscope", command=lambda: controller.show_frame(Page5), fg_color="#f2a138",font = regFont)
button5.pack(pady = 1)

port_label = ctk.CTkLabel(self, text="Select COM Port:",font = smallFont)
port_label.pack()

# Add a dropdown to select the port

ports = [port.device for port in port_list.comports()]
port_var = ctk.StringVar(self)
port_menu = ctk.CTkComboBox(self, values=ports ,variable=port_var,corner_radius=10 ) port_menu.pack()
port_var.set(ports[0] if ports else "No ports available")

baud_label = ctk.CTkLabel(self, text="Select Baud Rate:",font = smallFont) baud_label.pack()

baud_var = ctk.IntVar(self)
baud_var.set(500000)
# Convert baud rates to strings

baud_values = ["9600", "19200", "38400", "57600", "115200",'500000']
baud_menu = ctk.CTkComboBox(self, values = baud_values ,variable = baud_var,corner_radius= 10) baud_menu.pack()

connect_button = ctk.CTkButton(self, text="Connect", command=lambda: self.connect_to_serial(port_var, baud_var))
connect_button.place(x=570,y=330)

self.themeMode = "dark"
switch_button = ctk.CTkSwitch(self, command=self.toggle_theme,text="Light/Dark Mode") switch_button.place(x=3,y=3)
def toggle_theme(self):

# Add logic here to toggle the theme between light and dark mode

if self.themeMode == "dark":
ctk.set_appearance_mode("light")
self.themeMode = "light"
else:
ctk.set_appearance_mode("dark") self.themeMode = "dark"

def connect_to_serial(self, port_var, baud_var): selected_port = port_var.get()
selected_baud = baud_var.get()

try:
# Establish the serial connection

serial.Serial(selected_port, selected_baud, timeout=1)
print(f"Connected to {selected_port} at {selected_baud} baud")
# Continue with other actions (e.g., navigate to the data acquisition page) except serial.SerialException as e:

print(f"Error: {e}")
# Handle the connection error (e.g., display an error message)

class Page1(ctk.CTkFrame):
def __init__(self, parent, controller):
self.start_time = 0 # Start the time at 0 ctk.CTkFrame.__init__(self, parent) self.exit_flag = True
self.data_counter = 0
self.x_data = []
self.y_data = []
self.x_data_ir = []
self.y_data_ir = []
self.save_data = False # Make save_data a class attribute
self.line_ir = None

button1 = ctk.CTkButton(self, text="MediBrick2000 Home", command=lambda: stop_reading_and_show_home(controller), fg_color="#ed9818") button1.place(x=1,y=1)

# Create a label to display the received data

data_label = ctk.CTkLabel(self, text="Pulse Oximeter Data", font=LARGEFONT) data_label.pack()

# Create labels to display the initialization status, SPO2, and BPM

status_label = ctk.CTkLabel(self, text="Initializing AFE44xx...") status_label.pack()

spo2_label = ctk.CTkLabel(self, text="SPO2: ", font=LARGEFONT) spo2_label.pack()

bpm_label = ctk.CTkLabel(self, text="BPM: ", font=LARGEFONT) bpm_label.pack()

# Get available serial ports

ports = [port.device for port in port_list.comports()]
if not ports:
print("No serial ports available. Please check your connections.") exit(1)

# Create a combo box for selecting the serial port

port_label = ctk.CTkLabel(self, text="Select COM Port:")

port_label.pack()

port_var = ctk.StringVar(self)
port_menu = ctk.CTkComboBox(self, values=ports ,variable=port_var,corner_radius=10 ) port_menu.pack()
port_var.set(ports[0] if ports else "No ports available")

baud_label = ctk.CTkLabel(self, text="Select Baud Rate:")
baud_label.pack()

baud_var = ctk.IntVar(self)
baud_var.set(500000)
# Convert baud rates to strings

baud_values = ["9600", "19200", "38400", "57600", "115200",'500000']
baud_menu = ctk.CTkComboBox(self, values = baud_values ,variable = baud_var,corner_radius= 10) baud_menu.pack()

# Create a subframe for the Matplotlib graph

graph_frame = ttk.Frame(self)
graph_frame.pack()

# Create a Matplotlib figure and subplot

# Create a Matplotlib figure and subplot

fig = Figure(figsize=(13, 3.3), dpi=100, facecolor='dimgrey') self.ax = fig.add_subplot(111) # Define self.ax here self.ax.set_facecolor('black')
self.ax.set_xlabel('Time')
self.ax.set_ylabel('Raw Values')
self.line, = self.ax.plot([], [], 'b-')

# Create a canvas for the Matplotlib figure

canvas = FigureCanvasTkAgg(fig, master=graph_frame) canvas.draw()
canvas.get_tk_widget().pack(side=tk.TOP, fill=tk.BOTH, expand=True)

# Create an instance of the toolbar

toolbar = NavigationToolbar2Tk(canvas, self)
toolbar.pack()
toolbar.update()

#x_data, y_data = [], []
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

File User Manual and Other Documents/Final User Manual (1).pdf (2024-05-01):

USER MANUAL #24052

User Manual

Biomedical Sensor Board for Education - MediBrick 2000

ENGR 498B - #24052

Project Leader: Maria Carmella Ocaya (Biomedical Engineer)

Project Procurement Leader: Muad Alsayar (Electrical Engineer)

Michael Chase Morrett (Biosystems Engineer)

Daniel Fabricio Campana Moscoso (Electrical Engineer)

William Alec Newman (Mechanical Engineer)

Sponsor: Urs Utzinger, PhD

Mentor: Steve Larimore

Revision #6

April 29, 2024

REVISION PAGE

REVISION# | REVISION DATE | REVISION DESCRIPTION | REVISED BY
1 | 04/23/2024 | Set up the document, wrote the introduction, safety, OLED, and temperature-specific sections | Michael Morrett
2 | 04/24/2024 | Wrote Final Sensor Housing Assembly, System Startup, System Shutdown | Michael Morrett
3 | 04/27/2024 | Wrote Housing Sections | Alec Newman
4 | 04/28/2024 | Wrote Pulse Oximeter Sections | Muad Alsayar
5 | 04/29/2024 | Wrote ECG, Skin Impedance, and PCB Sections | Carmella Ocaya
6 | 04/29/2024 | Wrote Digital Stethoscope Sections | Daniel Campana

TABLE OF CONTENTS | Page No.

### 1.0 INTRODUCTION

The MediBrick 2000 was designed for Urs Utzinger, PhD, of the University of Arizona’s Department of Biomedical Engineering. It was designed through the Craig M. Berge Engineering Design Program by Project Team 24052; this team included Carmella Ocaya (Biomedical Engineering) as the Project Leader, Muad Alsayar (Electrical and Computer Engineering) as the Procurement Leader, Michael Morrett (Biosystems Engineering) as the Documentation Leader, Alec Newman (Mechanical Engineering) as the Assembly Leader, and Daniel Campana (Electrical and Computer Engineering) as the Research and Development Leader. The Project Mentor overseeing the progress of this project was Mr. Stephen Larimore.

This system is an open-source modular biomedical sensor array designed to be used in an educational setting. It is capable of measuring body temperature, skin impedance, heart ECG, pulse oximetry, heart rate, and heart sounds through detachable sensor modules. As it is a modular system, is it possible for other sensors to be utilized within this system, so long as they conform to the specifications of the sensor housings. It is also possible for microcontrollers other than the ESP32-S3 microcontroller to be used, but that would require slight redesigns or modifications to the housings and codes. For both educational institutions and private individuals wishing to use this system, it is recommended that this system is used in its base configuration first before seeking to make modifications. This would allow the User to learn how the system works and what modifications they wish to make to it before investing in making those changes.

This manual details the instructions required to assemble, calibrate, and use this system to take physiological measurements. General instructions and subsystem-specific instructions are listed in each section. For detailed information on the design of this system, please refer to the Technical Data Package, the Final Report, and the Design Documentation provided on the GitHub page of this system, linked as https://github.com/grender007/Modular-Biomedical-Sensor-Board-for-Education. The Sponsor also possesses a GitHub repository where he posts information and designs for his version of this project and additional sensors, linked as https://github.com/uutzinger/BioMedicalSensorBoard.

We the design team appreciate you using the MediBrick 2000, and we hope this system meets your needs.

### 2.0 SAFETY INSTRUCTIONS

This section details the safety information for the MediBrick 2000. Some sensors of this device utilize electrodes carrying current connected directly to the skin of an individual. Electrical surges through the electrodes carry the possibility to GRIEVOUSLY INJURE OR KILL an individual connected to the device. For the safety of all utilizing this device, DO NOT VIOLATE ANY OF THE SAFETY INSTRUCTIONS located within this section of the manual. DO NOT USE THIS DEVICE WITHOUT READING THESE SAFETY INSTRUCTIONS.

### 2.1 ELECTRICAL SAFETY

Do not operate a sensor while the sensor module in use is charging or is connected to the Charging Module. Operating a sensor module while the module is connected to an external power source has the potential to result in bodily injury for the individual connected to the sensor. For the safety of the individual connected to the sensor probe, do not use the sensor module while it is charging or connected to an external power source. If a sensor module needs to be charged, completely disconnect it from an individual before returning the sensor to the Charging Module or connecting it to any other external power supply.

Do not leave the system unattended while it is operating. The system contains lithium-ion batteries which carry the unlikely possibility of catastrophically failing and starting a fire. As such, always ensure that someone is there while the system is operating, and that the system is properly shut down with all batteries disconnected when no longer operating.

### 2.2 BIOLOGICAL SAFETY

In order to prevent contracting illnesses from the sensor modules, it is recommended that the temperature sensor probe, the pulse oximeter probe, and the stethoscope probe be sanitized after each use. To sanitize these sensors, disconnect the sensor from its port, take an alcohol wipe, and gently wipe the piece of the probe that contacts skin with the alcohol wipe. Allow up to five minutes for the alcohol to evaporate before reconnecting and using the sensor again. Do not sanitize with bleach-based cleaners.

To use the temperature probe without needing to sanitize the sensor after each use, put a catheter thermometer probe cover onto the temperature sensor probe. Remove the cover after each use. Do not reuse the disposable probe covers.

Do not reuse the disposable electrodes for the skin impedance and ECG sensor modules.

### 2.3 CHEMICAL SAFETY

Do not leave the electrodes attached to skin for extended periods of time. In order to avoid skin irritation, it is recommended that skin is not in contact with the electrode pads for more than three hours. After such time, it is recommended that the electrode pads be removed and disposed of. If use of the sensor is required after this three hour period, new electrode pads can be applied to a different patch of skin.

Do not use any of the probes while alcohol from disinfection is still on the probe’s surface. Always allow the probes to completely dry before using the probe again.

If skin irritation occurs while using any of the probes, cease probe use immediately.

While soldering any component of this project, always do so in a well ventilated room with a fume hood to prevent the inhalation of toxic fumes. Always wear gloves and safety goggles while soldering to prevent material from coming into contact with exposed skin or eyes. Always wash hands thoroughly after soldering.

### 2.4 WATER SAFETY

Do not operate this system around water or expose this system to water. This device is not rated for water exposure, and exposure to water carries the risk of damage to the device and the user if the system is operated. If the system is inadvertently exposed to water, immediately unplug the central housing from the power supply. Put on insulating gloves and footwear, then disconnect the batteries from the sensors in each housing. Before operating again, allow the system to fully dry, and inspect the system to ensure that all water has dried.

### 2.5 SUBSTANCE SAFETY

Do not operate this system while under the influence on substances that alter coordination or decision making, such as alcohol. Using such substances can cause individuals to ignore other safety considerations, and doing so can result in injury or damage to the device.

### 2.6 CHILD SAFETY

Do not allow children under the age of eighteen to use this system without adult supervision.

### 2.7 THERMAL SAFETY

This device contains electrical components that have the ability to get warm during use. When the device is in use, do not attempt to touch the microcontroller or any other electrical component other than the external sensor probe of each sensor module.

Always ensure that a fire extinguisher is nearby when building and operating this device. If smoke is seen rising from any sensor module or housing, disconnect the system from the external power source. If able, move the smoking housing to a safe location away from the rest of the system or anything flammable before attempting to open the system and disconnect the battery.

### 2.8 EXPLOSION SAFETY

Do not use this device while the housing is not on. This device contains components that have the capability to explode in rare circumstances, namely the capacitors and the batteries. To decrease the risk of being struck by shrapnel in the unlikely event of explosive failure of these components, always operate this device with the proper housing pieces.

### 2.9 IRRESPONSIBILITY SAFETY

In summary, please exercise caution and common sense when operating this device. If the device is operated in an unsafe manner, there is the potential for dangerous results. Please follow the aforementioned safety guidelines when operating this device.

### 3.0 ASSEMBLY INSTRUCTIONS

Detailed below are the instructions required to construct the entire system. The first section discussed the printing of all of the housing components. The second section discussed the instructions required to print the PCBs and assemble the PCBS. The third section discusses the assembly of the OLEDs for each sensor module. The fourth section discusses the final assembly of the central Charging Module. The fifth section discusses the final assembly for each of the Sensor Modules. The sixth section discusses the final assembly for the Receiver Module.

### 3.1 HOUSING INSTRUCTIONS

This section details the procedure for printing the housing for the sensors.

### 3.1.1 PRINTER REQUIREMENTS

For this, there will be a size requirement due to parts needing to remain in one piece and it would be best to have a printer that has the capacity to handle any of the prints. The printer volume space needs to be at least 330 x 150 x 120 mm with a 0.4mm nozzle extruder. A Prusa XL is recommended.

When printing, set the print setting to “0.10mm FAST DETAIL” for the smaller pieces. This will give them thinner layers and keep them stronger between layers. For the charging station, set the print setting to “0.25mm STRUCTURAL”. As the piece is much larger, this will allow it to print quicker. With this being a storage piece and larger, it does not need to be as tight between the layers.

Even with this amount of space for the smaller pieces, it is recommended to print each piece one at a time as this will allow the print of that piece to be of better quality.

### 3.2 PCB INSTRUCTIONS

This section details the procedure to create and assemble the PCBs required to operate the sensors.

### 3.2.1 ORDERING PCBS

The PCB schematic and board files for each sensor are uploaded in the Github repository. The boards that were used for this project were ordered from PCBway. However, any PCB manufacturer is able to replicate these boards. For PCB manufacturers other than PCBway, please refer to their website when ordering.

However, when ordering from PCBway, please refer to this link: https://www.pcbway.com/blog/help_center/How_to_Generate_BOM_and_Centroid_File_in_Eagle_f0fa4189.html, (https://www.pcbway.com/blog/help_center/How_to_Generate_BOM_and_Centroid_File_in_Eagle_f0fa4189.html) which explains how to extract the Bill of Materials (BOM) and Centroid files. Once these files are extracted, go to the PCBway website and follow the ordering procedures. Simply upload the Gerber files, which can be extracted from EagleCAD, into the PCBway ordering form. The website will then automatically match the specifications of the PCB. Once the board ordering is finalized, proceed to the assembly. Within the assembly, keep all the default options that PCBway has. However, you may change the silkscreen color of the PCBs. For this project, a white silkscreen was chosen.

Once the PCBs are within the ordering page of the PCBway website, this will require for the BOM and centroid files to be uploaded before the user may proceed. Upload the BOM and centroid files, and wait for PCBway to confirm the cost. The user will receive an email and simply check and modify the cost.

### 3.2.2 CONSTRUCTING PCBS

Below are the walkthroughs for how to construct each of the PCBs should they be ordered empty. In the event that the PCBs are ordered with all of the components already on them, please disregard these instructions.

### 3.2.2.1 TEMPERATURE PCB

This section outlines the procedures to solder and assemble the Temperature PCB.

TOOLS REQUIRED:

1. One Soldering Iron
2. One Hot Air Gun or Soldering Hot Plate
3. One Set of Tweezers
4. One Soldering Microscope
5. Two Needles or Another Solder Paste Application Tool
6. One Set of Wire Strippers

COMPONENTS:

1. Solder Wire
2. Solder Paste
3. One Empty 100320 Temperature PCB
4. Three 10 kΩ PCB Resistors (0603 size)
5. One 1 kΩ PCB Resistor (0603 size)
6. One Red PCB LED (0603 size)
7. One 0.1 µF Capacitor (0603 size)
8. One 10 µF Capacitor (0603 size)
9. One SJ-3523-SMT-TR 3.5 mm AUX Port
10. One Two-Lead 3.5 mm AUX Jack
11. One Amphenol MA100GG103AN Catheter 10 kΩ Thermistor
12. 2 mm Diameter White Heat Shrink Tubes

PROCEDURE:

1. Perform Steps 1-11 using the Solder Microscope.
2. Using the Two Needles or Another Solder Paste Application Tool, place a small amount of Solder Paste on the pair of solder pads for the “R1,” “R2,” and “R3” components on the 100320 Temperature PCB.
3. Using the Tweezers, place the three 10 kΩ PCB Resistors on the “R1,” “R2,” and “R3” solder pads in contact with the Solder Paste. Ensure that the labels of the 10 kΩ PCB Resistors are face up.
4. Using the Hot Air Gun or Soldering Hot Plate, heat the Solder Paste until it fully melts. Then remove the heat and allow the solder to cool and fuse the three 10 kΩ PCB Resistors to their solder pads. If using the Hot Air Gun, be careful to not blow the resistors off of their pads, using the Tweezers to help hold the resistors in place.
5. Please Proceed to UM 4.1 to generate the resistance values needed for calibration. This is the best place for this calibration to occur, though it can be done later with extra work. When complete, continue with this assembly procedure.
6. Using the Two Needles or Another Solder Paste Application Tool, place a small amount of Solder Paste on the pair of solder pads for the “C1,” “C2,” “R16,” and “D1” components on the 100320 Temperature PCB.
7. Using the Tweezers, place the 10 µF Capacitor on the “C1” solder pads in contact with the Solder Paste. Ensure that the label of the 10 µF Capacitor is face up.
8. Using the Tweezers, place the 0.1 µF Capacitor on the “C2” solder pads in contact with the Solder Paste. Ensure that the label of the 0.1 µF Capacitor is face up.
9. Using the Tweezers, place the 1 kΩ PCB Resistor on the “R16” solder pads in contact with the Solder Paste. Ensure that the label of the 1 kΩ PCB Resistor is face up.
10. Using the Tweezers, place the Red PCB LED on the “D1” solder pads in contact with the Solder Paste. Ensure that the green stripe of the Red LED is facing up and towards the “LED DISABLE”.
11. Using the Hot Air Gun or Soldering Hot Plate, heat the Solder Paste until it fully melts. Then remove the heat and allow the solder to cool and fuse the components to their solder pads. If using the Hot Air Gun, be careful to not blow the components off of their pads, using the Tweezers to help hold the components in place.
12. Using the Soldering Iron, solder the SJ-3523-SMT-TR 3.5 mm AUX Port onto the 100320 Temperature PCB.
13. Using the Soldering Iron, place Solder onto the solder jumpers “JP1,” “JP2,” “JP3,” and “JP4” to connect the two pads of the jumpers.
14. Using the Wire Strippers, cut the Thermistor wire so that the wires connected to the Thermistor are at least 15 cm long. Then, remove roughly 5 mm of insulation from both of the wires of the Thermistor.
15. Using the Wire Strippers, cut the Two-Lead 3.5 mm AUX Jack wire so that the wires connected to the Jack are at least 15 cm long. Then, remove roughly 0.5 cm of insulation from both of the wires of the Jack.
16. Slip two pieces of the White Heat Shrink Tubes over the two wires of the Thermistor. Be sure to use enough of the Heat Shrink Tubes to cover the wires and solder completely.
17. Using the Soldering Iron, solder the two wires of the Thermistor to the two wires of the Two-Lead 3.5 mm AUX Jack.
18. Slide the Heat Shrink Tubes over the exposed wires and solder.
19. Use the Hot Air Gun to shrink the Heat Shrink Tubes until they are tight around the wires and solder.
20. Using the Hot Air Gun, hit the Heat Shrink Tubes with hot air until the tubes shrink tightly around the soldered wires.
21. Plug the 3.5 mm AUX Jack into the 3.5 mm AUX Port

### 3.2.2.2 SKIN IMPEDANCE PCB

This section outlines the procedures to solder and assemble the Impedance PCB.

PROCEDURE:

1. Please refer to the PCB ordering section. Due to the complex nature of this PCB, it is not recommended to micro-solder the components on your own. However, if one does want to microsolder this PCB, the schematic and board files are within the Github page. Download the BOM files from these documents, and follow the orientation using the board.

### 3.2.2.3 ECG PCB

This section outlines the procedures to solder and assemble the ECG PCB.

TOOLS REQUIRED:

1. One Soldering iron
2. One Hot air gun
3. One Set of Tweezers
4. Two Needles or Another Solder Paste Application Tool
5. One Soldering Microscope

COMPONENTS:

1. Solder Wire
2. Solder Paste
3. One Red LED SMD (0603 size)
4. One 1kΩ resistor SMD (0603 size)
5. One SparkFun Pre-Amplifier ECG board (AD8232 chip)
6. Four M3 x 6 mm Stainless Steel Hex Socket Head Cap Screws
7. Four M3 Nuts
8. Four M3 Plastic Washers

PROCEDURE:

1. Within the PCB, place solder paste on the R16 and D1 pads, you may use the tweezers, needle/pin, and microscope.
2. Using the tweezers, carefully place the 1k ohm resistor on the R16 pads.
3. Using the tweezers, carefully place the Red LED on the D1 pads, with the green label facing the 1k resistor.

4. Carefully, use the hot air gun on its lowest speed and aim it at the SMD components. Using the microscope, observe as the solder paste melts. Use the tweezers to move the components in case it moves from the hot air.
5. Once the SMDs are in place and the solder paste has melted, aim the hot air gun away and turn it off.
6. Solder the header pins that came along with the SparkFun board to the board, ensuring the long side of the pins face downwards.
7. Thread the M3 Screws through the four holes of the SparkFun board.
8. Thread the four M3 Plastic Washers onto the four M3 Screws.
9. Orient the SparkFun board on the PCB. Follow the labels of the PCB and match it with the SparkFun board, ensuring the headers on the SparkFun board go through the pin holes on the PCB and the screws go through the screw holes on the PCB.
10. Screw the M3 Nuts onto the screws, securing the SparkFun board to the PCB.
11. Solder the header pins of the SparkFun board on the PCB through the backside.

### 3.2.2.4 PULSE OXIMETER PCB

This section outlines the procedures to solder and assemble the Pulse Oximeter PCB.

PROCEDURE:

1. Please refer to the PCB ordering section. Due to the complex nature of the pulse ox PCB and the amount of components it has. it is not recommended to micro-solder the components on your own. However, if one does want to microsolder this PCB, the schematic and board files are within the Github page. Download the BOM files from these documents, and follow the orientation using the board.

### 3.2.2.5 DIGITAL STETHOSCOPE PCB

This section outlines the procedures to solder and assemble the Digital Stethoscope PCB.

TOOLS REQUIRED:

1. One Soldering Iron
2. One Hot Air Gun or Soldering Hot Plate
3. One Set of Tweezers
4. One Soldering Microscope
5. Two Needles or Another Solder Paste Application Tool

COMPONENTS:

1. Solder Wire
2. Solder Paste
3. One Empty 100420 Sound Sensor PCB
4. Red LED SMD (0603 size)
5. One 1k ohm resistor SMD (0603 size)
6. One 2k ohm resistor SMD (0603 size)
7. Two 7.5k ohm resistors SMD (0603 size)
8. One 20k ohm resistor SMD (0603 size)
9. One 0.1 µF Capacitor SMD (0603 size)
10. One 10 µF Capacitor SMD (0603 size)
11. Two 22 µF Capacitors SMD (0603 size)
12. One TL071ACD (SMD Operational Amplifier)
13. One PCBArtists ES8388 Audio CODEC
14. One Adafruit MAX9814 Microphone
15. Two M3 x 6 mm Stainless Steel Hex Socket Head Cap Screws
16. Two M3 Nuts
17. Two M3 Plastic Washers

PROCEDURE:

1. Within the PCB, place solder paste on the U2 pad, you may use the tweezers, needle/pin, and microscope. Using the tweezers, carefully place the TL071ACD on the U2 pad.

2. Within the PCB, place solder paste on the R6 and R7 pads, you may use the tweezers, needle/pin, and microscope. Using the tweezers, carefully place the two 7.5 k ohm resistors on each pad.
3. Within the PCB, place solder paste on the C1 and C8 pads, you may use the tweezers, needle/pin, and microscope. Using the tweezers, carefully place the two 22 µF capacitors on each pad.
4. Within the PCB, place solder paste on the R9 pad, you may use the tweezers, needle/pin, and microscope. Using the tweezers, carefully place the 20k ohm resistor on the R9 pad.
5. Within the PCB, place solder paste on the R10 pad, you may use the tweezers, needle/pin, and microscope. Using the tweezers, carefully place the 2k ohm resistor on the R10 pad.
6. Within the PCB, place solder paste on the C6 pad, you may use the tweezers, needle/pin, and microscope. Using the tweezers, carefully place the 0.1 µF capacitor on the C6 pad.
7. Within the PCB, place solder paste on the C7 pad, you may use the tweezers, needle/pin, and microscope. Using the tweezers, carefully place the 10 µF capacitor on the C7 pad.
8. Within the PCB, place solder paste on the R16 pad, you may use the tweezers, needle/pin, and microscope. Using the tweezers, carefully place the 1k ohm resistor on the R16 pad.
9. Within the PCB, place solder paste on the D2 pad, you may use the tweezers, needle/pin, and microscope. Using the tweezers, carefully place the Red LED on the D2 pad.
10. Carefully, use the hot air gun on its lowest speed and aim it at the SMD components. Using the microscope, observe as the solder paste melts. Use the tweezers to move the components in case it moves from the hot air.
11. Once the SMDs are in place and the solder paste has melted, aim the hot air gun away and turn it off.
12. Solder the header pins that came along with the Adafruit MAX9814 board.

13. Thread the M3 Screws through the two holes of the Adafruit MAX9814 board.
14. Thread the two M3 Plastic Washers onto the two M3 Screws.
15. Next, orient the Adafruit MAX9814 board on the PCB. Follow the labels of the PCB and match it with the Adafruit MAX9814 board.
16. Screw the M3 Nuts onto the screws, securing the Adafruit MAX9814 board to the PCB.
17. Solder the header pins of the PCBArtists ES8388 board on the PCB through the backside.
18. Solder the header pins that came along with the PCBArtists ES8388 board.
19. Next, orient the PCBArtists ES8388 board on the PCB. Follow the labels of the PCB and match it with the Adafruit MAX9814 board.
20. Solder the header pins of the PCBArtists ES8388 board on the PCB through the backside.

### 3.3 OLED INSTRUCTIONS

Below are the procedures needed to prepare the five OLEDs for assembly into the system. The OLED fits tightly into the slot within the Sensor Housing, so when soldering, ensure that the wires are straight out of their holes and that minimal solder is used. Hot glue is applied after soldering to secure the wires in place.

TOOLS REQUIRED:

1. One Soldering Iron
2. One Fine-Grain File
3. One Set of Wire Strippers
4. Hot Glue Gun

COMPONENTS:

1. Solder Wire
2. Hot Glue
3. Hot Glue
4. One 100210 Module Bottom

5. One 100220 Module Top
6. Five Frienda 0.91 Inch 128 x 32 pixels I2C DC 3.3V~5V OLED Display Module
7. Five Stemma QT / Qwiic JST SH 1 mm 4-pin to Male Connectors

PROCEDURE:

1. Using the Wire Strippers, cut the Stemma QT Connector roughly 5 cm above the JST-SH 4-pin Female Connector.
2. Using the Wire Strippers, remove roughly 2 mm of insulation off of the wires connected to the JST-SH 4-pin Female Connector.
3. Using the Soldering Iron, solder the Black Wire of the JST-SH 4-pin Female Connector to the GND hole of the OLED.
4. Using the Soldering Iron, solder the Red Wire of the JST-SH 4-pin Female Connector to the VCC hole of the OLED.
5. Using the Soldering Iron, solder the Yellow Wire of the JST-SH 4-pin Female Connector to the SCL hole of the OLED.
6. Using the Soldering Iron, solder the Blue Wire of the JST-SH 4-pin Female Connector to the SDA hole of the OLED.
7. Using the Hot Glue Gun, glue the wires soldered to the OLED where the wires are soldered and where the bare wire is exposed to ensure the wires cannot bend and break.
8. Attempt to fit the soldered OLED into the Sensor Module, parts 100210 and 100220.
9. If the OLED does not fit, use the file to remove solder from connections.
10. Repeat Step 7 and Step 8 until the OLED fits within the housings.
11. Repeat Steps 1-10 for the four other OLEDs.

### 3.4 FINAL CHARGING MODULE ASSEMBLY

This section details the procedure required to construct the charging station. The construction of the station includes adding pieces that are not required for the station to operate but do allow transportation to proceed with greater ease.

TOOLS REQUIRED:

1. Scissors

2. Hot Glue Gun

COMPONENTS:

1. Hot Glue
2. Sticky Velcro Pads
3. One Surge Protector with at least Five USB-A
4. Five Magnetic Charging Cables
5. One 100250 Charging Station Main Body
6. One 100260 Charging Station Base

PROCEDURE:

1. Taking the opposite sides of the velcro, peel off the plastic coating the sticky side of the hooks and stick to the bottom of the surge protector. If the pad is too large, cut to size after sticking.
2. Take the hoops side and cut to size to fit within the Charging Module; this can be approximated. Remove the plastic covering on the sticky side and attach to the Charging Station Base plate.
3. Attach the surge protector to the Charging Station Base plate.
4. Insert the magnetic charging cables into the surge protector.
5. Put the cables through the holes in the top of the Charging Station Main Body and secure them so as not to have them fall through.
6. With the Hot Glue Gun, put a small glob in the holes where the cables are in, try not to put them on the cables directly.
7. Pull the cables slowly into the holes and secure them so the magnetic face is flush with the radius of the hole.
8. After the glue stiffens, push the Charging Station Main Body onto the Charging Station Base plate until a click is heard.

### 3.5 FINAL SENSOR MODULE ASSEMBLY

This section details the procedure required to construct the five Sensor Modules. As for the most part, the components within the system are interchangeable, these instructions will be generalized for the modules as a whole; charts will be included to describe sensor-specific instructions, where required.

TOOLS REQUIRED:

1. One Soldering Iron

2. One Set of Wire Strippers
3. Hot Glue Gun
4. One 2.5 mm Allen Wrench
5. One 1.5 mm Allen Wrench
6. One Laptop with the Arduino IDE, required Codes, and a USB-A Port
7. One USB-A to USB-C Cable

COMPONENTS:

1. Solder Wire
2. Hot Glue
3. Five 100210 Module Bottoms
4. Five 100220 Module Tops
5. One Assembled 100320 Temperature PCB
6. One Assembled 100420 Sound Sensor PCB
7. One Assembled 100520 Pulse Oximeter PCB
8. One Assembled 100620 Skin Impedance PCB
9. One Assembled 100720 ECG PCB
10. 100330 Temperature Arduino Code
11. 100430 Sound Sensor Arduino Code
12. 100530 Pulse Oximeter Arduino Code
13. 100630 Skin Impedance Arduino Code
14. 100730 ECG Arduino Code
15. One 100340 Temp Insert
16. One 100460 Sound Insert
17. One 100540 Pulse Ox Insert
18. One 100650 Impedance Insert
19. One 100750 ECG Insert
20. Five Adafruit 5323 ESP32-S3 Feathers

21. Five Assembled I2C OLEDs
22. Five B07V9P5LGB Magnetic Charging Tips
23. Five 1009 Tactile Buttons
24. Five Adafruit 258 3.3 V 1200 mAh Batteries
a. Note: If using batteries that are not Adafruit Brand and microcontrollers that are not Adafruit Brand, please check the polarity of both the battery and the battery plug on the microcontroller. Adafruit batteries and microcontrollers reverse the polarities of the terminals to connect the battery to the microcontroller. If a battery does not have the same polarity as the microcontroller being used, it has the potential to destroy the battery, the microcontroller, or both.
25. Twenty M3 x 6 x 5 mm Female Thread Brass Knurled Threaded Insert Embedment Nuts
26. Twenty M3 x 6 mm Stainless Steel Hex Socket Head Cap Screws
27. Twenty M3 Nuts
28. Ten M2 x 4 x 3.5 mm Female Thread Brass Knurled Threaded Insert Embedment Nuts
29. Ten M2 x 16 mm Steel Flat Head Hex Socket Cap Screws
30. Ten M2 Plastic Washers
31. Twenty M2 Nuts
32. Five 10 kΩ Breadboard Resistors
33. Assorted 20 AWG Wires of Colors in Figures 3.5.2-3.5.6

PROCEDURE:

1. Using the Soldering Iron, gently melt the sides of the empty screw holes for the PCB of the 100220 Module Top.
2. Insert the M3 x 6 x 5 mm Brass Nut into the hole, then push the Brass Nut into the hole until it is flush using the hot Soldering Iron. Be careful to not burn through the other side of the housing with the Soldering Iron.
3. Repeat Step 1 and Step 2 for the other three holes of the 100220 Module Top.
4. Repeat Steps 1-3 for the two empty screw holes for the ESP32 of the 100210 Module Bottom with the M2 x 4 x 3.5 mm Brass Nuts.

5. For the Sensor Module being built in Figure 3.5.1, use the Laptop and the USB-A to USB-C Cable to load the correct code onto an ESP32-S3. To do this, connect the ESP32-S3 to the Laptop with the Cable, and using the Arduino IDE, load the code being used for the Sensor Module being built. To prepare the ESP32-S3 for the code, press and hold the “Boot Button” on the ESP32-S3, then press the “Reset Button,” then release the “Boot Button.” On the top of the IDE, select the “Adafruit Feather ESP32-S3 No PSRAM” microcontroller from the menu and select the correct COM port the ESP32-S3 is connected to. Press the “Upload Button” on the top of the IDE, and wait for the Output to display that the upload is complete.
6. Disconnect the USB-A to USB-C Cable from the ESP32-S3, then plug the B07V9P5LGB Magnetic Charging Tip into the ESP32-S3.
7. For the Sensor Module being built in Figure 3.5.1, use the relevant wiring guide in Figures 3.5.2-3.5.6 and the Soldering Iron to solder the Tactile Button and the PCB to the ESP32-S3. Be careful to not burn any of the components on the ESP32-S3 or the PCB. Ensure that the wires used are at least 10 cm long to ensure the wires are long enough to allow for the Sensor Module to be opened without tearing out the wires.
a. If two components have wires that need to connect to the same hole on the ESP32-S3, such as how both the Temperature PCB and the Tactile Button require a connection to the 3V hole on the ESP32-S3, it is suggested that you solder the wires that connect to the PCB and the Tactile button first. Afterwards, take the leads from both components, twist the uninsulated ends that are meant to connect to the ESP32-S3 together, then solder the braided wire to ESP32-S3. This way, both wires are soldered at once, and they will hopefully have a stronger connection to the ESP32-S3.
b. When connecting the Black Lead of the Tactile Button to GND, solder a 10 kΩ Breadboard Resistor to the pin of the Tactile Button, then solder the Black Lead to the other end of the resistor. Then solder the other end of the wire connected to the resistor to the GND hole of the ESP32-S3. This resistor is involved in logic, and is required for proper button function.
8. Using the Hot Glue Gun, glue the wires soldered to the ESP32-S3, PCB and Tactile Button where the wires are soldered and where the bare wire is exposed to ensure the wires cannot bend and break.
9. For the Sensor Module being built in Figure 3.5.1, thread the M3 x 6 mm Screw through the screw hole on the Assembled PCB, then screw the M3 Nut onto the screw, securing the screw to the PCB. Repeat for the four screw holes on the PCB.

10. Using the 2.5 mm Allen Wrench, screw the PCB onto the 100220 Module Top. Tighten the four screws until the PCB is secure and cannot move. Ensure the probe connection is on the side of the Module Top that has the Probe Slot.
11. Take the M2 x 16 mm Screw and thread an M2 Nut onto the screw. Then thread the screw through one of the screw holes by the USB-C connector on the ESP32-S3. Afterwards, thread an M2 Plastic Washer onto the screw, then thread another M2 Nut onto the screw. Repeat this process for the other screw hole by the USB-C connector on the ESP32-S3.
12. Using the 1.5 mm Allen Wrench, screw the ESP32-S3 onto the 100210 Module Bottom. Tighten the two screws until they are fully in their holes, then tighten the M2 Nuts on top of the ESP32-S3 until the ESP32-S3 is secure and cannot move.
13. Slot the Tactile Button into its space in the 100210 Module Bottom, ensuring that the small nub on the Tactile Button slides into the slot in the Tactile Button space. Ensure that the wires do not disconnect while inserting the Tactile Button.
14. Slide the Assembled I2C OLED into its slot in the 100210 Module Bottom. Ensure that none of the wires do not disconnect while inserting the OLED.
15. Plug the JST-SH 4-pin Female Connector of the Assembled I2C OLED into the JST-SH 4-pin Male Connector on the ESP32-S3.
16. Using the Hot Glue Gun, glue the Adafruit 3.3 V 1200 mAh Battery to the battery space on the 100210 Module Bottom. Ensure the wires of the battery go through the small slot in the battery space. Allow the glue to set.
17. Plug the battery into the battery connector on the ESP32-S3.
18. Remove the probe from the PCB.
19. For the Sensor Module being built in Figure 3.5.1, slide the Cover Slip into the Probe Slot. Ensure the hole in the Cover Slip lines up with the probe connection on the PCB, and that the label on the Cover Slip faces out.
20. Plug the probe back into the PCB.
21. To close the Sensor Module, bring the connectors for the 100210 Module Bottom and 100220 Module Top together. Ensure the Tactile Button, I2C OLED, Magnetic Charging Tip, and the Cover Slip slide into their corresponding slots in both housings without breaking any wires or components. Be very careful with the OLED especially. Once done, press the two halves of the housings together until you hear the Sensor Module close, beginning with the OLED side of the Sensor Module.
22. Repeat Steps 1-21 for all other Sensor Modules you wish to construct.

PARTS CHARTS:

FIGURE 3.5.1: SENSOR-SPECIFIC PARTS

Sensor Module | Assembled PCB | Code | Cover Slip
Temperature | 100320 | 100330 | 100340
Sound Sensor | 100420 | 100430 | 100460
Pulse Oximeter | 100520 | 100530 | 100540
Skin Impedance | 100620 | 100630 | 100650
ECG | 100720 | 100730 | 100750

FIGURE 3.5.2: TEMPERATURE SENSOR WIRING LIST

ESP Hole | PCB Hole | Tactile Button | Wire Color
3V | 3V | 1 | Red
GND | GND | 4 | Black with 10 kΩ Pull-down Resistor for the Tactile Button
A0 | A0 | | Green
A1 | A1 | | Blue
10 | | 4 | Yellow

FIGURE 3.5.3: SOUND SENSOR WIRING LIST

ESP Hole | PCB Hole | Tactile Button | Wire Color
3V | 3V | 1 | Red
GND | GND | 4 | Black with 10 kΩ Pull-down Resistor

| | | for the Tactile Button
DGND | 3V (1st pin) | | Black
DVDD | GND | | Red
AGND | 3V (2nd pin) | | Black
AVDD | GND | | Red
SDA | SDA | | Green
SCL | SCL | | Green
MCLK | A4 | | Yellow
SCLK | SCK | | Yellow
LRCLK | A5 | | White
DIN | MO | | Blue
DOUT | MI | | Blue
10 | | 4 | Yellow

FIGURE 3.5.4: PULSE OXIMETER SENSOR WIRING LIST

ESP Hole | PCB Hole | Tactile Button | Wire Color
3V | VCC | 1 | Red
GND | GND | 4 | Black with 10 kΩ Pull-down Resistor for the Tactile Button
A4 | START | | WHITE
13 | RDY | | WHITE
6 | CS0 | | YELLOW
MI | MOSI | | YELLOW
MO | MISO | | YELLOW

SCK | SCK | | YELLOW
NC | PD ALM
NC | LED ALM
NC | DIAG END
5 | PWDN | | WHITE
10 | | 4 | RED

FIGURE 3.5.5: SKIN IMPEDANCE SENSOR WIRING LIST

ESP Hole | PCB Hole | Tactile Button | Wire Color
SDA | SDA | | Blue
SCL | SCL | | Yellow
GND | GND | 4 | Black with 10 kΩ Pull-down Resistor for the Tactile Button
3V | 3v3 | 1 | Red
9 | | 4 | Red
12 | CAL_INT | | White

FIGURE 3.5.6: ECG SENSOR WIRING LIST

ESP Hole | PCB Hole | Tactile Button | Wire Color
3V | 3.3V | 1 | Red
GND | GND | 4 | Black with 10 kΩ Pull-down Resistor for the Tactile Button
11 | LO- | | Blue
10 | LO+ | | White
9 | | 4 | Yellow

A1 | OUTPUT | Green
| 3.6 FINAL RECEIVER MODULE ASSEMBLY

This section details the procedure required to construct the Receiver Module. Only one Receiver Module is needed for each complete system.

| TOOLS REQUIRED:
1. One Soldering Iron
2. One 1.5 mm Allen Wrench
3. One Laptop with the Arduino IDE, required Codes, and a USB-A Port
| COMPONENTS:
1. One 100230 Receiver Bottom
2. One 100240 Receiver Top
3. 100130 Receiver Code
4. One Adafruit 5323 ESP32-S3 Feather
5. Two M2 x 4 x 3.5 mm Female Thread Brass Knurled Threaded Insert
| Embedment Nuts
6. Two M2 x 16 mm Steel Flat Head Hex Socket Cap Screws
7. Two M2 Plastic Washers
8. Four M2 Nuts
9. One USB-A to USB-C Cable
| PROCEDURE:
1. Using the Soldering Iron, gently melt the sides of the empty screw holes
| for the ESP32-S3 of the 100230 Receiver Bottom.
2. Insert the M2 x 4 x 3.5 mm Brass Nut into the hole, then push the Brass Nut into the hole until it is flush using the hot Soldering Iron. Be careful to not burn through the other side of the housing with the Soldering Iron.
3. Repeat Step 1 and Step 2 for the other hole of the 100230 Module Bottom.
4. Use the Laptop and the USB-A to USB-C Cable to load the Receiver Code onto an ESP32-S3. To do this, connect the ESP32-S3 to the Laptop with the Cable, and using the Arduino IDE, load the Receiver Code. To prepare the ESP32-S3 for the code, press and hold the “Boot Button” on the

ESP32-S3, then press the “Reset Button,” then release the “Boot Button.” On the top of the IDE, select the “Adafruit Feather ESP32-S3 No
PSRAM” microcontroller from the menu and select the correct COM port the ESP32-S3 is connected to. Press the “Upload Button” on the top of the IDE, and wait for the Output to display that the upload is complete.
5. Disconnect the USB-A to USB-C Cable from the ESP32-S3 and the Laptop.
6. Take the M2 x 16 mm Screw and thread an M2 Nut onto the screw. Then thread the screw through one of the screw holes by the USB-C connector on the ESP32-S3. Afterwards, thread an M2 Plastic Washer onto the screw, then thread another M2 Nut onto the screw. Repeat this process for the other screw hole by the USB-C connector on the ESP32-S3.
7. Using the 1.5 mm Allen Wrench, screw the ESP32-S3 onto the 100230 Receiver Bottom. Tighten the two screws until they are fully in their holes, then tighten the M2 Nuts on top of the ESP32-S3 until the ESP32-S3 is secure and cannot move.
8. To close the Receiver Module, bring the connectors for the 100230 Receiver Bottom and 100240 Receiver Top together. Once done, press the two halves of the housings together until you hear the Receiver Module close.
9. Plug the Cable back into the ESP32-S3 within the Receiver Module.

### 4.0 CALIBRATION INSTRUCTIONS

This section contains the calibration procedures for the Temperature Module and the Skin Impedance Module.

### 4.1 TEMPERATURE MODULE CALIBRATION

In order for the Temperature Module to be accurate, a simple calibration procedure must be completed. It is recommended that this procedure be completed after Step 4 of Procedure
3.2.2.1. It is recommended to keep the resistor values gained through this calibration with the Temperature Module at all times. Consider keeping the resistor values on a sticky note on the Temperature Module, or at least with the system as a whole, especially if more than one system is present at a location.

TOOLS REQUIRED:

1. One Digital Multimeter capable of measuring up to 10 kΩ of resistance and detecting continuity
2. One Precision Knife or other sharp, small cutting implement
3. One Soldering Iron with thinly beveled tip adequate for use on a PCB

4. One 2.5 mm Allen Wrench

COMPONENTS:

1. Solder Wire

PROCEDURE:

1. Unplug the temperature probe from the 3.5 mm port, if plugged in.
2. Using the 2.5 mm Allen Wrench, remove the temperature PCB from the housing, if it is in the housing.
3. Using the Soldering Iron, desolder the solder jumpers, labeled “JP1,” “JP2,” “JP3,” and “JP4,” if soldered.
4. Using the Precision Knife, slice the thin strip of metal connecting the two pads within the box labeled “LED DISABLE.” If the “LED DISABLE” is soldered instead, desolder it using the Soldering Iron.
5. To measure the resistance of “R1,” connect the two leads of the Digital Multimeter to “TP1” and “TP4.”
6. Ensure the resistance value is close to 10 kΩ. If it is, record the given resistance value. If it is not, ensure all solder jumpers are completely desoldered and the “LED DISABLE” is completely cut and desoldered, and remeasure.
7. To measure the resistance of “R2,” connect the two leads of the Digital Multimeter to “TP1” and “TP2.”
8. Repeat Step 5.
9. To measure the resistance of “R3,” connect the two leads of the Digital Multimeter to “TP2” and “TP3.”
10. Repeat Step 5.
11. Using the Soldering Iron, place a small amount of Solder onto the solder jumpers to connect the two pads of each jumper.
12. Using the Soldering Iron, place a small amount of Solder onto the “LED DISABLE” pads to connect the two pads of the “LED DISABLE.”
13. Using the Digital Multimeter, place the two leads on both of the pads of the “JP1,” “JP2,” “JP3,” “JP4,” and the “LED DISABLE” solder jumpers and measure the continuity of the jumpers. If any of the jumpers are not continuous, repeat Step 11, Step 12, and Step 13.

### 4.2 SKIN IMPEDANCE MODULE CALIBRATION

This section is concerned with the Calibration Procedure of the Skin Impedance Module.

PROCEDURE:

1. Refer to Step 3 of UM 5.6.

### 4.3 SOUND SENSOR MODULE CALIBRATION

This section is concerned with the Calibration Procedure of the Digital Stethoscope Module.

COMPONENTS:

1. Solder Wire
2. Solder Iron

PROCEDURE:

1. With the PCB properly soldered to the ESP32, open the code for the Sound Sensor (100430).
2. Uncomment lines 43, 44, 92, 93, and 110. Comment line 111.
3. Upload the code to the ESP32 and open the serial plot feature of Arduino IDE.
4. Verify the signal amplitude. The normal amplitude for the signal values go from -32768 to 32767. However, due to both the analog and digital filters, the maximum amplitude (and therefore the relative amplitude of the other samples) may decrease.
5. The PCB includes the SET_GAIN port. If none of the pins are connected to each other, the MAX9814 preamplifier will have a gain of 60 dB. If pins Gain and Gnd are connected, the preamplifier will have a gain of 50 dB. If pins Gain and Vdd are connected, the preamplifier will have a gain of 40 dB. Select the configuration of your preference.
6. Solder a wire that connects the pins of your preference.
7. In the Sound Sensor code (100430), comment lines 43, 44, 92, 93, and
110. Uncomment line 111.
8. Upload the altered code to the ESP32.
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

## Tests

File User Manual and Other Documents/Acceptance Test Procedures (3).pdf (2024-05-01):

ATP #24052

### Acceptance Test Procedures

Biomedical Sensor Board for Education

ENGR 498B - #24052

Project Leader: Maria Carmella Ocaya (Biomedical Engineer)

Project Procurement Leader: Muad Alsayar (Electrical Engineer)

Michael Chase Morrett (Biosystems Engineer)

Daniel Fabricio Campana Moscoso (Electrical Engineer)

William Alec Newman (Mechanical Engineer)

Sponsor: Urs Utzinger, PhD

Mentor: Steve Larimore

Revision #11

1/17/2024

REVISION PAGE

REVISION# | REVISION DATE | REVISION DESCRIPTION | REVISED BY
1 | 10/16/23 | Document Created and Format Established | Michael
2 | 10/17/23 | Wrote Temperature and ECG Procedures | Michael
3 | 10/18/23 | Wrote Skin Impedance Procedures | Michael
4 | 10/19/23 | Wrote Sound sensor and Pulse Ox Procedures | Daniel
5 | 10/19/23 | Wrote Pulse Ox Procedures | Daniel
6 | 10/19/23 | Final format edits | Michael
7 | 11/12/23 | Added IP Rating Tests | Michael
8 | 11/14/23 | Added Chemical Resistance and Internal Power Tests, format edits | Michael
9 | 11/26/23 | Small Updates to Various Tests | Michael
10 | 1/16/2024 | Added Inspection Sheets for Weight and Dimensions | Michael
11 | 1/17/2024 | Added All Other Inspection Reports | Michael

TABLE OF CONTENTS | Page No.

### 1.1 Temperature Sensor Module Acceptance Test

1.2 Introduction: This procedure outlines the acceptance tests to be performed on the Temperature Sensor Module (100300) which will be conducted in the lab. These tests will verify that the temperature sensor can output a correct reading for the contact temperature of an object with the correct range and accuracy.
1.3 Referenced Documents: Biomedical Sensor Board for Education System Requirements Document, 10/5/2023, rev #15
1.4 | Required Test Equipment: The list of required test equipment includes:
Description | Model Number | Accuracy
Temperature Assy | 100300 | n/a
Laptop | n/a | n/a
Arduino IDE | Arduino IDE 2.2.1 | n/a
Cup of Water | n/a | n/a
Cole-Parmer Traceable Calibrated Extreme-Accuracy Digital Thermometer | UX-90000-25 | ± 0.01 °C
Microwave | n/a | n/a
1.5 | Table of Tests:
Test Number | Test | Requirement
1.5.1 | Temperature Sensor Module Range | Reading between 21°C and 45°C
1.5.2 | Temperature Sensor Module Accuracy | <0.1°C of error
1.6 | Step-by-step Procedure
1.6.1 Temperature Sensor Module Range
a. Place the cup containing at least 200 mL of water on a table in a room and leave the cup for 12
| hours to allow the cup to come to room temperature
b. Plug temperature sensor module into the laptop using USB-C cable
c. Open Arduino IDE on the laptop
d. Open the Serial Monitor in the Arduino IDE
e. Set the microcontroller to Adafruit Feather ESP32-S3 No PSRAM in the dropdown menu in top
| left of the Arduino IDE
f. Set the com port to an open com port in the same dropdown menu g. Ensure the module is connected by referencing the bottom right corner of the Arduino IDE
h. Using the reference thermometer, test the temperature of the cup of water and record the reading
i. Place the temperature sensor probe into the cup of water
j. Wait 10 seconds for the measurement to stabilize
k. Read the temperature reading on the Arduino IDE Serial Monitor and record the reading
l. Remove the probe from the water
m. Heat the water using a microwave until the temperature has increased by roughly 5°C Celsius, confirming the increase in temperature using the reference thermometer and record the measurement
n. Repeat steps i. through m. until a temperature of 45°C has been measured
o. Compare the temperature values measured with both sensors and ensure that the values measured with the module are within ±3°C of the reference thermometer Mark Pass/Fail on the datasheet
1.6.2 Temperature Sensor Module Accuracy
a. Place the cup containing at least 200 mL of water on a table in a room and leave the cup for 12 hours to allow the cup to come to room temperature
b. Plug temperature sensor module into the laptop using USB-C cable
c. Open Arduino IDE on the laptop
d. Open the Serial Monitor in the Arduino IDE
e. Set the microcontroller to Adafruit Feather ESP32-S3 No PSRAM in the dropdown menu in top left of the Arduino IDE
f. Set the com port to an open com port in the same dropdown menu
g. Ensure the module is connected by referencing the bottom right corner of the Arduino IDE
h. Using the reference thermometer, test the temperature of the cup of water and record the reading
i. Place the temperature sensor probe into the cup of water
j. Wait 10 seconds for the measurement to stabilize
k. Read the temperature reading on the Arduino IDE Serial Monitor and record the reading
l. Remove the probe from the water
m. Heat the water using a microwave until the temperature has increased by roughly 5°C Celsius, confirming the increase in temperature using the reference thermometer and record the measurement
n. Repeat steps i. through m. until a temperature of 45°C has been measured
o. Compare the temperature values measured with both sensors and ensure that the values measured with the module are within ±0.1°C of the reference thermometer Mark Pass/Fail on the datasheet
1.7 | Support Requirements: None
1.8 | Acceptance Test Data Sheets

1.8.1 Temperature Sensor Module Range Acceptance Test Data Sheet

Reference ATP Paragraph Number: 1.6.1

Analysis Referenced (for verification by T/A): None

Name of Test: Temperature Sensor Module Range

Unit Under Test (UUT):
Name: Temperature Assy
Part Number: 100300
Serial Number: n/a
Results (Pass / Fail): | Date of Test:

Recording of Test
Measurement:

Temperature Assy
Measured
Temperatures:

Temperature 1: _____

Temperature 2: _____

Temperature 3: _____

Temperature 4: _____

Temperature 5: _____

Requirement (SR,
with Tolerances):

Measured Reference
Temperatures:

Temperature 1: _____

Temperature 2: _____

Temperature 3: _____

Temperature 4: _____

Temperature 5: _____

Test Equipment
Error:

± 1 °C

Adjusted Test Limit:

± 2 °C

Computations, (Include Analyses Results, if any): None

Signatures:

Tester: _________________

Witness:_______________

1.8.2 Temperature Sensor Module Accuracy Acceptance Test Data Sheet

Reference ATP Paragraph Number: 1.6.2

Analysis Referenced (for verification by T/A): None

Name of Test: Temperature Sensor Module Accuracy

Unit Under Test (UUT):
Name: Temperature Assy
Part Number: 100300
Serial Number: n/a
Results (Pass / Fail): | Date of Test:

Recording of Test
Measurement:

Temperature Assy
Measured
Temperatures:

Temperature 1: _____

Temperature 2: _____

Temperature 3: _____

Temperature 4: _____

Temperature 5: _____

Requirement (SR,
with Tolerances):

Measured Reference
Temperatures:

Temperature 1: _____

Temperature 2: _____

Temperature 3: _____

Temperature 4: _____

Temperature 5: _____

Test Equipment
Error:

± 0.01 °C

Adjusted Test Limit:

± 0.09 °C

Computations, (Include Analyses Results, if any): None

Signatures:

Tester: _________________

Witness:_______________

### 2.1 Digital Stethoscope Module Acceptance Test

2.2 Introduction: This procedure outlines the acceptance tests to be performed on the Digital Stethoscope Module (100400) which will be conducted in the lab. These tests will verify that the sound sensor can output a correct reading for a heartbeat within a range of frequencies of 20 Hz to 200 Hz.
2.3 | Referenced Documents:
| ● Biomedical Sensor Board for Education System Requirements Document, 10/5/2023, rev #15
| ● Alanazi, A. A., Atcherson, S. R., Franklin, C. A., & Bryan, M. F. (2020). Frequency responses of
| conventional and amplified stethoscopes for measuring heart sounds. Saudi Journal of Medicine
| and Medical Sciences, 8(2), 112. https://doi.org/10.4103/sjmms.sjmms_118_19
2.4 | Required Test Equipment: The list of required test equipment includes:
Description | Model Number | Accuracy
Sound sensor Assy | 100400 | n/a
Laptop | n/a | n/a
Arduino IDE | Arduino IDE 2.2.1 | n/a
Stethoscope bell and tube | n/a | n/a
Cell Phone with sound modulator | n/a | n/a
2.5 | Table of Tests:
Test Number | Test | Requirement
2.5.1 | Sound Sensor Module Range | Readings between 20 Hz to 800 Hz
2.5.2 | Digital Stethoscope Module Range | Readings between 20 Hz to 800 Hz with the stethoscope bell and tube
2.6 | Step-by-step Procedure
2.6.1 Sound Sensor Module Range
a. Complete the breadboard prototype for the amplifiers with a DC gain of ~10 V/V and Low Pass
| filter with a cutoff frequency of ~800 Hz.
b. Assemble sound sensor and circuitry to the ESP32-S3.
c. Program a software in Arduino IDE to return the frequency of the sound signal.
d. Use the sound modulator to display different frequencies.
e. Measure the different frequencies (that go from 20 Hz to 800 Hz) with the sound sensor.
f. Verify if the module correctly reads frequencies lower than 800 Hz and filters frequencies higher
| than 800 Hz. Mark Pass/Fail on the datasheet
2.6.2 Digital Stethoscope Module Range a. Complete the breadboard prototype for the amplifiers with a DC gain of ~10 V/V and Low Pass filter with a cutoff frequency of ~800 Hz.
b. Assemble sound sensor and circuitry to the ESP32-S3.
c. Program a software in Arduino IDE to return the frequency of the sound signal.
d. Use the sound modulator to display different frequencies.
e. Plug the sound sensor at the end of the stethoscope tube.
f. Place the Cell phone (sound modulator) on the stethoscope bell.
g. Measure the different frequencies (that go from 20 Hz to 800 Hz) with the digital stethoscope module.
h. Verify if the module correctly reads frequencies lower than 800 Hz and filters frequencies higher than 800 Hz. Mark Pass/Fail on the datasheet
2.7 | Support Requirements: None
2.8 | Acceptance Test Data Sheets

2.8.1 Sound Sensor Module Range Acceptance Test Data Sheet

Reference ATP Paragraph Number: 2.6.1

Analysis Referenced (for verification by T/A):

Name of Test: Sound Sensor Module Range

Unit Under Test (UUT):
Name: Digital Stethoscope Assy
Part Number: 100400
Serial Number: n/a
Results (Pass / Fail): | Date of Test:
Recording of Test Measurement: Digital Stethoscope Assy Measured Frequencies: Freq. 1:__________ Freq. 2:__________ Freq. 3:__________ Freq. 4:__________ Freq. 5:__________ | Requirement (SR, with Tolerances): Frequencies displayed by the sound modulator: Freq. 1:__________ Freq. 2:__________ Freq. 3:__________ Freq. 4:__________ Freq. 5:__________ | Test Equipment Error: n/a | Adjusted Test Limit: ± 10 Hz

Computations, (Include Analyses Results, if any): None

Signatures:

Tester: ________________

Witness:_______________

2.8.2 Digital Stethoscope Module Range Acceptance Test Data Sheets

Reference ATP Paragraph Number: 2.6.2

Analysis Referenced (for verification by T/A): None

Name of Test: Digital Stethoscope Module Range

Unit Under Test (UUT):
Name: Digital Stethoscope Assy
Part Number: 100400
Serial Number: n/a
Results (Pass / Fail): | Date of Test:
Recording of Test Measurement: Digital Stethoscope Assy Measured Frequencies: Freq. 1:__________ Freq. 2:__________ Freq. 3:__________ Freq. 4:__________ Freq. 5:__________ | Requirement (SR, with Tolerances): Frequencies displayed by the sound modulator: Freq. 1:__________ Freq. 2:__________ Freq. 3:__________ Freq. 4:__________ Freq. 5:__________ | Test Equipment Error: n/a | Adjusted Test Limit: ± 10 Hz

Computations, (Include Analyses Results, if any): None

### 3.1 Pulse Oximeter Module Acceptance Test

3.2 Introduction: This procedure outlines the acceptance tests to be performed on the Pulse Oximeter Module (100500) which will be conducted in the lab. These tests will verify that the pulse oximeter can output a correct reading for BPM with a Signal to Noise ratio of at least 5.
3.3 Referenced Documents: Biomedical Sensor Board for Education System Requirements Document, 10/5/2023, rev #15
3.4 | Required Test Equipment: The list of required test equipment includes:
Description | Model Number | Accuracy
Pulse Oximeter Assy | 100500 | n/a
Laptop | n/a | n/a
Arduino IDE | Arduino IDE 2.2.1 | n/a
Prebuilt Pulse Oximeter Fingertip | n/a | n/a
3.5 | Table of Tests:
Test Number | Test | Requirement
3.5.1 | Pulse Oximeter Module Heartbeat Range | Reading between 50 BPM and 180 BPM
3.5.2 | Pulse Oximeter Module Signal to Noise Ratio | SNR >= 5
3.6 | Step-by-step Procedure
3.6.1 Pulse Oximeter Module Heartbeat Range
a. Complete the breadboard prototype for the amplifiers with a DC gain of ~10 V/V.
b. Assemble pulse oximeter sensor and circuitry to the ESP32-S3.
c. Let the subject rest for five minutes (or the time needed for them to be relaxed).
d. Measure the heartbeat of the subject with the prebuilt Pulse Oximeter. Record the measurement.
e. Measure the heartbeat of the subject with the Pulse Oximeter module. Record the measurement.
f. Compare the measurements.
g. Make the subject walk for ten minutes.
h. Measure the heartbeat of the subject with the prebuilt Pulse Oximeter.
i. Measure the heartbeat of the subject with the Pulse Oximeter module.
j. Compare the measurements.
k. Make the subject run for five minutes.
l. Measure the heartbeat of the subject with the prebuilt Pulse Oximeter.
m. Measure the heartbeat of the subject with the Pulse Oximeter module.
n. Compare the measurements.

o. Verify that the measurements of the Pulse Ox module with the prebuilt Pulse Ox are consistent. Mark Pass/Fail on the datasheet
3.6.2 Pulse Oximeter Module Signal to Noise Ratio
a. Complete the breadboard prototype for the amplifiers with a DC gain of ~10 V/V.
b. Assemble pulse oximeter sensor and circuitry to the ESP32-S3.
c. Make the subject walk for ten minutes.
d. Measure the heartbeat of the subject with the Pulse Oximeter module.
e. Record the data.
f. Determine the number of samples in the signal.
g. Calculate the normalized averaged power of the signal.
h. Apply FFT to the signal.
i. Filter out the “ideal” band of the signal and keep everything else. This is the noise.
j. Calculate the normalized averaged power of the noise signal.
k. Verify if the SNR (p_signal/p_noise) is less than five. Mark Pass/Fail on the datasheet
3.7 | Support Requirements: None
3.8 | Acceptance Test Data Sheets

3.8.1 Pulse Oximeter Module Heartbeat Range Acceptance Test Data Sheet

Reference ATP Paragraph Number: 3.6.1

Analysis Referenced (for verification by T/A): None

Name of Test: Pulse Oximeter Module Heartbeat Range

Unit Under Test (UUT):
Name: Pulse Oximeter Assy
Part Number: 100500
Serial Number: n/a
Results (Pass / Fail): | Date of Test:
Recording of Test Measurement: Pulse Oximeter Module measurement of BPM when the subject: Is relaxed:_______ Has walked:______ Has run:_________ | Requirement (SR, with Tolerances): Prebuilt Pulse Oximeter measurement of BPM when the subject: Is relaxed:_______ Has walked:______ Has run:_________ | Test Equipment Error: n/a | Adjusted Test Limit: n/a

Computations, (Include Analyses Results, if any): None

Signatures:

Tester: ________________

Witness:_______________

3.8.2 Pulse Oximeter Module Signal to Noise Ratio Acceptance Test Data Sheets

Reference ATP Paragraph Number: 3.6.2

Analysis Referenced (for verification by T/A): None

Name of Test: Pulse Oximeter Module Signal to Noise Ratio

Unit Under Test (UUT):
Name: Pulse Oximeter Assy
Part Number: 100500
Serial Number: n/a
Results (Pass / Fail): | Date of Test:
Recording of Test Measurement: Measured SNR: _________________ | Requirement (SR, with Tolerances): Minimum SNR: _________________ | Test Equipment Error: n/a | Adjusted Test Limit: n/a

Computations, (Include Analyses Results, if any): None

Signatures:

Tester: ________________

Witness:_______________

### 4.1 Skin Impedance Module Acceptance Test

4.2 Introduction: This procedure outlines the acceptance tests to be performed on the Skin Impedance Module (100600) which will be conducted in the lab. These tests will verify that the skin impedance sensor is able to return a reading for the fat and water content of an object connected to the electrodes with the proper range and accuracy.
4.3 Referenced Documents: Biomedical Sensor Board for Education System Requirements Document, 10/5/2023, rev #15
4.4 | Required Test Equipment: The list of required test equipment includes:
Description | Model Number | Accuracy
Skin Impedance Assy | 100600 | n/a
Laptop | n/a | n/a
Arduino IDE | Arduino IDE 2.2.1 | n/a
4.5 | Table of Tests:
Test Number | Test | Requirement
4.5.1 | Skin Impedance Module Range | Body fat measured between 5% and 40%, water content from 45% to 80%
4.5.2 | Skin Impedance Module Accuracy | Within ±5% of true value
4.6 | Step-by-step Procedure
4.6.1 Skin Impedance Module Range
a. Plug Skin Impedance sensor module into the laptop using USB-C cable
b. Open Arduino IDE on the laptop
c. Open the Serial Plotter in the Arduino IDE
d. Set the microcontroller to Adafruit Feather ESP32-S3 No PSRAM in the dropdown menu in top
| left of the Arduino IDE
e. Set the com port to an open com port in the same dropdown menu
f. Ensure the module is connected by referencing the bottom right corner of the Arduino IDE
g. Plug in 3.5mm jack from the electrodes into the port on the ECG module
h. Connect the electrode to an individual.
i. Record the output body fat and water content
j. Compare the output measurements for the weight, height, and sex at birth to data from another
| body fat measuring device Mark Pass/Fail on the datasheet
4.6.2 Skin Impedance Module Accuracy
k. Repeat steps a. through j. for ATP 4.6.1
l. Compare the output percentages with the expected percentages Mark Pass/Fail on the datasheet

4.7 Support Requirements:
Must find or calculate a reference body fat and water content table prior to tests. 4.8 Acceptance Test Data Sheets

4.8.1 Skin Impedance Module Range Acceptance Test Data Sheet

Reference ATP Paragraph Number: 4.6.1

Analysis Referenced (for verification by T/A): none

Name of Test: Skin Impedance Module Range

Unit Under Test (UUT):
Name: Skin Impedance Assy
Part Number: 100600
Serial Number: n/a
Results (Pass / Fail): | Date of Test:

Recording of Test
Measurement:

Subject 1:

Weight:__________

Height:__________

Sex:_____________

Body Fat Content:__

Water Content:_____

Subject 2:

Weight:__________

Height:__________

Sex:_____________

Body Fat Content:__

Requirement (SR,
with Tolerances):

Subject 1:

Weight:__________

Height:__________

Sex:_____________

Body Fat Content:__

Water Content:_____

Subject 2:

Weight:__________

Height:__________

Sex:_____________

Body Fat Content:__

Test Equipment
Error:

n/a

Adjusted Test Limit:

n/a

Water Content:_____

Subject 3:

Weight:__________

Height:__________

Sex:_____________

Body Fat Content:__

Water Content:_____

Subject 4:

Weight:__________

Height:__________

Sex:_____________

Body Fat Content:__

Water Content:_____

Subject 5:

Weight:__________

Height:__________

Sex:_____________

Body Fat Content:__

Water Content:_____

Water Content:_____

Subject 3:

Weight:__________

Height:__________

Sex:_____________

Body Fat Content:__

Water Content:_____

Subject 4:

Weight:__________

Height:__________

Sex:_____________

Body Fat Content:__

Water Content:_____

Subject 5:

Weight:__________

Height:__________

Sex:_____________

Body Fat Content:__

Water Content:_____

Computations, (Include Analyses Results, if any): none

Signatures:

Tester: _________________

Witness:_______________

4.8.2 Skin Impedance Module Accuracy Acceptance Test Data Sheet

Reference ATP Paragraph Number: 4.6.2

Analysis Referenced (for verification by T/A): none

Name of Test: Skin Impedance Module Accuracy

Unit Under Test (UUT):
Name: Skin Impedance Assy
Part Number: 100600
Serial Number: n/a
Results (Pass / Fail): | Date of Test:

Recording of Test
Measurement:

Subject 1:

Weight:__________

Height:__________

Sex:_____________

Body Fat Content:__

Water Content:_____

Subject 2:

Weight:__________

Height:__________

Sex:_____________

Body Fat Content:__

Water Content:_____

Subject 3:

Requirement (SR,
with Tolerances):

Subject 1:

Weight:__________

Height:__________

Sex:_____________

Body Fat Content:__

Water Content:_____

Subject 2:

Weight:__________

Height:__________

Sex:_____________

Body Fat Content:__

Water Content:_____

Subject 3:

Test Equipment
Error:

n/a

Adjusted Test Limit:

n/a

Weight:__________

Height:__________

Sex:_____________

Body Fat Content:__

Water Content:_____

Subject 4:

Weight:__________

Height:__________

Sex:_____________

Body Fat Content:__

Water Content:_____

Subject 5:

Weight:__________

Height:__________

Sex:_____________

Body Fat Content:__

Water Content:_____

Weight:__________

Height:__________

Sex:_____________

Body Fat Content:__

Water Content:_____

Subject 4:

Weight:__________

Height:__________

Sex:_____________

Body Fat Content:__

Water Content:_____

Subject 5:

Weight:__________

Height:__________

Sex:_____________

Body Fat Content:__

Water Content:_____

Computations, (Include Analyses Results, if any): none

Signatures:

Tester: _________________

Witness:_______________
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

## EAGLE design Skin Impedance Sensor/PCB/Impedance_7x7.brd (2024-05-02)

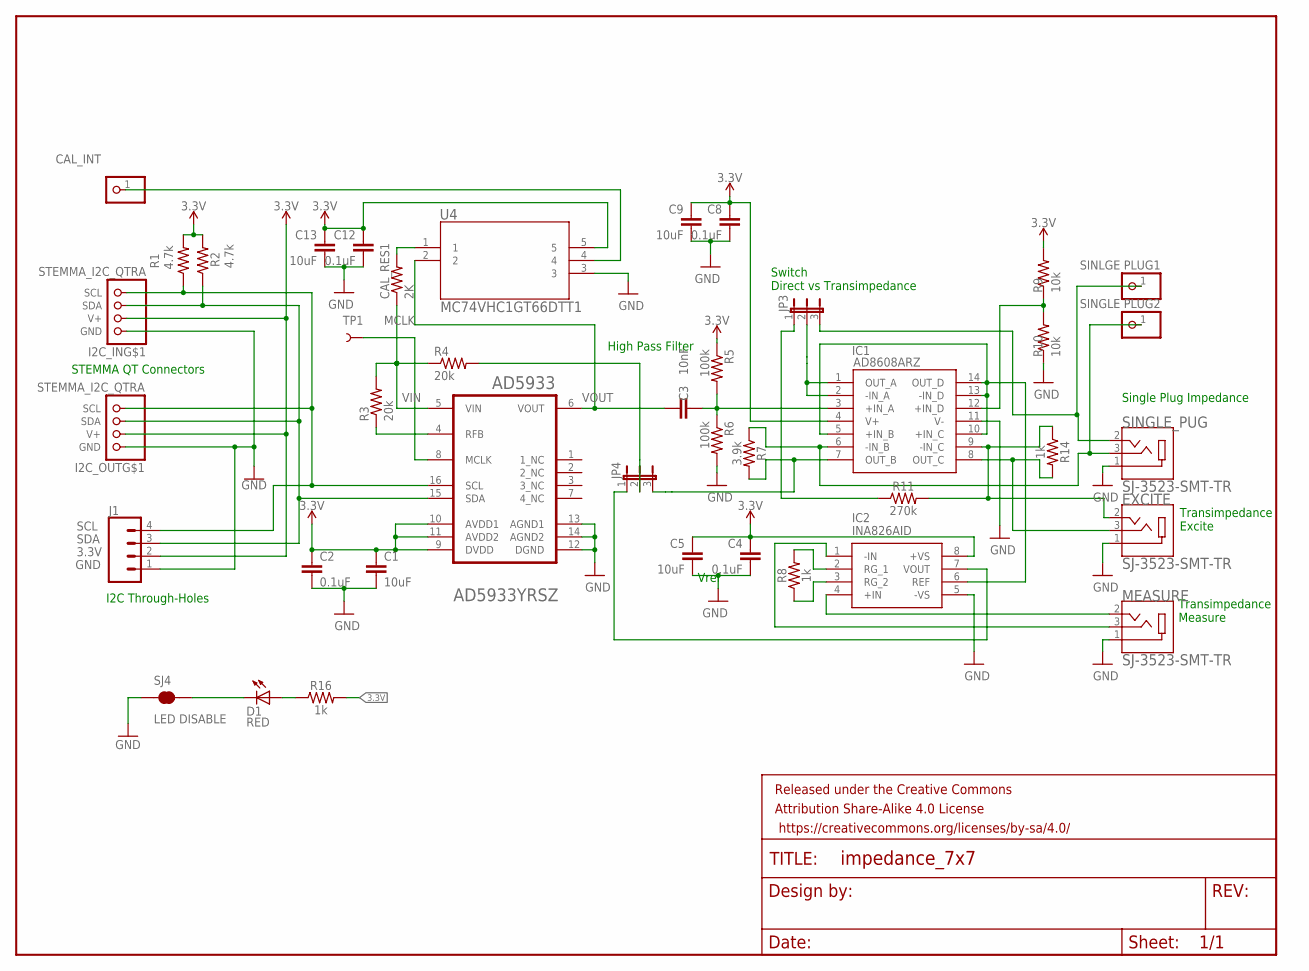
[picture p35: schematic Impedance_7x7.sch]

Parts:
AD5933: ANALOG_DEVICES_AD5933YRSZANALOG_DEVICES_AD5933YRS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; ANALOG_DEVICES_AD5933YRSZ_0
C1, C5, C9, C13: 10uF; C0603
C2, C4, C8, C12: 0.1uF; C0603
C3: 10nF; 0603
CAL_INT: PINHD-1X1; 1X01
CAL_RES1: 2K; R0603
D1: RED; LED-0603
EXCITE: SJ-3523-SMT-TR; CUI_SJ-3523-SMT-TR
FRAME1: FRAME-LETTERNO_PACKAGE; DUMMY
I2C_IN, I2C_OUT: STEMMA_I2C_QTRA; JST_SH4_RA
IC1: AD8608ARZ; SOIC127P600X175-14N
IC2: INA826AID; SOIC127P600X175-8N
J1: CONN_04; 1X04
JP3, JP4: JP2E; JP2
MEASURE: SJ-3523-SMT-TR; CUI_SJ-3523-SMT-TR
R1, R2: 4.7k; 0603
R3, R4: 20k; 0603
R5, R6: 100k; 0603
R7: 3.9k; 0603
R8, R14, R16: 1k; 0603
R9, R10: 10k; 0603
R11: 270k; 0603
SINGLE_PLUG1: SINLGE PLUG1; 1X01
SINGLE_PLUG2: SINGLE PLUG2; 1X01
SINGLE_PUG: SJ-3523-SMT-TR; CUI_SJ-3523-SMT-TR
SJ4: LED DISABLE; SMT-JUMPER_2_NC_TRACE_NO-SILK
TP1: TEST-POINT3X5; PAD.03X.05
U4: MC74VHC1GT66DTT1; TSOP5_1P65X3P15_ONS

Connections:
3.3V: AD5933.9 (DVDD), AD5933.10 (AVDD1), AD5933.11 (AVDD2), C1.1, C2.1, C4.1, C5.1, C8.1, C9.1, C12.1, C13.1, I2C_IN.2 (V+), I2C_OUT.2 (V+), IC1.4 (V+), IC2.8 (+VS), J1.2, R1.2, R2.2, R5.1, R9.2, R16.2, U4.5
GND: AD5933.12 (DGND), AD5933.13 (AGND1), AD5933.14 (AGND2), C1.2, C2.2, C4.2, C5.2, C8.2, C9.2, C12.2, C13.2, EXCITE.1, I2C_IN.1 (GND), I2C_OUT.1 (GND), IC1.11 (V-), IC2.5 (-VS), J1.1, MEASURE.1, R6.2, R10.1, SINGLE_PUG.1, SJ4.1, U4.3
MCLK: AD5933.8 (MCLK), TP1.P$1
unnamed: IC1.6 (-IN_B), R7.1, SINGLE_PLUG2.1, SINGLE_PUG.3
unnamed: CAL_INT.1, U4.4
unnamed: IC1.7 (OUT_B), JP4.3, R7.2
unnamed: JP4.2, R4.2
unnamed: AD5933.4 (RFB), R3.1
unnamed: C3.2, IC1.3 (+IN_A), R5.2, R6.1
unnamed: JP3.3, SINGLE_PLUG1.1, SINGLE_PUG.2
unnamed: JP3.1, R11.1
unnamed: IC1.1 (OUT_A), IC1.2 (-IN_A), JP3.2
unnamed: IC2.7 (VOUT), JP4.1
unnamed: IC1.12 (+IN_D), R9.1, R10.2
unnamed: IC1.5 (+IN_B), IC1.10 (+IN_C), IC1.13 (-IN_D), IC1.14 (OUT_D), IC2.6 (REF)
unnamed: EXCITE.2, IC1.9 (-IN_C), R11.2, R14.1
unnamed: IC2.4 (+IN), MEASURE.2
unnamed: IC2.1 (-IN), MEASURE.3
unnamed: IC2.2 (RG_1), R8.2
unnamed: IC2.3 (RG_2), R8.1
unnamed: CAL_RES1.2, U4.1
unnamed: EXCITE.3, IC1.8 (OUT_C), R14.2
unnamed: D1.A, R16.1
unnamed: D1.C, SJ4.2
SCL: AD5933.16 (SCL), I2C_IN.4 (SCL), I2C_OUT.4 (SCL), J1.4, R1.1
SDA: AD5933.15 (SDA), I2C_IN.3 (SDA), I2C_OUT.3 (SDA), J1.3, R2.1
VIN: AD5933.5 (VIN), CAL_RES1.1, R3.2, R4.1
VOUT: AD5933.6 (VOUT), C3.1, U4.2

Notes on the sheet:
High Pass Filter
Vref
Transimpedance Measure
Transimpedance Excite
Single Plug Impedance
STEMMA QT Connectors
I2C Through-Holes
Switch Direct vs Transimpedance

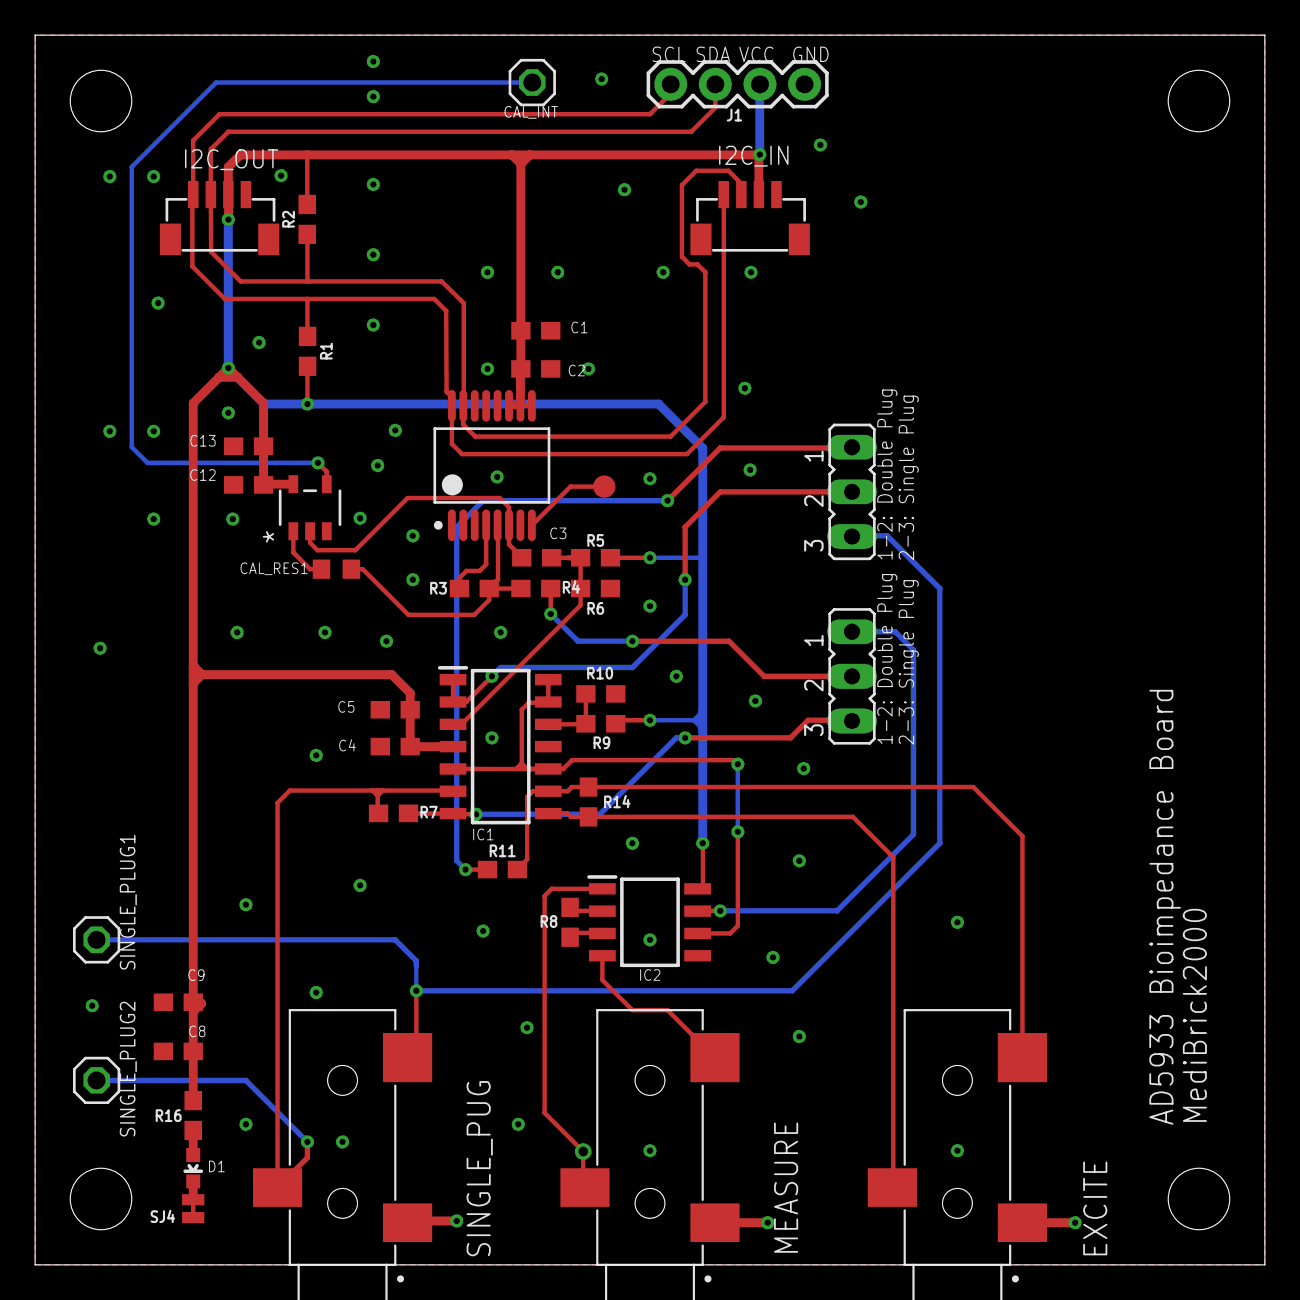
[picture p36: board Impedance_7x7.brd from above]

Board: 2 copper layers, 70.0 x 70.0 mm, 42 parts (0 on the bottom side), 28 nets.

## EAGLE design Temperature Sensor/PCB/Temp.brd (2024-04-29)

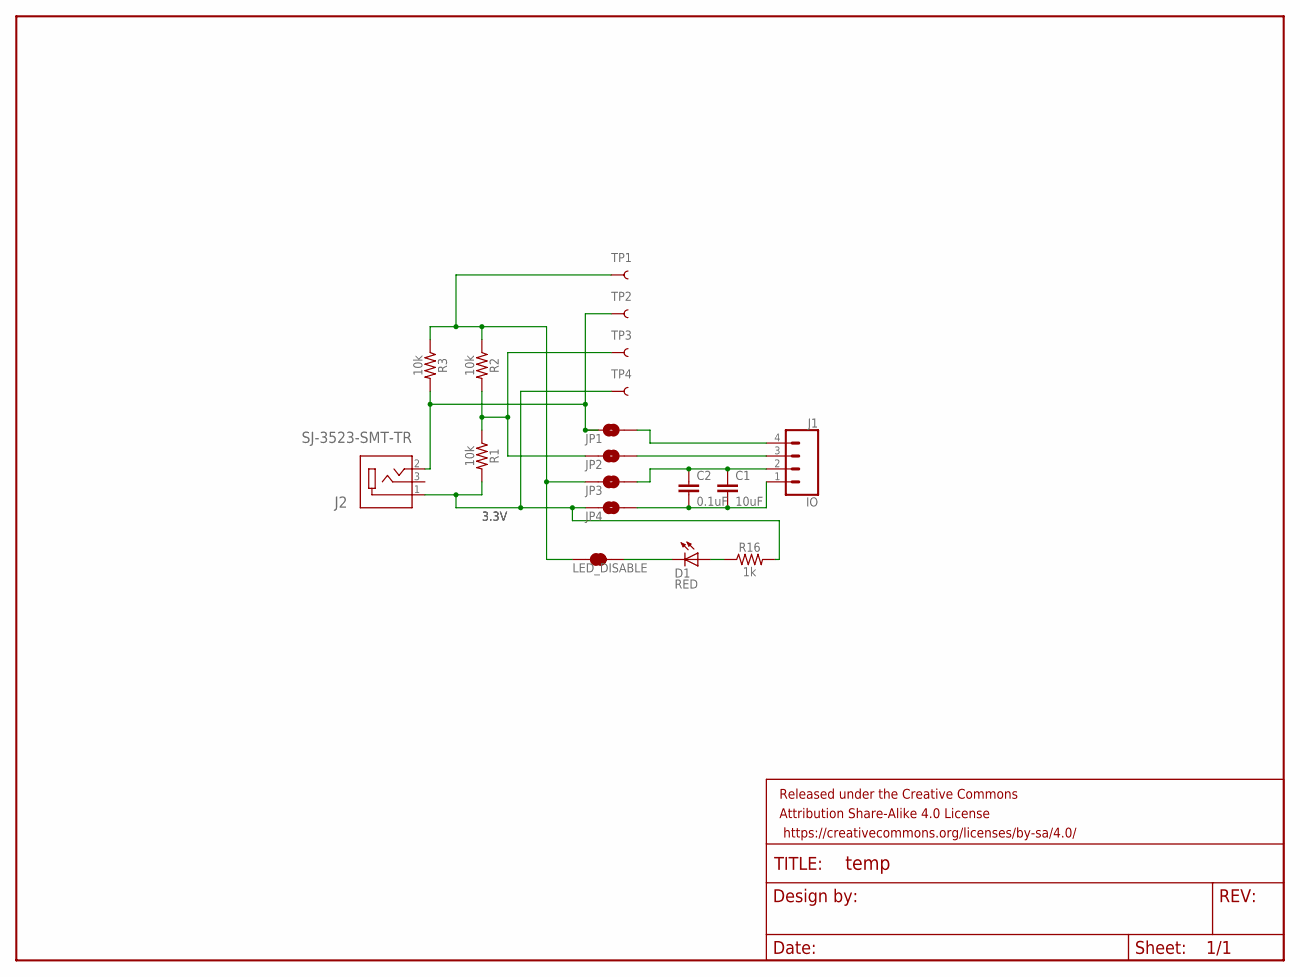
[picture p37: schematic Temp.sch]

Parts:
C1: 10uF; 0603
C2: 0.1uF; 0603
D1: RED; LED-0603
FRAME1: FRAME-LETTERNO_PACKAGE; DUMMY
J1: IO; 1X04
J2: SJ-3523-SMT-TR; CUI_SJ-3523-SMT-TR
JP1, JP2, JP3, JP4: JUMPER-SMT_2_NO_NO-SILK; SMT-JUMPER_2_NO_NO-SILK
LED_DISABLE: JUMPER-SMT_2_NC_TRACE_SILK; SMT-JUMPER_2_NC_TRACE_SILK
R1, R2, R3: 10k; 0603
R16: 1k; 0603
TP1, TP2, TP3, TP4: TEST-POINT3X5; PAD.03X.05

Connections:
3.3V: J2.1, JP4.1, R1.2, R16.2, TP4.P$1
unnamed: JP3.1, LED_DISABLE.1, R2.1, R3.1, TP1.P$1
unnamed: C1.2, C2.2, J1.1, JP4.2
unnamed: JP2.1, R1.1, R2.2, TP3.P$1
unnamed: C1.1, C2.1, J1.2, JP3.2
unnamed: J1.3, JP2.2
unnamed: J2.2, JP1.1, R3.2, TP2.P$1
unnamed: J1.4, JP1.2
unnamed: D1.A, R16.1
unnamed: D1.C, LED_DISABLE.2

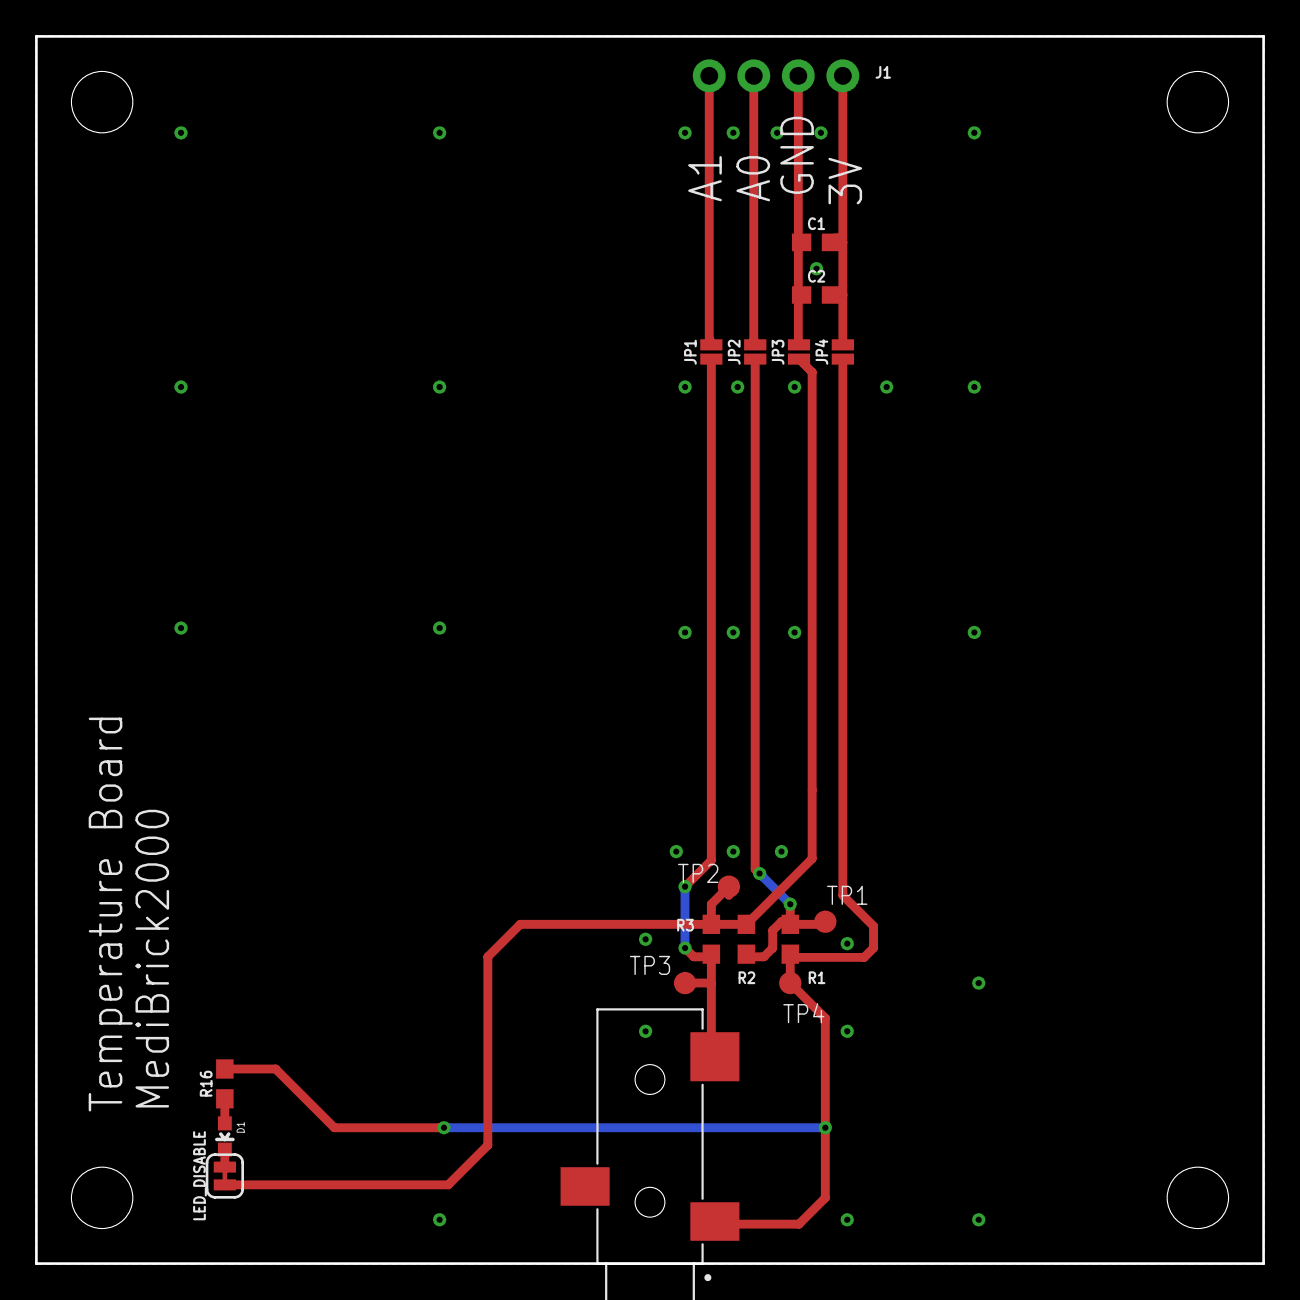
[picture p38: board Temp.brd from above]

Board: 2 copper layers, 70.0 x 70.0 mm, 19 parts (1 on the bottom side), 10 nets.

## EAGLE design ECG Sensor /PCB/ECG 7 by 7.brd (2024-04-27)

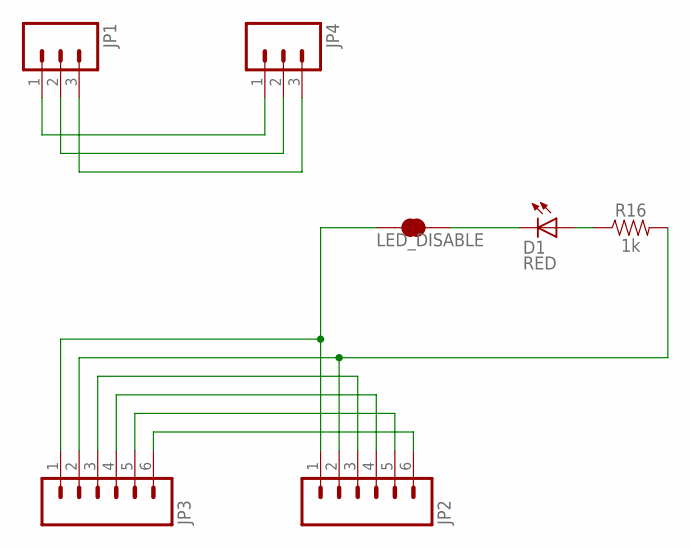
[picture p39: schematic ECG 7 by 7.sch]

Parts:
D1: RED; LED-0603
JP1, JP4: M03PTH; 1X03
JP2, JP3: M06SIP; 1X06
LED_DISABLE: JUMPER-SMT_2_NC_TRACE_SILK; SMT-JUMPER_2_NC_TRACE_SILK
R16: 1k; 0603

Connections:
unnamed: JP1.1, JP4.1
unnamed: JP1.2, JP4.2
unnamed: JP1.3, JP4.3
unnamed: JP2.6, JP3.6
unnamed: JP2.5, JP3.5
unnamed: JP2.4, JP3.4
unnamed: JP2.3, JP3.3
unnamed: JP2.2, JP3.2, R16.2
unnamed: JP2.1, JP3.1, LED_DISABLE.1
unnamed: D1.A, R16.1
unnamed: D1.C, LED_DISABLE.2

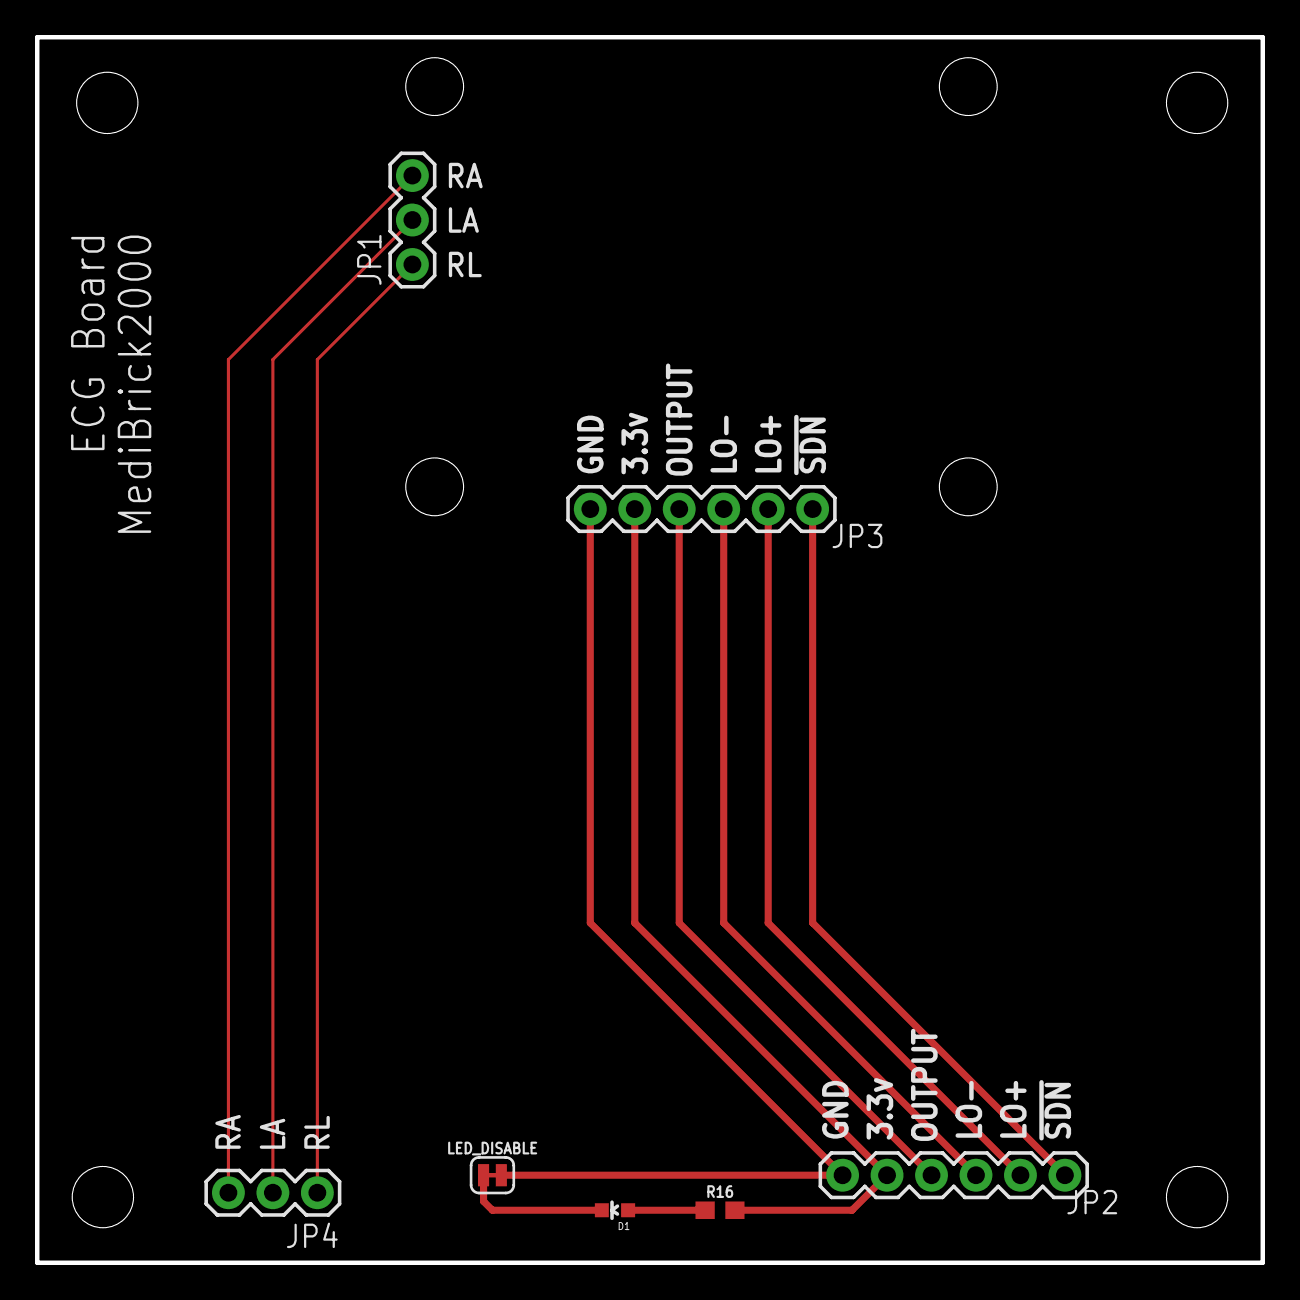
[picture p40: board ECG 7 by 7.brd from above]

Board: 2 copper layers, 70.0 x 70.0 mm, 11 parts (0 on the bottom side), 11 nets.

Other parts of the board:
STANDOFF1, STANDOFF2, STANDOFF3, STANDOFF4: STAND-OFF

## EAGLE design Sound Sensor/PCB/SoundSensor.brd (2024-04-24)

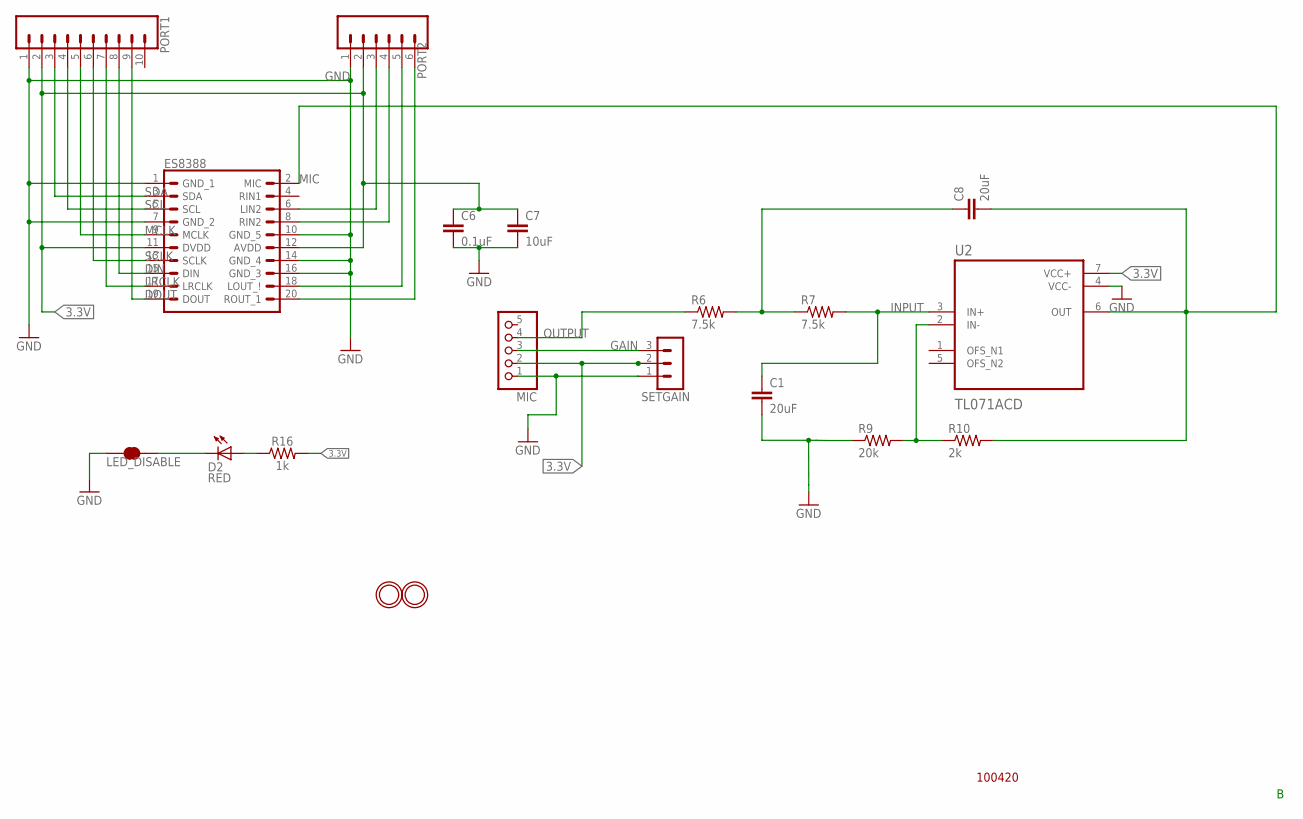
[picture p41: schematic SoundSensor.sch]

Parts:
C1, C8: 20uF; C0603
C6: 0.1uF; C0603
C7: 10uF; C0603
D2: RED; LED-0603
ES8388: ES8388ES8388; ES8388
LED_DISABLE: JUMPER-SMT_2_NC_TRACE_SILK; SMT-JUMPER_2_NC_TRACE_SILK
MIC: HEADER-1X576MIL; 1X05_ROUND_76
PORT1: CONN_10"; 1X10
PORT2: CONN_06SILK_FEMALE_PTH; 1X06
R6, R7: 7.5k; R0603
R9: 20k; R0603
R10: 2k; R0603
R16: 1k; 0603
SETGAIN: MA03-1
U2: TL071ACD; SOIC127P599X175-8N
U$1, U$5: MOUNTINGHOLE2.0; MOUNTINGHOLE_2.0_PLATED

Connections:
3.3V: C6.1, C7.1, ES8388.11 (DVDD), ES8388.12 (AVDD), MIC.2, PORT1.2, PORT2.2, R16.2, SETGAIN.2, U2.7 (VCC+)
DIN: ES8388.15 (DIN), PORT1.8
DOUT: ES8388.19 (DOUT), PORT1.9
GAIN: MIC.3, SETGAIN.3
GND: C1.2, C6.2, C7.2, ES8388.1 (GND_1), ES8388.7 (GND_2), ES8388.10 (GND_5), ES8388.14 (GND_4), ES8388.16 (GND_3), LED_DISABLE.1, MIC.1, PORT1.1, PORT2.1, R9.1, SETGAIN.1, U2.4 (VCC-)
INPUT: C1.1, R7.2, U2.3 (IN+)
LRCLK: ES8388.17 (LRCLK), PORT1.7
MCLK: ES8388.9 (MCLK), PORT1.5
MIC: C8.2, ES8388.2 (MIC), R10.2, U2.6 (OUT)
unnamed: ES8388.6 (LIN2), PORT2.3
unnamed: ES8388.8 (RIN2), PORT2.4
unnamed: ES8388.18 (LOUT_!), PORT2.5
unnamed: ES8388.20 (ROUT_1), PORT2.6
unnamed: C8.1, R6.2, R7.1
unnamed: R9.2, R10.1, U2.2 (IN-)
unnamed: D2.A, R16.1
unnamed: D2.C, LED_DISABLE.2
OUTPUT: MIC.4, R6.1
SCL: ES8388.5 (SCL), PORT1.4
SCLK: ES8388.13 (SCLK), PORT1.6
SDA: ES8388.3 (SDA), PORT1.3

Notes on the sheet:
100420

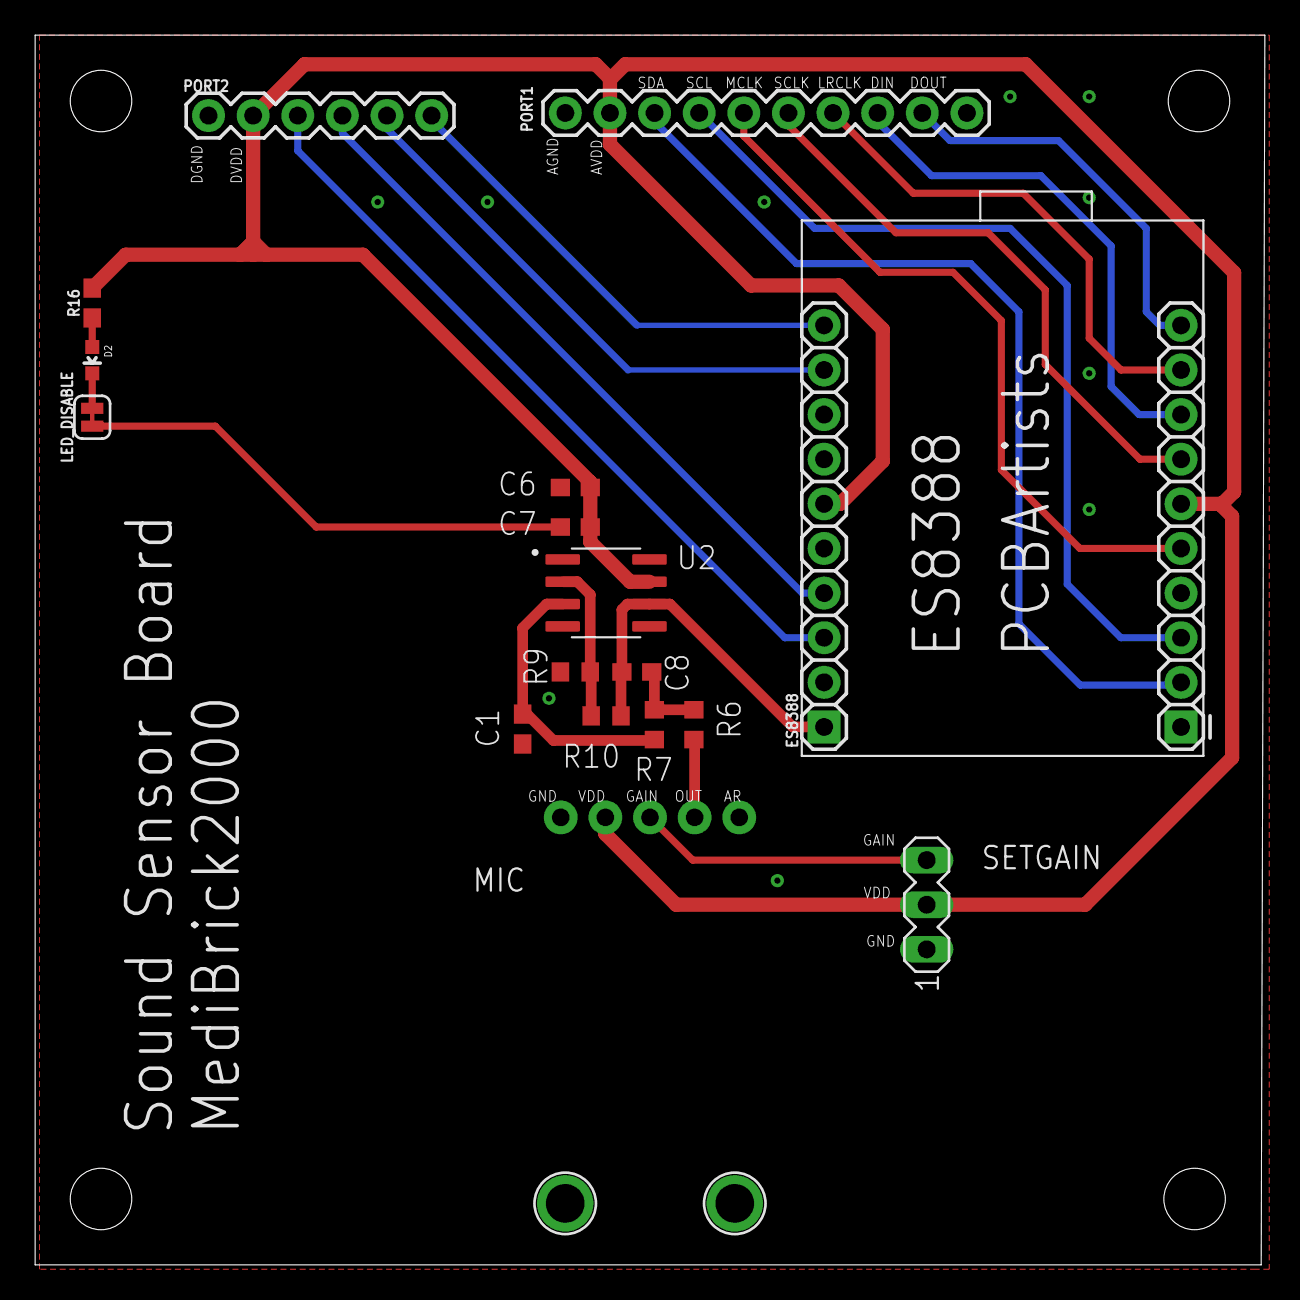
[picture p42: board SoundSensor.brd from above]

Board: 2 copper layers, 70.0 x 70.0 mm, 19 parts (0 on the bottom side), 21 nets.

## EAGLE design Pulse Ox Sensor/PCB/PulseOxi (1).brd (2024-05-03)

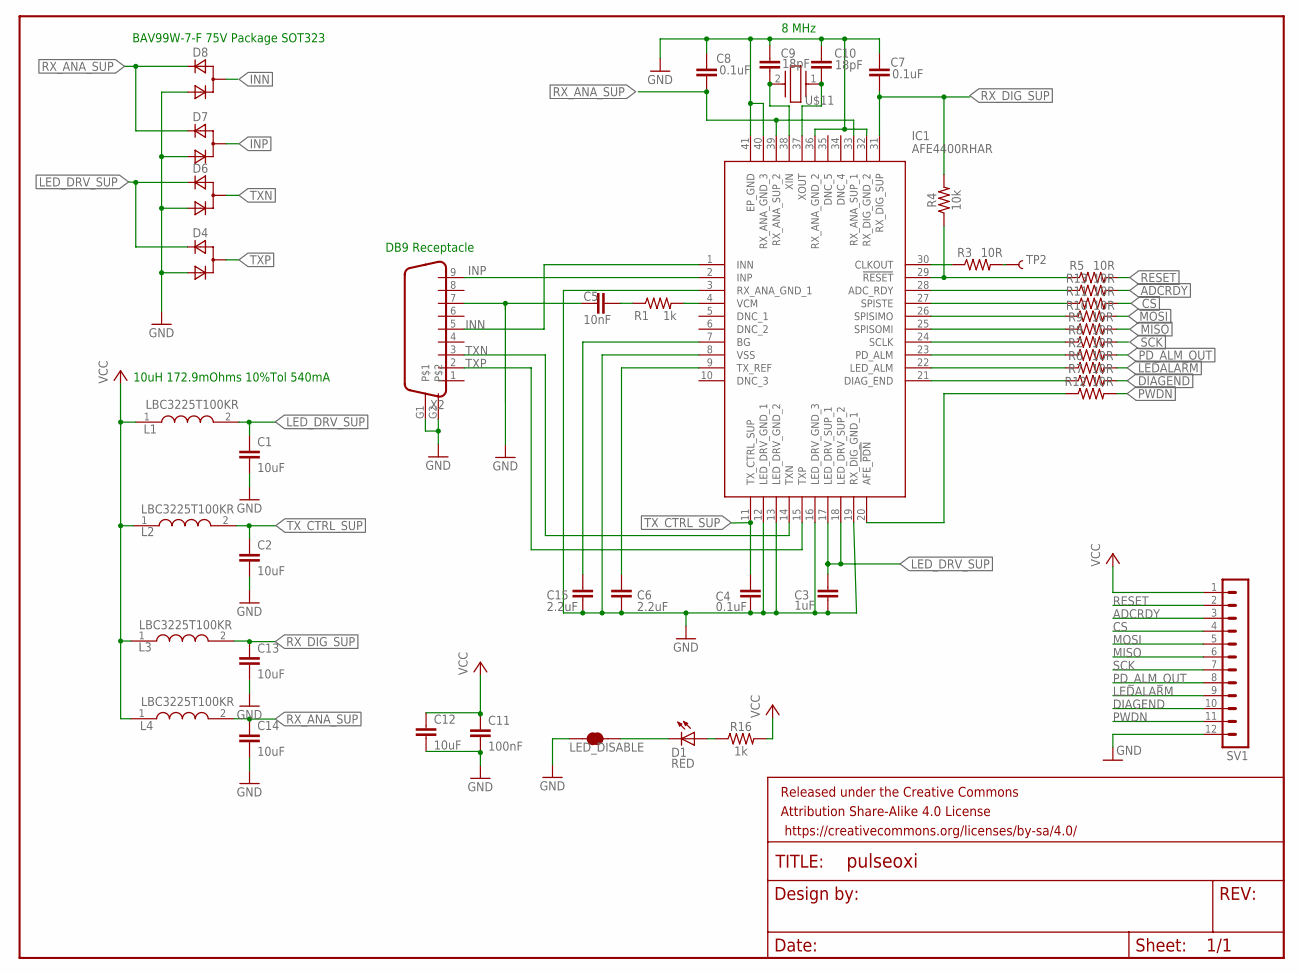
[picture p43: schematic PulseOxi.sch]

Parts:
C1, C2, C12, C13, C14: 10uF; 0603
C3: 1uF; 0603
C4, C7, C8: 0.1uF; 0603
C5: 10nF; 0603
C6, C15: 2.2uF; 0603
C9, C10: 18pF; 0603
C11: 100nF; 0603
D1: RED; LED-0603
D4, D6, D7, D8: D_ACACSOT323; SOT323
FRAME1: FRAME-LETTERNO_PACKAGE; DUMMY
IC1: AFE4400RHAR; QFN50P600X600X100-41N
L1, L2, L3, L4: LBC3225T100KR; INDC3225X270N
LED_DISABLE: JUMPER-SMT_2_NC_TRACE_SILK; SMT-JUMPER_2_NC_TRACE_SILK
R1, R16: 1k; 0603
R2, R3, R5, R6, R7, R8, R9, R10, R11, R12, R13: 10R; 0603
R4: 10k; 0603
SV1: MA12-1
TP2: TEST-POINT3; PAD.03X.03
U$11: ABM3-8.000MHZ-D2Y-T; ABM3
X2: DB9

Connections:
ADCRDY: R13.2, SV1.3
AFE_PWDN: IC1.20 (AFE_!PDN), R12.1
CS: R11.2, SV1.4
DIAGEND: R7.2, SV1.10
GND: C1.2, C2.2, C3.2, C4.2, C5.2, C6.2, C7.2, C8.2, C9.2, C10.2, C11.2, C12.2, C13.2, C14.2, C15.2, D4.2 (C), D6.2 (C), D7.2 (C), D8.2 (C), IC1.3 (RX_ANA_GND_1), IC1.8 (VSS), IC1.12 (LED_DRV_GND_1), IC1.13 (LED_DRV_GND_2), IC1.16 (LED_DRV_GND_3), IC1.19 (RX_DIG_GND_1), IC1.32 (RX_DIG_GND_2), IC1.36 (RX_ANA_GND_2), IC1.40 (RX_ANA_GND_3), IC1.41 (EP_GND), LED_DISABLE.1, SV1.12, X2.7, X2.G1, X2.G2
INN: D8.1 (CA), IC1.1 (INN), X2.5
INP: D7.1 (CA), IC1.2 (INP), X2.9
LEDALARM: R6.2, SV1.9
LED_DRV_SUP: C1.1, C3.1, D4.3 (A), D6.3 (A), IC1.17 (LED_DRV_SUP_1), IC1.18 (LED_DRV_SUP_2), L1.2
MISO: R9.2, SV1.6
MOSI: R10.2, SV1.5
unnamed: R3.2, TP2.P$1
unnamed: IC1.30 (CLKOUT), R3.1
unnamed: IC1.29 (!RESET), R4.1, R5.1
unnamed: C15.1, IC1.7 (BG)
unnamed: C5.1, R1.1
unnamed: C6.1, IC1.9 (TX_REF)
unnamed: IC1.28 (ADC_RDY), R13.1
unnamed: IC1.21 (DIAG_END), R7.1
unnamed: IC1.22 (LED_ALM), R6.1
unnamed: IC1.23 (PD_ALM), R2.1
unnamed: IC1.24 (SCLK), R8.1
unnamed: IC1.25 (SPISOMI), R9.1
unnamed: IC1.26 (SPISIMO), R10.1
unnamed: IC1.27 (SPISTE), R11.1
unnamed: C9.1, IC1.38 (XIN), U$11.2
unnamed: IC1.4 (VCM), R1.2
unnamed: C10.1, IC1.37 (XOUT), U$11.1
unnamed: D1.A, R16.1
unnamed: D1.C, LED_DISABLE.2
PD_ALM_OUT: R2.2, SV1.8
PWDN: R12.2, SV1.11
RESET: R5.2, SV1.2
RX_ANA_SUP: C8.1, C14.1, D7.3 (A), D8.3 (A), IC1.33 (RX_ANA_SUP_1), IC1.39 (RX_ANA_SUP_2), L4.2
RX_DIG_SUP: C7.1, C13.1, IC1.31 (RX_DIG_SUP), L3.2, R4.2
SCK: R8.2, SV1.7
TXN: D6.1 (CA), IC1.14 (TXN), X2.3
TXP: D4.1 (CA), IC1.15 (TXP), X2.2
TX_CTRL_SUP: C2.1, C4.1, IC1.11 (TX_CTRL_SUP), L2.2
VCC: C11.1, C12.1, L1.1, L2.1, L3.1, L4.1, R16.2, SV1.1

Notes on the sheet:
BAV99W-7-F 75V Package SOT323
10uH 172.9mOhms 10%Tol 540mA
8 MHz
DB9 Receptacle

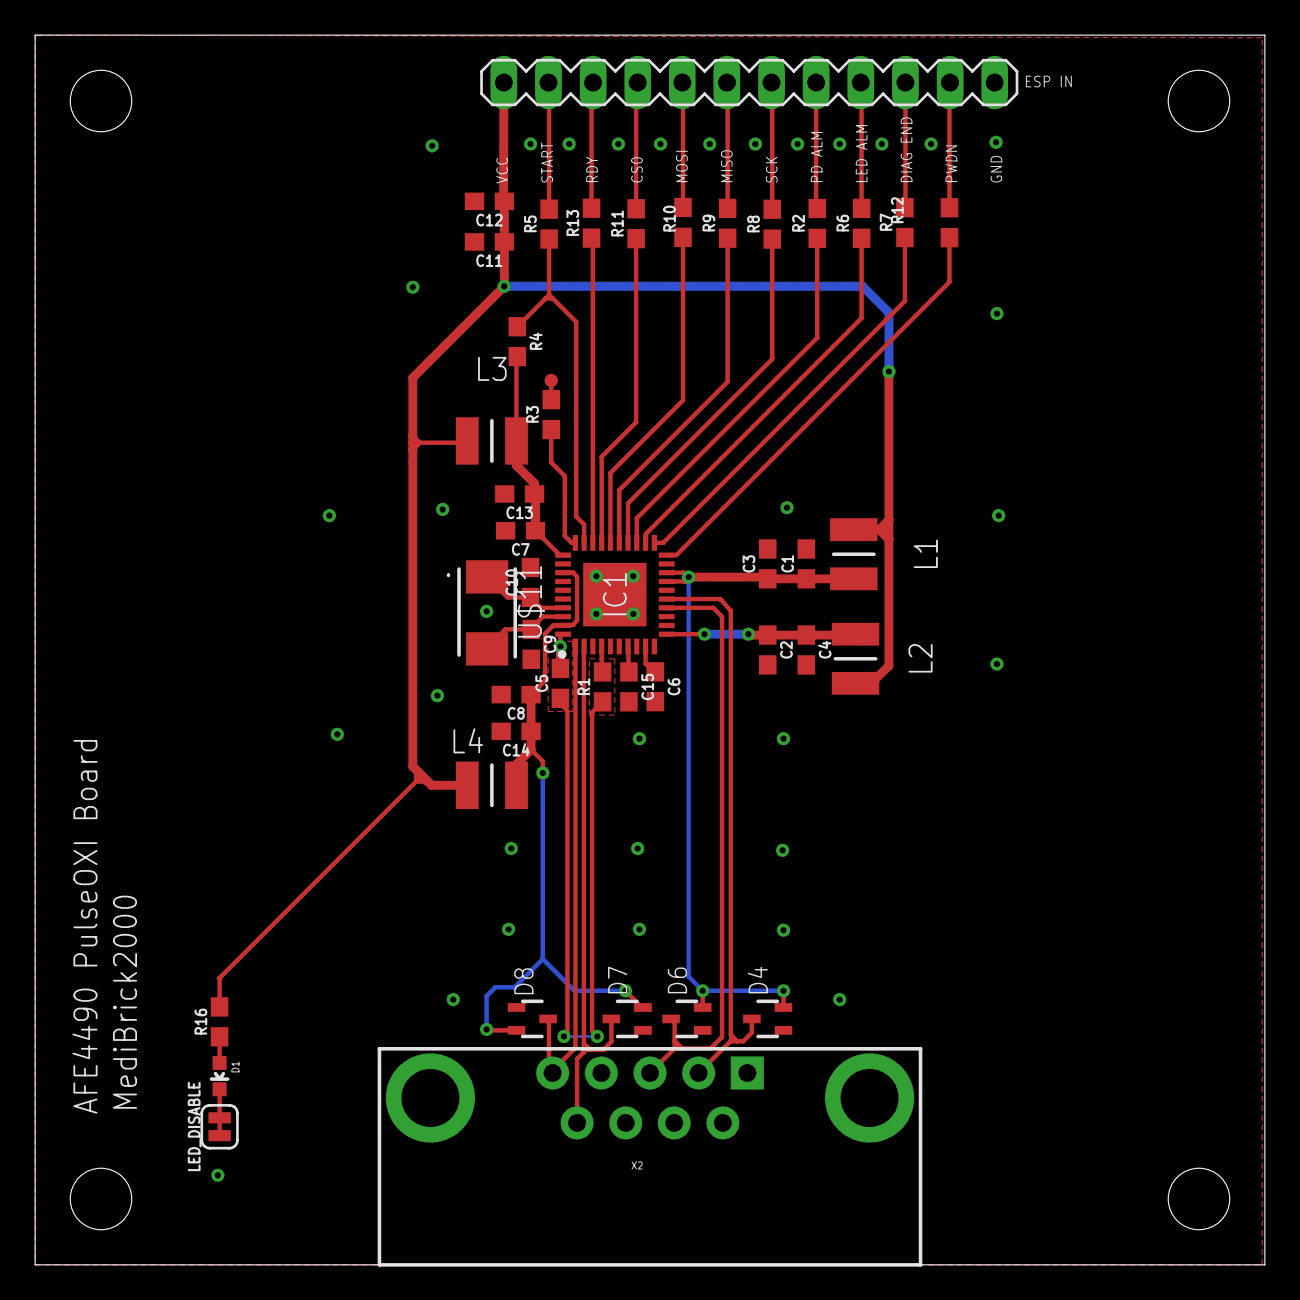
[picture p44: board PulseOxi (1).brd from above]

Board: 2 copper layers, 70.0 x 70.0 mm, 45 parts (0 on the bottom side), 40 nets.

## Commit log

2024-04-25 Add files via upload
    ECG ESP32 Sender Code
2024-05-03 Add files via upload
    bill of materials
    [T-2P2W699447A-5sets-Pulseoxi+bill(2024-03-08) (1).xls]

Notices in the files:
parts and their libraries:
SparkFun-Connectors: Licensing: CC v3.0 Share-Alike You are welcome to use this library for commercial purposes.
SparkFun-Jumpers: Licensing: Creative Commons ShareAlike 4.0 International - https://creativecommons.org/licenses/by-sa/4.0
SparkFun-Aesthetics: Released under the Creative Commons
